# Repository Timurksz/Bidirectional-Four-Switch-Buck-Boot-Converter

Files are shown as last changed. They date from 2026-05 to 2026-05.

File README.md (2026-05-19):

This repository contains the design files and documentation for a 100W Bidirectional Four Switch Buck-Boost (FSBB) Converter, digitally controlled by the Texas Instruments UCD3138 microprocessor.

Featuring bidirectional energy transfer, this converter is ideal for battery management systems (BMS), automotive applications (48V/12V dual-battery systems), and renewable energy setups.

Project Overview

The topology is based on a non-isolated synchronous four-switch buck-boost converter, capable of operating in two primary modes:
- Buck Mode (48V → 12V): The high-voltage side supplies the low-voltage load.
- Boost Mode (12V → 48V): The low-voltage source transfers energy back to the 48V bus.

The system is digitally controlled using the UCD3138 microprocessor, enabling:
- Closed-loop voltage regulation
- PWM generation
- Bidirectional mode management
- Protection algorithms
- Real-time monitoring

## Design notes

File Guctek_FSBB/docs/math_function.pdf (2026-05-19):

Matematiksel Gösterimi

Klasik kontrol yöntemlerinde sistemler transfer fonksiyonları üzerinden analiz edilir. Ancak bu

yaklaşım, sistemin başlangıçtaki enerji durumunu (başlangıç koşullarını) sıfır kabul eder ve

yalnızca giriş-çıkış ilişkisine odaklanır. Gerçek dünyadaki karmaşık sistemlerde, sistemin iç

dinamiklerini ve başlangıçtaki fiziksel durumlarını hesaba katmak hayati önem taşır. Modern

kontrol teorisi, sistemi dışarıdan gözlemlemek yerine, sistemin içsel mekanizmalarını (iç

değişkenleri) matematiksel modele dahil ederek bu eksikliği giderir. Modern kontrolün

temelini, yüksek dereceli karmaşık denklemleri yönetilebilir parçalara ayırmak oluşturur. n.

dereceden bir diferansiyel denklemle ifade edilen bir sistem, modern teoride n adet birinci

dereceden diferansiyel denkleme dönüştürülür. Bu yapı, doğrusal dinamik sistemlerin vektör-

matris formunda gösterilmesini sağlar. Böylece durum uzay modeli vektör matris dormunda;

ⅆx
ⅆt
= Ax(t) + Bu(t) | (1)

yazılırlar. Çıkış denklemi ise;
y(t) = Cx(t) + Du(t) | (2)
ile verilir. Anxn, Bnxr, Cmxn, Dmxr | zamanla değişmeyen sistemler için sabit katsayı

matrisleridir. xnx1 durum vektörüdür. u(t) giriş/kontrol işaretidir. y(t) ise sistemin çıkış

vektörüdür. n. dereceden sistem analiz ve tasarımı bu denklem takımları üzerinden

yapılır. Modern kontrol teorisi olarak isimlendirilme nedeni olarak kısaca, durum uzay

denklemleri kullanılarak yapılan analiz ve tasarımlarda özellikle lineer cebir teknik ve

yöntemlerinin çok yaygın olarak kullanılması ve sürekli olarak geliştirilmesidir. Durum-

uzay analizinde dinamik sistem modellemesinde üç tip değişken göz önünde

bulundurulur:

- Giriş değişkenleri,
- Çıkış değişkenleri,
- Durum değişkenleri/İç değişkenler

Aynı bir sistem için tek bir durum-uzay gösterimi yoktur. Durum değişken sayısı aynı

kalmakla beraber aynı sistem için sonsuz sayıda durum-uzay gösterimi elde edilebilir. Bir

sisteme ait durum uzay gösterimi elde edilirken kullanılan yöntemlere ve kullanılabilecek

lineer dönüşümlere bağlı olarak farklı katsayılar matrisleri elde edilir. Ancak aynı bir

sistem için katsayılar matrisleri farklı olmakla beraber tek bir transfer fonksiyonu vardır

ve karakteristik denklemleri aynıdır. Eğer durum denklem elde etme yöntemi veya lineer

dönüşüm sonunda transfer fonksiyonu veya karakteristik denklem değişir ise o sistem artık farklı bir sistem demektir, hata yapılmıştır. Bu bilgiler göz önüne alınarak devre

analizi yapılır.

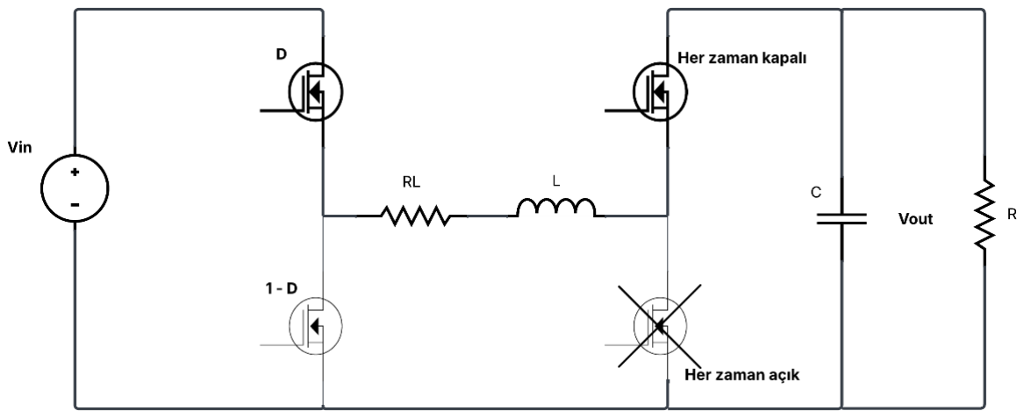
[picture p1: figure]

Şekil 1: Düşürücü Dönüştürücünün Anahtarı İletimde

Düşürücü devreden yapılan analizinden ve alınan Kirchhoff Çevre Gerilim Yasası’ndan;

Vin = lL ⋅ RL + L

ⅆIL
ⅆt
+ IR ⋅ R | (3)

olarak elde edilir. Kapasitör akımının da;

IC = C

ⅆVC ⅆt | (4)

olduğunu bilinmktedir. Vout ve VC parallel olduklarından dolayı eşittir ve;

VC = IR ⋅ R | (5)

veya

IR =

VC R | (6)

olarak yazılabilir Kirchhoff Düğüm Akım Yasası;
IR = IL − IC | (7)

elde edilir. Dolayısıyla kapasitor gerilimi;

C

ⅆVC ⅆt
= IL −
VC R | (8)

ⅆVC ⅆt
=

IL C
−
VC RC | (9)

olacaktır. Endüktör akımı ise;

L

ⅆIL
ⅆt
= Vin − lL ⋅ RL − VC | (10)

ⅆIL ⅆt
=

Vin L
−

lL⋅RL L
−
VC L | (11)

şeklinde olacaktır. Ve çıkış gerilimi de;

vout = VC | (12)

şeklinde olacaktır. Dolayısıyla sistem iletimde olduğu sürece;

[
ⅆIL
ⅆt
ⅆVC
ⅆt

] = [
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
RC] ⋅ [
IL
vc

] + [

1
L
0
] ⋅ Vin | (13)

ve
vout = y = [0 1][

IL
vc
] | (14)

ifadeleri elde edilir.

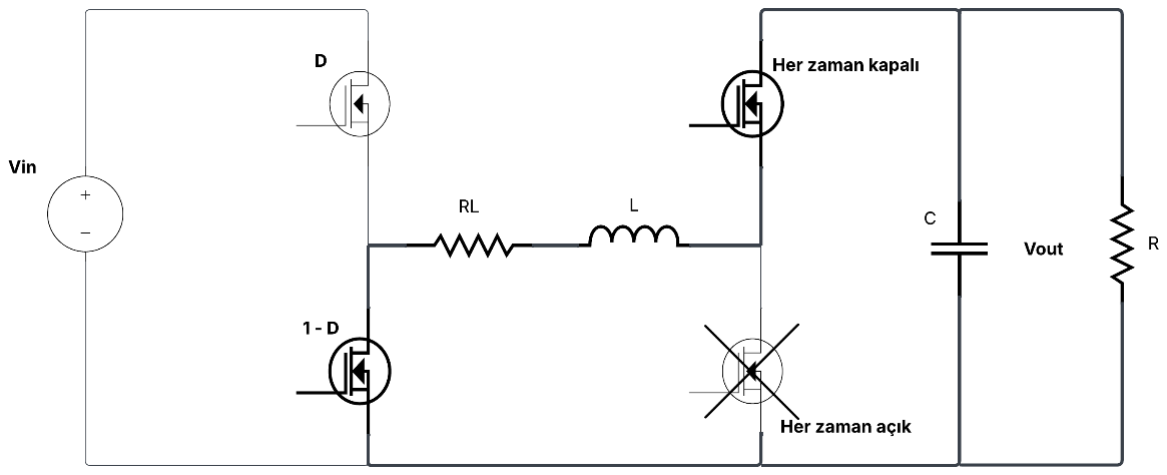
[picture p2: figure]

Sekil 2: Düşürücü Dönüştürücünün Anahtarı kesimde

Anahtarın kesime gittğinde ise Vin = 0 olup endüktör akımı;

ⅆIL
ⅆt

= −

lL⋅RL
L

−

VC
L

(15)

olarak, kapasitör gerilimi ise;

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
(16)

olarak elde edilir. Dolayısıyla;
[
ⅆIL
ⅆt
ⅆVC
ⅆt

] = [
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
RC] ⋅ [
IL
vc

] + [

0
0
] ⋅ Vin | (17)

ve
vout = y = [0 1][

IL
vc
] | (18)

ifadeleri elde edilir. Şimdi ise bu iki durum uzay modelinin ortalama bir model elde etmek için

bazı işlemlerin yapılması gerekmektedir.

Anahtarın iletimde olduğu ifadeleri d(t) ile, kesimde olduğu ifadeleri ise (1-d(t)) ile çarpıp

ardından ortalama durum uzay modeli çıkarılır. Iki durumların da çarpıldığı ve ortalama uzay

modeli çıkarıldığı zaman, aşağıdaki ortalama durum uzay modeli;
[
ⅆIL
ⅆt
ⅆVC
ⅆt

] = [
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
RC] ⋅ [
IL
vc

] + [

ⅆ(t)
L
0
] ⋅ Vin | (19)

ve
vout = y = [0 1][

IL
vc
] | (20)

olarak elde edilir. Her iki ifadenin çarpılıp topladıktan sonra, d(t) ve (1-d(t)) ifadelerin içinde

birbirlerini sadeleşmiş olacak. Anahtarın kesimde olduğuna Vin = 0 olacağı için, ortalama

durum uzay modelinde B matrisinin içerisinde ⅆ(t)
L

ifadesi kalacaktır.

Elde edilen ortalama durum uzay modelinde B matrisinin içerisinde d(t) değişkeni vardır.

Dolayısıyla bu değişken sabit olmadığında bu modeli doğrusal olmayan bir model yapar. Böyle

durumlarda da bir durum uzay modelinde sonsuz transfer fonksiyonu elde edilebilir. Sistemin

herhangi bir çalışma noktasında doğrusallaştırılmasıyla elde edilecek küçük sinyal durum uzay

modeli tek bir transfer fonksiyonuna sahip olacaktır ve bu transfer fonksiyonu ile sistemin o

çalışma noktasında analizi yapılabilir. Dolayısıyla düşürücü dönüştürücünün küçük sinyal

durum uzay modeli;
[

d̃IL
ⅆt
d̃Vc
ⅆt

] = [
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
RC] ⋅ [
IL

̃
Vc

̃

] + [

Vin
L
0
] ⋅ d̃(t) | (21)

ve
Ṽout = y = [0 1] ⋅ [
IL

̃
Vc

̃

] | (22)

şeklinde elde edilir. Küçük sinyal durum uzay modelinden düşürücü (buck) dönüştürücünün

trafnsfer fonksiyonunu (G(s));

G(s) = Vout ̃(s)
ⅆ̃(s)

= C ⋅ (sI − A)

−1
⋅ Bⅆ | (23)

formülü kullanılarak elde edilebilir. Küçük sinyal durum uzay modelinden; A = [
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
RC] | (24)

Bⅆ = [

Vin
L
0
] | (25)
C = [0 1] | (26)

olarak A, B ve C matrisi olarak elde edilir. Ve buradan;

Vout ̃(s)
ⅆ̃(s)

= C ⋅ (sI − A)

−1

⋅ Bⅆ = [0 1] ⋅ (s [
0 1
1 0

] − [
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
RC])

−1
⋅ [

Vin
L
0
] | (27)

olarak elde edilir. Bu dönüştürücünün küçük sinyal transfer fonksiyonu matlab kodu;

clear all, clc

format long

Vin= 48;

L= 150e-6;

RL=0.01;

C= 34.722e-6;

R=1.2;

A=[-RL/L -1/L; 1/C -1/(R*C)];

B=[Vin/L; 0];

C=[0 1];

D=[0];

[b,a] = ss2tf(A,B,C,D)

SYS = tf(b,a)

kullanılarak;

Vout ̃(s)
ⅆ̃(s)

=

9.216 × 10⁹

s

2 + s ⋅ 2.407 × 10⁴ + 1.936 × 10⁸

(29)

olarak bu alçaltıcı dönüştürücünün küçük sinyal transfer fonksiyonu elde edilir. Bu hesaplanan

transfer fonksiyon devrenin buck modunda çalşırken ki transfer fonksiyonu. Devreyi kontrol

etmek üzere iki PI kontrolcu tasarlanacak. Hem düşürücü hem de yükseltici modu için.

Dolayısıyla aynı işlemler yükseltici modu için de yapılıp ardından bu modun da transfer

fonksiyonu çıkarılır.

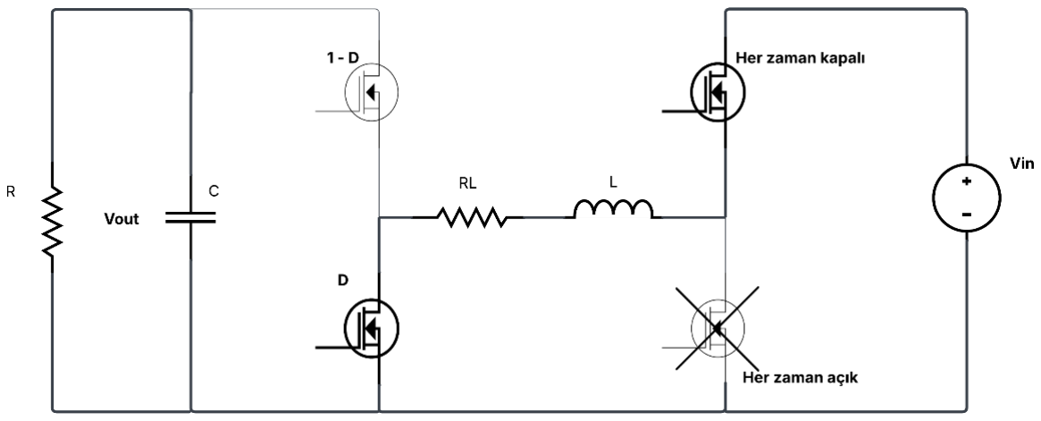
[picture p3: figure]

Şekil 3: Yükseltici Dönüştürücünün Anahtarı İletimde

Yükseltici devrenin Vout ile Vin bağıntısı;

vout

Vin

=

1
1−D

(29)

olarak elde edilir. Düşürücü devresinde de olduğu gibi bu devrede de anahtarın iletim ve

kesimde oldup her iki durumun da analiz edilmesi gerekmektedir. Dolayısıyla system

iletimdeyken endüktör akımı:

ⅆIL
ⅆt

=

Vin
L

−

lL⋅RL
L

(30)

olarak edle edilir. Kapasitör gerilimi ise:

ⅆVC
ⅆt

= −

VC
RC

(31)

şeklinde olduğunu gözükmektedir. Dolayısıyla
[
ⅆIL
ⅆt
ⅆVC
ⅆt

] = [
−

RL
L

0

0 −

1

RC] ⋅ [
IL
vc

] + [

1
L
0
] ⋅ Vin | (32)

ve
vout = y = [0 1][

IL
vc
] | (33)

elde edilir.

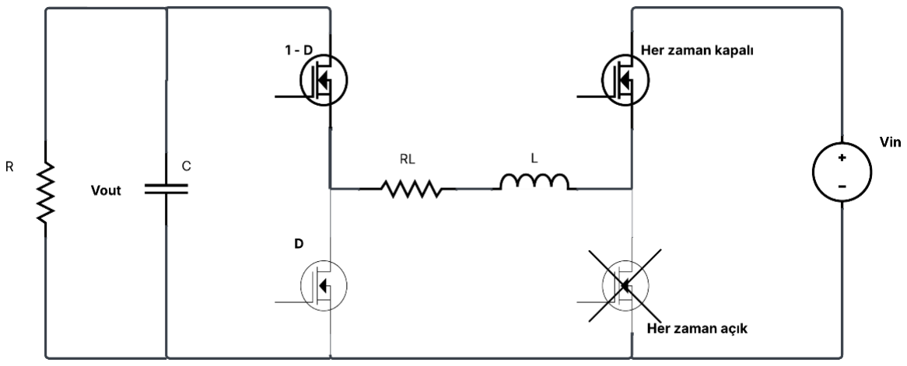
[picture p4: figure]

Şekil 4: Yükseltici Dönüştürücünün Anahtarı Kesimde

Dönüştürücünün anahtarı kesimde olduğunda ise endüktör akımı;

ⅆIL
ⅆt

=

Vin
L

−

lL⋅RL
L

−

vc
L

(34)

Elde edilir. Kapasitör gerilimi ise;

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
(35)

şeklinde elde edilir. Bu şekilde A matrisinde değişiklikler yaşanarak;

[
ⅆIL
ⅆt
ⅆVC
ⅆt

] = [
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
RC] ⋅ [
IL
vc

] + [

1
L
0
] ⋅ Vin | (36)

ve
vout = y = [0 1][

IL
vc
] | (37)

şeklinde ifadeler elde edileceğini gözükmektedir. Bir önceki sistemde de yapıldığı gibi burada

da ortalama durum uzay model elde edilebilmek için anahtarın iletimde olduğundaki matris

ifadeleri d(t) ile, kesimde olduğu ifadeleri ise (1-d(t)) ile çarpılır ve;
[

ⅆ̃IL

ⅆt
ⅆ̃Vc

ⅆt

] = [
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
RC ] ⋅ [
IL

̃
Vc

̃

] + [
Vo
L
−

IL
C
] ⋅ d̃(t) | (38)

ve
Ṽout = y = [0 1] ⋅ [
IL

̃
Vc

̃

] | (39)

olarak sistemin küçük sinyal durum uzay modeli elde edilir. D’ye göre türev alındıktan sonra

B matrisi yukarıdaki hali alır. Bu sistemin küçük sinyal durum uzay modeli A, B ve C

matrisleri;
A = [
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
RC ], | (40)

Bⅆ = [
Vout
L
−

IL

RC] | (41)

olarak elde edilir. Ayrıca;

IL =

Vout
(1−D)²⋅R

(42)

ve

vout =

Vin
(1−D)

(43)

olduğu bilinmektedir. Dolayısıyla; Bⅆ = [

Vin
L(1−D)
Vin
(1−D)²⋅RC] | (44)

ve
C = [0 1] | (45)

şeklinde olup bu sistemin;

Vout ̃(s)
ⅆ̃(s)

= C ⋅ (sI − A)

−1

⋅ Bⅆ = [0 1] ⋅ (s [
0 1
1 0

] − [
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
RC ])

−1
⋅ [

Vin
L(1−D)
Vin

(1−D)²⋅RC] (46)

olarak elde edilir. Dolayısıyla MATLAB kodu;

clear all, clc

format long

Vin= 12;

L= 150e-6;

RL=0.01;

C= 260e-6;

R=19.2;

d=0.75;

A=[-RL/L -(1-d)/L; (1-d)/C -1/(R*C)];

B=[Vin/((1-d)*L); -Vin/((1-d)^2*R*C)];

C=[0 1];

D=[0];

[b,a] = ss2tf(A,B,C,D)

SYS = tf(b,a)

kullanılarak;

Vout ̃(s)
ⅆ̃(s)

=

−3.846 × 10⁴

⋅ s + 3.051 × 10⁸

s

2 + s ⋅ 267 + 1.616 × 10⁶

(47)

yükseltici dönüştürücünün küçük sinyal transfer fonksiyonu elde edilir.

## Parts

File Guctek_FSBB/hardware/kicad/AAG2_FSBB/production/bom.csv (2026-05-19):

Designator | Footprint | Quantity | Value | LCSC Part #
+12V, +12V_X, +3V3, +V1, +V2, AGND, H1_2, H2_2, L1, L2_2, PGND, SENS_1, SENS_2, SW1, SW2, V1+ | TestPoint_Pad_1.0x1.0mm | 16 | TestPoint
C1, C2, C3, C4, C5, C6, C7, C8 | 2220 | 8 | 10uF
C10 | CAPAE1300X1380N | 1 | 100uF
C11, C12 | 0603 | 2 | 6800pF
C13, C14, C21, C24, C27, C28 | 0603 | 6 | 22pF
C15, C16, C42, C43, C44 | 0603 | 5 | 100nF
C17, C18 | 0603 | 2 | 330pF
C19, C29 | 0805 | 2 | 4u7F
C20, C22, C51, C54, C56, C57 | 0603 | 6 | 2u2F
C23, C30 | 1206 | 2 | 2u2F
C25, C66 | 0603 | 2 | 220pF
C26, C40, C47, C53, C60 | 0603 | 5 | 10nF
C31, C37 | 0603 | 2 | 1uF 50V
C32, C36 | 0805 | 2 | 10uF
C33 | 0603 | 1 | 10uF
C34 | 0805 | 1 | 47uF
C35 | 0805 | 1 | 22uF
C38, C39 | 1210 | 2 | 2u2F
C41, C45, C52 | 0603 | 3 | 1uF
C46 | 0603 | 1 | 2n2F
C48 | 0603 | 1 | 3n3F
C49 | 0603 | 1 | 56pF
C50 | 1210 | 1 | 22uF
C55, C59 | 0603 | 2 | 33pF
C58, C64 | 1210 | 2 | 4u7F
C61, C65 | 1206 | 2 | 1uF
C9 | EEEFK0J332AQ | 1 | 220uF
D1, D2, D3, D4 | D_SOD-123 | 4 | MBR0540T1G
D10, D11, D12 | 0805 | 3 | LED
D13, D14 | SODFL3616X98N | 2 | MBR1H100SFT3G
D5, D6 | D_SMA | 2 | SS16
D7 | DIONM7959X262N | 1 | SS510
F1, F2 | SS_BEL | 2 | 15A
J1, J3 | ED1202DS | 2 | Conn_01x02
J5 | PinHeader_1x05_P1.00mm_Vertical | 1 | Conn_01x05
J6 | 5103308-1 | 1 | 5103308-1
J7 | PinHeader_01x02_P2.54mm_Vertical_THT_D1mm | 1 | Conn_01x02
L1_2 | SER2918H333KL | 1 | SER2918H-153KL
L2 | SRP1265A | 1 | SRP1265A-220M
Q1, Q2, Q3, Q4 | TO-263-6 | 4 | IPB180N10S4-02
Q5, Q8 | SOIC127P600X175-8N | 2 | AO4406A
Q6, Q7 | SOT-23 | 2 | MMBT3904
R1, R2 | 0603 | 2 | 41k2
R10, R9 | 0603 | 2 | 1k10
R11, R12, R3, R4, R48, R54, R55 | 0603 | 7 | 10k
R13, R14 | 2512 | 2 | 0.002
R15, R20 | 0603 | 2 | 120
R16, R19, R25, R26 | 0603 | 4 | 120k
R17, R18, R21, R22, R23, R24, R34, R49, R50 | 0603 | 9 | 1k
R28 | 0603 | 1 | 2k03
R29, R30 | 0603 | 2 | 31k6
R31 | 0603 | 1 | 100k
R32 | 0603 | 1 | 3k74
R33, R35 | 0603 | 2 | 453k
R36 | 0603 | 1 | 49k9
R38 | 0603 | 1 | 1R
R40, R46, R47, R51 | 0603 | 4 | 100
R45, R56, R57 | 0603 | 3 | 2k2
R5, R6, R7, R8 | 0805 | 4 | 5R11
R52, R53 | 0603 | 2 | 3k16
S1 | G12AP | 1 | G12AP
SW2_2, SW3, SW4 | SKRKAEE010 | 3 | SKRKAEE010
U1, U4 | DRM8_3P38X2P45_TEX | 2 | UCC27211ADRMR
U2, U3 | SOIC127P600X170-9N | 2 | OPA2211AIDDA
U5 | SOT230P700X180-4N | 1 | TLV1117-33IDCY
U6 | SOIC127P600X170-9N | 1 | LM5013DDAR
U7 | UCD3138RJAT | 1 | UCD3138RJAT
U8, U9 | TSOT-23-6 | 2 | LM5050-1

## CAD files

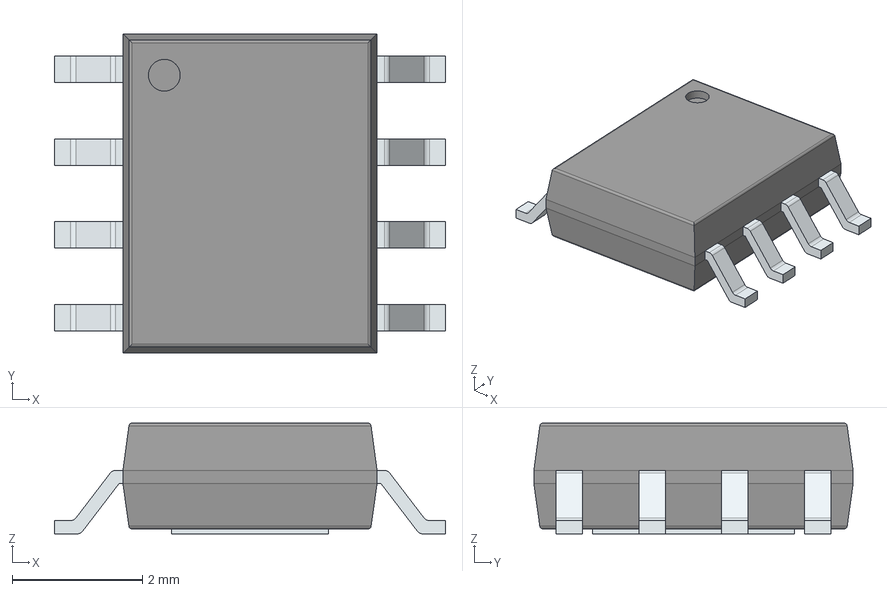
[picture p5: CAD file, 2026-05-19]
Guctek_FSBB/hardware/symbol_footprint_step/step/LM5013DDAR.stp
6.00 x 4.90 x 1.70 mm
PinsArrayLR
ThermalPad

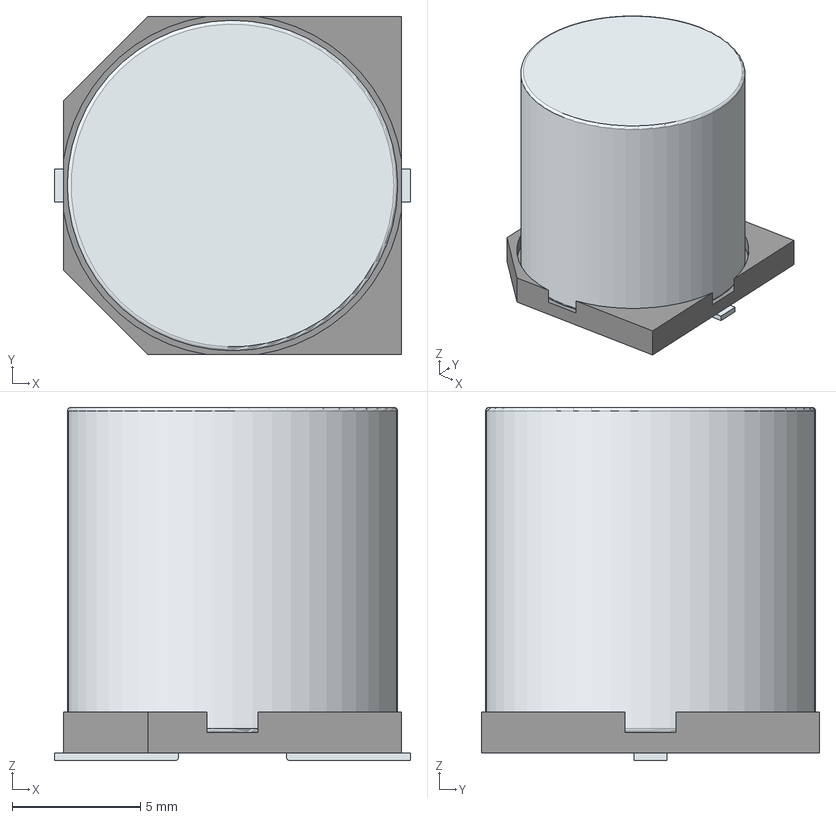
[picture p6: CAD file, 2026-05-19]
Guctek_FSBB/hardware/symbol_footprint_step/step/EMVE101ARA101MKE0S.stp
13.9 x 13.2 x 13.8 mm
Base
Pin1Fillet
Pin2Fillet

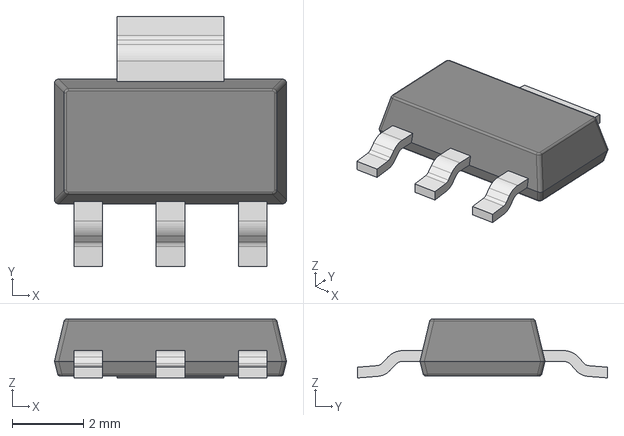
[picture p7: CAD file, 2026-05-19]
Guctek_FSBB/hardware/symbol_footprint_step/step/TLV1117-33IDCY.stp
6.50 x 7.00 x 1.65 mm

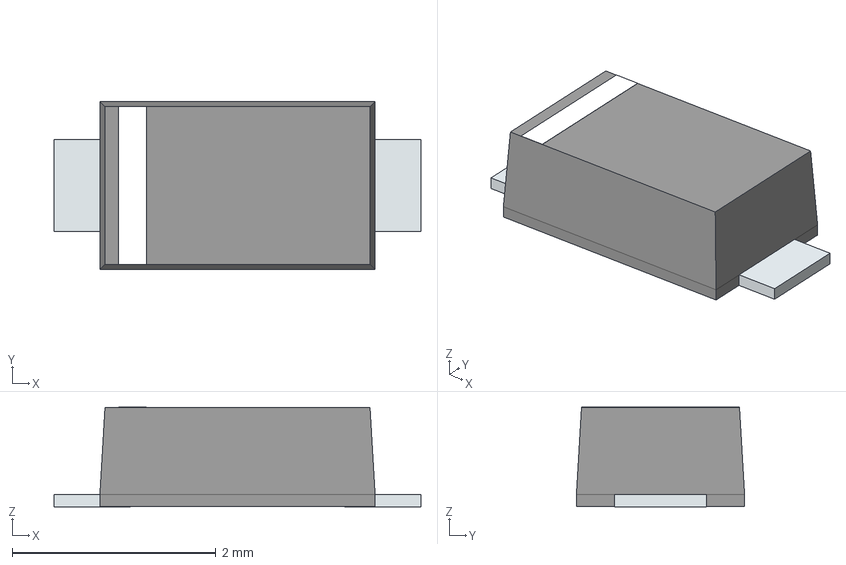
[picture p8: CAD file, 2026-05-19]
Guctek_FSBB/hardware/symbol_footprint_step/step/MBR1H100SFT3G.stp
3.60 x 1.65 x 0.98 mm
PinKIdent
PinK
PinA

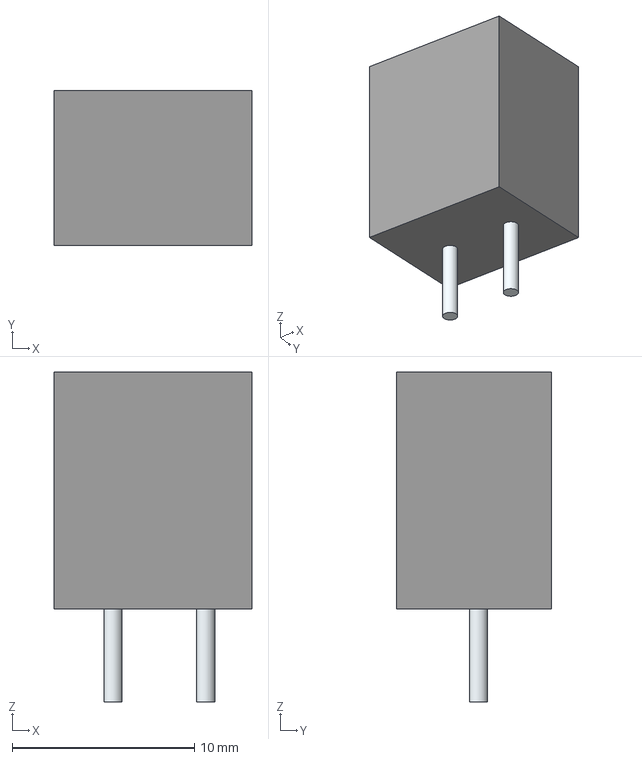
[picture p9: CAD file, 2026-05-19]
Guctek_FSBB/hardware/symbol_footprint_step/step/ED120_2DS.stp
10.9 x 8.50 x 18.1 mm
Leads x 2

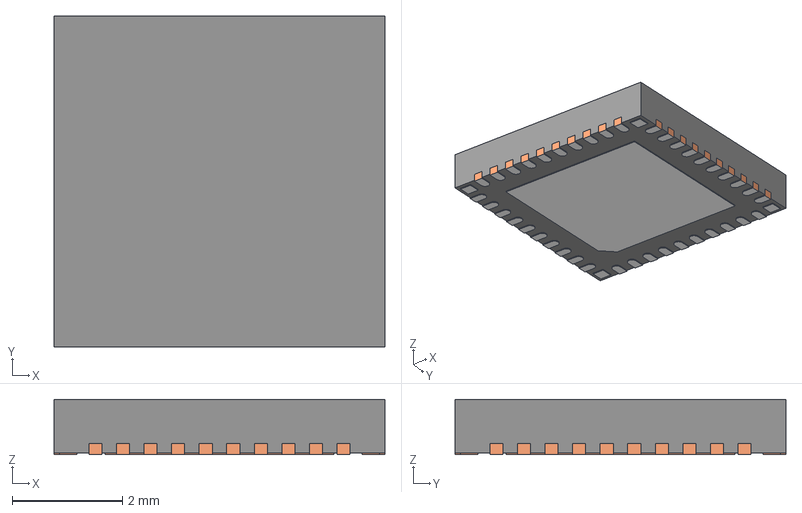
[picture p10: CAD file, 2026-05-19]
Guctek_FSBB/hardware/symbol_footprint_step/step/UCD3138RJAT.stp
6.00 x 6.00 x 1.00 mm
BODY-QFN
FRAME-RJA0040A
PIN1-ID

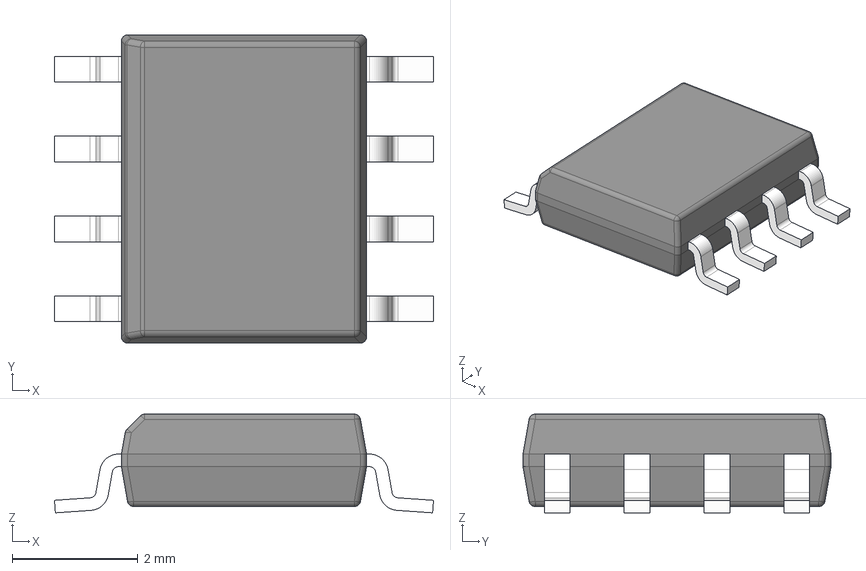
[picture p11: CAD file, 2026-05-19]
Guctek_FSBB/hardware/symbol_footprint_step/step/OPA2211AIDDA.stp
6.03 x 4.90 x 1.57 mm
BODY-SO
LEAD-SO x 8
THERMALPAD-SO

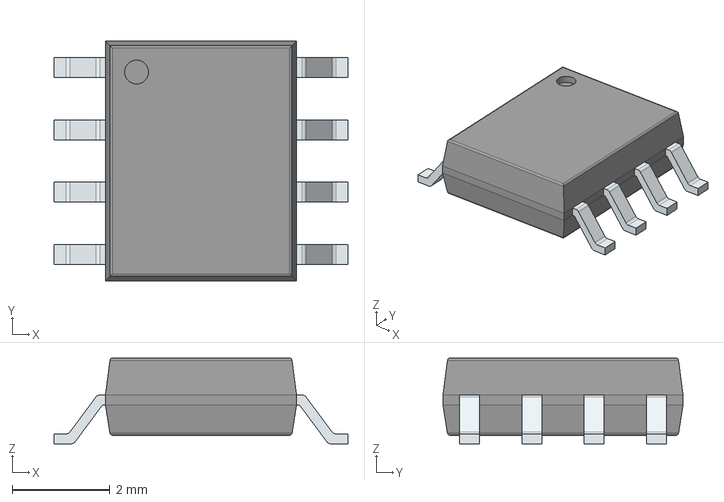
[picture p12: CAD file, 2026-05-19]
Guctek_FSBB/hardware/symbol_footprint_step/step/AO4406A.stp
6.00 x 4.90 x 1.75 mm
PinsArrayLR

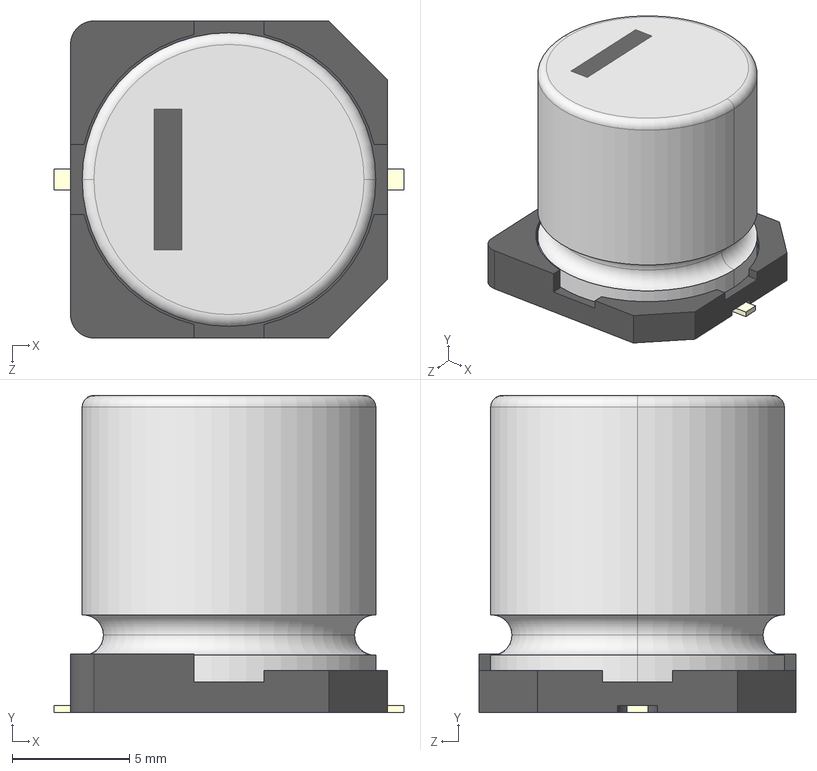
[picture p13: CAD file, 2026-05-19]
Guctek_FSBB/hardware/symbol_footprint_step/step/EEE-TK1J221AQ.stp
14.9 x 13.5 x 13.5 mm
標準SIZE CODE H13-001
標準SIZE CODE H13-002
標準SIZE CODE H13-003 x 2

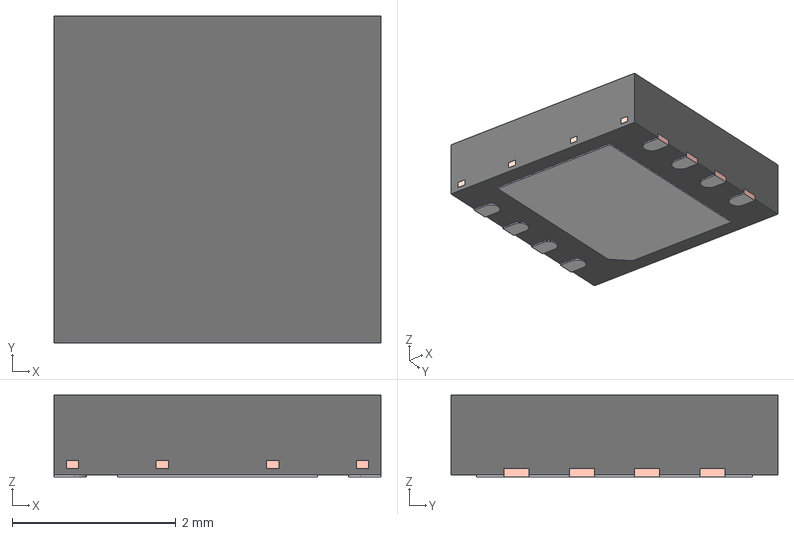
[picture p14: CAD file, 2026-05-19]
Guctek_FSBB/hardware/symbol_footprint_step/step/DRM0008A.stp
4.00 x 4.00 x 1.00 mm
DRM0008A_FRAME
DRM0008A_BODY
DRM0008A_PIN1_AREA

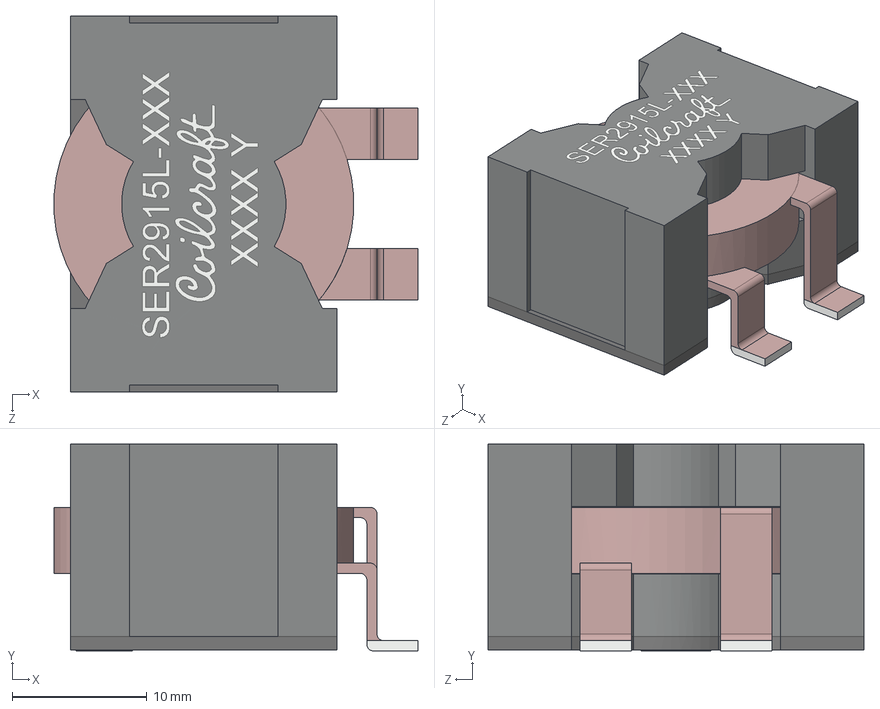
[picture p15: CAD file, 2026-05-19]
Guctek_FSBB/hardware/symbol_footprint_step/step/SER2918H-153KL.stp
27.0 x 15.4 x 27.9 mm

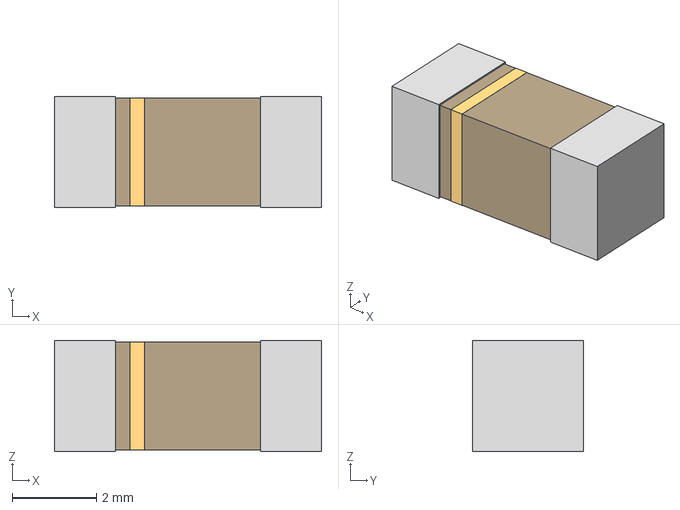
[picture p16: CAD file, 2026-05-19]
Guctek_FSBB/hardware/symbol_footprint_step/step/SS_BEL.step
6.35 x 2.64 x 2.64 mm

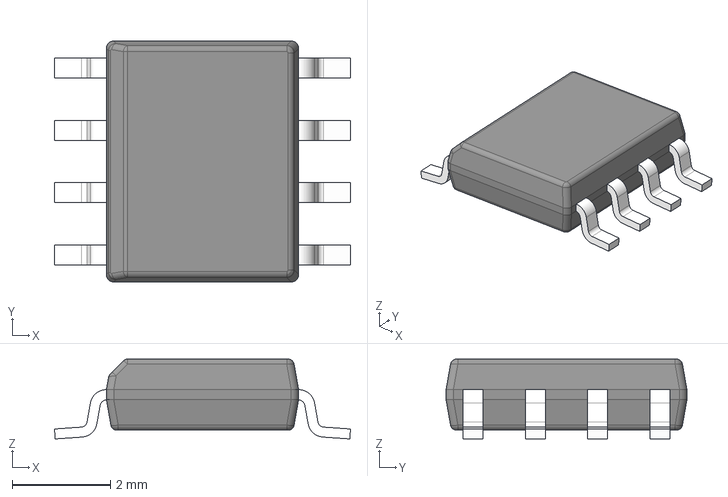
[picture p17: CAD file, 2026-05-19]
Guctek_FSBB/hardware/symbol_footprint_step/step/UCC2813DTR-1.stp
6.02 x 4.90 x 1.63 mm
BODY-SO
LEAD-D0008A x 8

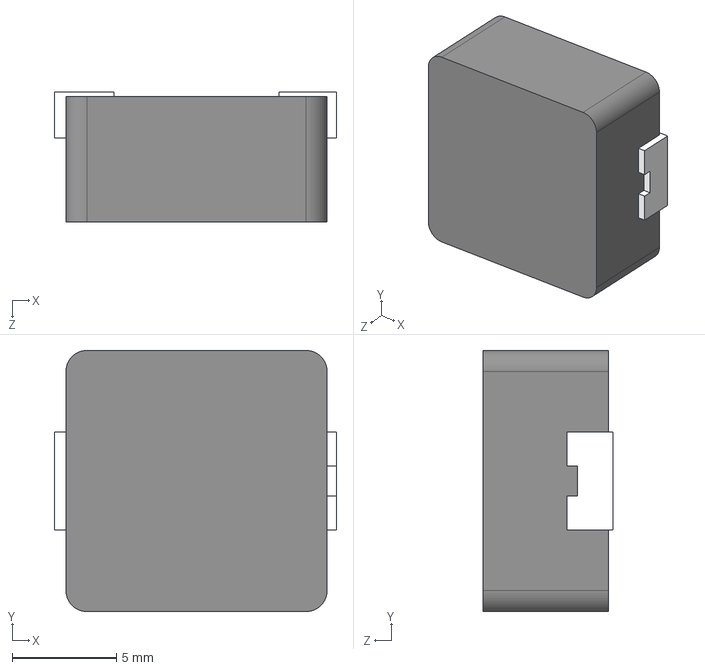
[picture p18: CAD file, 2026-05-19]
Guctek_FSBB/hardware/symbol_footprint_step/step/SRP1265A-220M.stp
13.5 x 12.5 x 6.20 mm

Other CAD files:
Guctek_FSBB/hardware/symbol_footprint_step/step/G12AP.stp
Guctek_FSBB/hardware/symbol_footprint_step/step/SKRKAEE010.stp
Guctek_FSBB/hardware/symbol_footprint_step/step/SS510.stp
Guctek_FSBB/hardware/symbol_footprint_step/step/5103308-1.step

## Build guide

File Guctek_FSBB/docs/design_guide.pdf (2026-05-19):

## TEKNOLOJİ FAKÜLTESİ

ELEKTRİK-ELEKTRONİKMÜHENDİSLİĞİ BÖLÜMÜ

EEM TASARIMI RAPORU

# KONU: Mild-hibrit araçlar için 48V-12V bataryalar arası çift yönlü dijital kontrollü DA-DA dönüştürücü tasarımı

G210101042 Mustafa KILINÇKIRAN B210101004 Timur ÖKSÜZ
B210101552 Xhelil VEHAPI

## Dr. Öğr. Üyesi ALİ KUYUMCU

Ocak 2026

SAKARYA

ii

ELEKTRİK ELEKTRONİK MÜHENDİSLİĞİ LİSANS TASARIMI

ONAY FORMU

Mustafa KILINÇKIRAN, Timur ÖKSÜZ, Xhelil VEHAPI tarafından Arş. Gör. Dr. ALİ KUYUMCU yönetiminde hazırlanan “Mild-hibrit araçlar için 48V-12V bataryalar arası çift yönlü dijital kontrollü DA-DA dönüştürücü tasarımı” başlıklı Tasarım Çalışması tarafımızdan kapsamı ve niteliği açısından incelenerek kabul edilmiştir.

Danışman | : Dr. Öğr. Üyesi Ali KUYUMCU
Jüri Üyesi 1 | : Dr. Öğr. Üyesi İlker DURSUN
Jüri Üyesi 2 | : Arş. Gör. Nurbağnu POLAT
Bölüm Başkanı | : Prof. Dr. İhsan PEHLİVAN

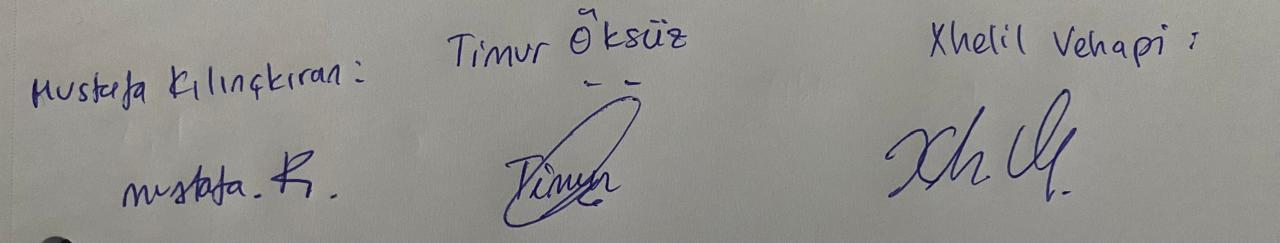
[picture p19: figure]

iii

BEYAN

Bu tez çalışmasının, bilimsel etik kurallarına, akademik dürüstlük ilkelerine ve IEEE Etik Kurallarına uygun biçimde tarafımdan hazırlandığını beyan ederim.

Çalışma süresince kullanılan tüm kaynaklara uygun biçimde atıf yapılmış, başkalarının çalışmalarından izinsiz yararlanılmamış ve hiçbir bölüm başka bir tez veya çalışma üzerinden kopyalanmamıştır.

Araştırma sürecinde ayrımcılıktan uzak, tarafsız ve kapsayıcı bir yaklaşım benimsenmiş; farklı görüşlere saygı gösterilmiş ve tüm ekip üyelerinin eşit katkı yapma fırsatı bulması sağlanmıştır.
Ayrıca, IEEE Etik Kuralları doğrultusunda; mesleki sorumluluk bilinciyle hareket edildiğini, kamu yararı gözetilerek doğruluk, dürüstlük, gizlilik ve adil davranış ilkelerine bağlı kalındığını taahhüt ederim.

Bu tez tamamen kendi özgün çalışmam olup, tüm sorumluluğu tarafıma aittir.

24/01/2026

Mustafa KILINÇKIRAN
Timur ÖKSÜZ
Xhelil VEHAPI

İmza

iv

### ÖNSÖZ

Bu çalışma, Sakarya Uygulamalı Bilimler Üniversitesi Teknoloji Fakültesi Elektrik-

Elektronik Mühendisliği Bölümü bünyesinde yürütülen EEM Tasarımı Çalışması

kapsamında hazırlanmıştır.

Çalışmanın her aşamasında bilgi ve tecrübeleriyle yol gösteren, değerli önerileri ve katkılarıyla çalışmanın şekillenmesinde önemli rol oynayan danışman hocamız Dr. Öğr.

Üyesi Ali KUYUMCU’ya içten teşekkürlerimi sunarız.

Ayrıca, eğitim sürecim boyunca gerek teorik gerek uygulamalı dersler ile mesleki

gelişimime katkı sağlayan Elektrik-Elektronik Mühendisliği Bölümü öğretim

elemanlarına, çalışmanın yürütülmesi sırasında bölüm olanaklarının kullanılmasına

imkân tanıyan Elektrik-Elektronik Mühendisliği Bölüm Başkanlığına, sağladıkları

desteklerden dolayı Teknoloji Fakültesi Dekanlığına ve Sakarya Uygulamalı Bilimler Üniversitesi Rektörlüğüne teşekkür ederiz.

VE eğitim hayatımız boyunca maddi ve manevi desteklerini hiçbir zaman esirgemeyen,

her koşulda yanımızda olan ailelerimize sonsuz teşekkürlerimizi sunarız.

Ocak 2026

Sakarya

Mustafa KILINÇKIRAN
Timur ÖKSÜZ
Xhelil VEHAPI

v

### İçindekiler

vi

vii

ÖZET

Bu çalışmada, mild-hibrit elektrikli araçlarda kullanılan 48V–12V gerilim seviyeleri

arasında enerji aktarımına uygun, yüksek verimli, düşük maliyetli ve güvenilir bir dört

anahtarlı çift yönlü (buck–boost) DA–DA dönüştürücü tasarımı ve uygulaması

gerçekleştirilmiştir.

Günümüzde hibrit ve elektrikli araçlarda farklı gerilim seviyelerinde çalışan sistemlerin

enerji paylaşımı önemli bir gereksinimdir. Geleneksel tek yönlü dönüştürücülerle tam

olarak karşılanamayan bu ihtiyaç, verim kayıplarına ve maliyet artışlarına neden

olmaktadır. Bu çalışma ile 48V’luk mild-hibrit batarya sistemiyle 12V’luk yardımcı

yükler arasında çift yönlü enerji akışını sağlayabilen, kompakt ve verimli bir çözüm

sunulmuştur. Tasarlanan dönüştürücüde dört anahtarlı topoloji kullanılmış, böylece

sistemin hem buck (düşürücü) hem de boost (yükseltici) modlarında çalışması

sağlanmıştır.

Sistem performansını artırmak amacıyla uygun MOSFET sürücü devresi, PWM kontrol

algoritması ve akım/gerilim geri besleme yapıları tasarlanmıştır. Sistemin koruma ve

kontrol özellikleri artırılarak, otomotiv standartlarına uygun güvenilir bir yapı elde

edilmiştir. Çalışma sonucunda geliştirilen dönüştürücünün, enerji dönüşümünü optimize

ederek batarya ömrünü uzattığı ve güç kayıplarını azalttığı gözlemlenmiştir. Yapılan

testlerde %90 verime ulaşılmış ve gerilim dalgalanması %2 seviyesinde tutulmuştur.

Böylece enerji verimliliğine ve sürdürülebilir ulaşım teknolojilerine katkı sağlanmıştır.

Anahtar Kelimeler: Mild-hibrit elektrikli araçlar, Çift yönlü dönüştürücü, Dört anahtarlı

buck boost

viii

SUMMARY

In this study, the design and implementation of a high-efficiency, low-cost, and reliable

four-switch bidirectional buck–boost DC–DC converter suitable for 48V–12V energy

transfer used in mild-hybrid electric vehicles have been realized.

Today, energy sharing between systems operating at different voltage levels in hybrid and

electric vehicles is a significant requirement. This need, which cannot be fully met by

traditional unidirectional converters, causes efficiency losses and cost increases. With this

study, a compact and efficient solution capable of providing bidirectional energy flow

between the 48V mild-hybrid battery system and 12V auxiliary loads has been presented.

A four-switch topology has been used in the designed converter, thereby enabling the

system to operate in both buck and boost modes.

Appropriate MOSFET driver circuits, PWM control algorithms, and current/voltage

feedback structures have been designed to enhance system performance. By increasing

the protection and control features of the system, a reliable structure complying with

automotive standards has been obtained. As a result of the study, it has been observed that

the developed converter extends battery life by optimizing energy conversion and reduces

power losses. In the tests performed, 90% efficiency was achieved and voltage fluctuation

was kept at 2% levels. Thus, a contribution to both energy efficiency and sustainable

transportation technologies has been provided.

Keywords: Mild-hybrid electric vehicles, Bidirectional converter, Four-switch buck

boost

ix

SEMBOLLER LİSTESİ

A, B,C, D: Durum Uzay Model Matrisleri

C: Kapasitans (Kondansatör Değeri)

Cout: Çıkış Kapasitansı

D: Görev Döngüsü (Duty Cycle)

e(t): Hata Sinyali

fs
: Anahtarlama Frekansı

G(s): Transfer Fonksiyonu

I: Akım

IC: Kapasitör Akımı

IL
: Endüktans (Bobin) Akımı

Irms: Etkin Akım (Root Mean Square)

Isat: Doyum Akımı (Saturation Current)

Ki

: İntegral Kazanç Katsayısı

Kp: Oransal Kazanç Katsayısı

L: Endüktans (Bobin Değeri)

P: Güç

Pcond: İletim Kayıpları

Qg: Toplam Gate Yükü

Qgd: Gate-Drain Yükü

R: Yük Direnci

RDC: Bobin DC Direnci

RDS(on)

: Drain-Source İletim Direnci

RL

: Bobin İç Direnci (Simülasyon Modeli)

s: Laplace Operatörü

TA: Ortam Sıcaklığı

t: Zaman

u(t): Kontrol Giriş İşareti

V: Gerilim

Vd: Kontrol Sinyali

VDS: Drain-Source Gerilimi

x

Vess: Kalıcı Durum Hatası / Hata Sinyali

VGS: Gate-Source Gerilimi

VGS(th)
: Eşik Gerilimi (Threshold Voltage)

Vin/Vi
: Giriş Gerilimi

Vout/Vo: Çıkış Gerilimi

Vref: Referans Gerilim

x(t): Durum Vektörü

y(t): Çıkış Vektörü

ΔIL
: Bobin Akım Dalgalanması (Ripple)

ΔVout: Çıkış Gerilim Dalgalanması (Ripple)

xi

KISALTMALAR LİSTESİ

ADC: Analog-Dijital Dönüştürücü (Analog to Digital Converter)

AEC: Otomotiv Elektroniği Konseyi (Automotive Electronics Council) AFE: Analog Ön Uç (Analog Front End)

ARM: Gelişmiş RISC Makinesi (İşlemci Mimarisi)

BM: Birleşmiş Milletler
CISPR: Uluslararası Radyo Girişim Özel Komitesi

DA-DA: Doğru Akım-Doğru Akım (DC-DC)

DAB: Dual Active Bridge (Çift Aktif Köprü)
DCR: Doğru Akım Direnci (Bobin İç Direnci)

DNP: Do Not Populate (Montajı Yapılmayacak Bileşen)

DPWM: Dijital Darbe Genişlik Modülasyonu

DSC: Dijital Sinyal Kontrolcüsü

EEM: Elektrik-Elektronik Mühendisliği

EMC: Elektromanyetik Uyumluluk

ESCI: Emerging Sources Citation Index

FET: Alan Etkili Transistör (Field Effect Transistor)

FSBB: Four-Switch Buck-Boost (Dört Anahtarlı Alçaltıcı-Yükseltici)

GPIO: Genel Amaçlı Giriş/Çıkış (General Purpose Input/Output)

GUI: Grafiksel Kullanıcı Arayüzü

HRPWM: Yüksek Çözünürlüklü PWM

IEEE: Elektrik ve Elektronik Mühendisleri Enstitüsü

IPC: Printed Circuits Institute (Baskı Devre Standartları Enstitüsü)

ISO: Uluslararası Standartlar Teşkilatı

ISR: Kesme Servis Rutini (Interrupt Service Routine)

JTAG: Joint Test Action Group (Hata Ayıklama Arayüzü) LLC: İndüktör-İndüktör-Kapasitör (Rezonans Topolojisi)

LV: Düşük Voltaj (Low Voltage)

MATLAB: Matrix Laboratory (Simülasyon Yazılımı)
MCU: Mikrodenetleyici Ünitesi

MHEV: Mild-Hibrit Elektrikli Araç (Mild-Hybrid Electric Vehicle) MOSFET: Metal Oksit Yarı İletken Alan Etkili Transistör

OVP: Aşırı Gerilim Koruması (Over Voltage Protection)

xii

PCB: Baskı Devre Kartı (Printed Circuit Board)
PI: Oransal-İntegral Denetleyici (Proportional-Integral)

PID: Oransal-İntegral-Türev Denetleyici

PLECS: Piecewise Linear Electrical Circuit Simulation

PMBus: Güç Yönetimi Veri Yolu (Power Management Bus)

PWM: Darbe Genişlik Modülasyonu (Pulse Width Modulation)

RoHS: Tehlikeli Maddelerin Kısıtlanması Direktifi

SCI: Science Citation Index

SMD: Yüzey Montaj Elemanı (Surface Mount Device)

SMPS: Anahtarlamalı Güç Kaynağı

TMMOB: Türk Mühendis ve Mimar Odaları Birliği

UART: Evrensel Asenkron Alıcı-Verici

V2G: Araçtan Şebekeye (Vehicle to Grid)

V2I: Araçtan Altyapıya (Vehicle to Infrastructure)

VDA: Alman Otomotiv Endüstrisi Birliği (Verband der Automobilindustrie)

WEEE: Atık Elektrikli ve Elektronik Eşyalar

xiii

ŞEKİLLER LİSTESİ

Şekil 2.1: 48V ve 12V batarya bankaları arasında çift yönlü güç akışını sağlayan

dönüştürücü topolojisi | | 8
Şekil 2.2: Düşürücü (buck) modu akım yolu | | 9
Şekil 2.3: Yükseltici (boost) modu akım yolu | | 9
Şekil 3.2: UCD3138RGC (64-Pin) Pin Fonksiyonları | | 15
Şekil 3.3: CSD19535KCS mosfet görünümü | | 16
Şekil 3.5: UCC27211ADRMR örnek uygulama devresi | | 17
Şekil 3.6: Projede mosfet sürücü entegresinin uygulanması | | 18
Şekil 3.7: Wurth Elektronik 7443641000 bobin | | 19
Şekil 3.8: Seçilen Güç İndüktörünün Akım-Sıcaklık Artışı (Temperature Rise)
Karakteristik Eğrisi | | 20
Şekil 3.9:OPA2211AIDDA OPAMP | | 21
Şekil 3.10: Düşürücü Dönüştürücünün Anahtarı İletimde | | 25
Sekil 3.11: Düşürücü Dönüştürücünün Anahtarı Kesimde | | 26
Şekil 3.12: Düşürücü Modu Küçük Sinyal TF. Basamak Cevabı | | 29
Şekil 3.13: Yükseltici Dönüştürücünün Anahtarı İletimde | | 29
Şekil 3.14: Yükseltici Dönüştürücünün Anahtarı Kesimde | | 30
Şekil 3.15: Yükseltici Modu Küçük Sinyal TF. Basamak Cevabı | | 23
Şekil 3.16: : Kontrol Sisteminin Blok Diyagramı | | 33
Şekil 3.17: Buck Dönüştürücünün Açık Çevrim Faz ve Kazanç Marjini | | 35
Şekil 3.18: Buck Dönüştürücünün Açık Çevrim Faz ve Kazanç Marjini | | 35
Şekil 3.19: Yazılım Akış Şeması | | 37

Şekil 4.1: Dört Anahtarlı Dönüştürücünün Düşürücü (buck) modda çalışmasının

PLECS Simülasyonu | | 45
Şekil 4.2: Düşürücü gerçek sistemi ile elde edilen TF. karşılaştırılması | | 45
Şekil 4.3: Düşürücü Modu Yük Gerilimi | | 46
Şekil 4.4: Düşürücü Modu Endüktans Akımı | | 46
Şekil 4.5: Kullanılan Kontrol Bloğu | | 47
Şekil 4.6: PI Denetleyici kullanılarak Alçaltıcı Modu Yük Gerilimi | | 47

Şekil 4.1: Dört Anahtarlı Dönüştürücünün Yükseltici (boost) modda çalışmasının

PLECS Simülasyonu | 48

xiv

xv

TABLOLAR LİSTESİ

xvi

GİRİŞ

### 1.1. Genel Bilgiler

Elektrikli ve hibrit araç teknolojilerinin hızla gelişmesiyle birlikte, enerji yönetimi ve güç

elektroniği sistemlerinin araç performansı, batarya ömrü ve çevresel sürdürülebilirlik üzerindeki etkisi giderek artmaktadır. Özellikle mild hibrit araç mimarilerinde yaygın

olarak kullanılan 48 V – 12 V çift batarya yapısında, farklı gerilim seviyelerine sahip

sistemler arasında gerçekleştirilen enerji transferinin verimli, güvenli ve esnek bir şekilde

sağlanması kritik bir gereklilik hâline gelmiştir. 48 V batarya marş-jeneratör, rejeneratif

frenleme ve yüksek güçlü yardımcı sistemlerde kullanılırken, 12 V batarya aydınlatma,

gövde elektroniği ve bilgi-eğlence sistemleri gibi düşük güçlü yükleri beslemektedir. Bu

iki batarya arasındaki güç akışının yetersiz veya kontrolsüz olması durumunda, enerji

kayıpları artmakta, batarya ömrü kısalmakta ve araç genel verimliliği olumsuz

etkilenmektedir. Bu çalışma, söz konusu problemi çözmek amacıyla mild hibrit araçlarda

48 V ve 12 V batarya sistemleri arasında çift yönlü enerji transferi sağlayabilen, dijital

kontrollü bir DA-DA dönüştürücü tasarımını ele almaktadır. Geliştirilecek sistem

sayesinde rejeneratif frenleme sırasında geri kazanılan enerjinin düşük voltajlı bataryaya

yüksek verimle aktarılması, ters yönde ise yardımcı sistemlerin ihtiyaç duyduğu gücün

48 V bataryadan güvenli bir şekilde sağlanması hedeflenmektedir. Küresel ölçekte artan

karbon emisyonları ve fosil yakıt bağımlılığı, otomotiv sektörünü daha verimli ve çevreci

çözümler geliştirmeye yönlendirmekte; bu bağlamda mild hibrit araçlar, tam elektrikli

araçlara geçiş sürecinde önemli bir ara teknoloji olarak öne çıkmaktadır. Ancak

literatürde yer alan mevcut çift yönlü DA-DA dönüştürücü tasarımlarının büyük bir kısmı

analog veya sabit kontrol yöntemlerine dayanmakta, değişken sürüş ve yük koşullarına

yeterince uyum sağlayamamakta ve istenen verimlilik seviyelerine ulaşamamaktadır.

Dijital kontrol tekniklerinin sunduğu gerçek zamanlı izleme, adaptif kontrol ve yazılım

tabanlı optimizasyon imkânları dikkate alındığında, bu alanda geliştirilecek yeni ve

yüksek verimli bir dönüştürücü tasarımının hem akademik hem de endüstriyel açıdan

önemli katkılar sunacağı değerlendirilmektedir. Ayrıca çift yönlü DA-DA dönüştürücüler

yalnızca mild hibrit araçlarda değil; tam elektrikli araçlar, enerji depolama sistemleri,

mikro şebekeler, kesintisiz güç kaynakları ve yenilenebilir enerji uygulamalarında da

yaygın olarak kullanılmakta olup, otomotiv sektöründe enerji geri kazanımını artırarak

yakıt tüketimi ve emisyonların azaltılmasında temel bir rol üstlenmektedir.

### 1.2. Literatür Araştırması

Bu çalışma kapsamında IEEE Xplore Digital Library, TÜBİTAK Turkish Journal of

Electrical Engineering & Computer Sciences ve YÖK Tez Kütüphanesi veritabanlarında

kapsamlı bir literatür taraması yapılmıştır. Mild hibrit araçlar için çift yönlü DA-DA

dönüştürücüler üzerine yapılan akademik çalışmalar ve endüstriyel uygulamalar

incelenmiştir.

Literatürdeki erken dönem çalışmalarda genellikle maliyet odaklı yaklaşımlar nedeniyle

iki anahtarlı veya yarım köprü (half-bridge) tabanlı topolojilerin tercih edildiği

görülmektedir [1, 2]. Ancak yapılan incelemelerde, bu topolojilerin yüksek akım

değerlerinde artan iletim kayıpları, düşük güç yoğunluğu ve sınırlı kontrol esnekliği

nedeniyle, modern araçların talep ettiği %90 üzeri verimlilik hedeflerine ulaşmakta

yetersiz kaldığı raporlanmıştır.

Yine literatürde yer alan izoleli topolojiler (Dual Active Bridge-DAB veya LLC

Rezonans) incelendiğinde, galvanik izolasyonun güvenlik sağladığı ancak transformatör

kullanımı nedeniyle sistemin boyutunu ve ağırlığını artırdığı, dolayısıyla kompakt olması

gereken otomotiv uygulamalarında dezavantaj oluşturduğu belirtilmektedir [3].

Güncel araştırmalar incelendiğinde, dört anahtarlı (Buck-Boost) topolojilerin hem gerilim düşürme hem de yükseltme modlarında daha kararlı çalıştığı görülmektedir. Örneğin; [4]

numaralı çalışmada, senkron düzeltme teknikleri kullanılarak verimin artırıldığı

belirtilmiş olsada, kontrolcünün analog tabanlı olması nedeniyle yük değişimlerine tepki

süresinin yavaş kaldığı tespit edilmiştir. Benzer şekilde [5] ve [6] numaralı kaynaklarda

önerilen sistemler, sabit anahtarlama frekansında çalıştıkları için kısmi yüklerde verim

kaybı yaşamaktadırlar.

Bu projede ise literatürdeki bu eksiklikler dikkate alınarak, %85-88 bandında sıkışan

verimlilik değerlerini [5, 6] aşmak amacıyla, dijital kontrol tabanlı ve yumuşak

anahtarlama (soft-switching) tekniklerine uygun bir yapı tasarlanması hedeflenmiştir.

### 1.3. Özgünlük ve Problem Analizi

Bu çalışmanın ele aldığı temel problem; mild hibrit araçlarda kullanılan çift batarya

sistemleri arasında yüksek verimli, güvenli ve esnek bir enerji transfer mekanizmasının

mevcut çözümlerle yeterince sağlanamamasıdır. Mevcut sistemler, değişken yük ve sürüş

koşullarında verim kaybına uğramakta, batarya ömrünü olumsuz etkilemekte ve

rejeneratif frenleme potansiyelini tam olarak değerlendirememektedir.

Bu proje, literatürde yer alan çalışmalardan farklı olarak dört anahtarlı çift yönlü topoloji,

dijital PI kontrol algoritması ve yumuşak anahtarlama uyumlu yüksek frekanslı çalışma

özelliklerini bir arada sunmaktadır. Bu yapı sayesinde sistem hem donanım hem de

kontrol düzeyinde geliştirilmiş; güç yoğunluğu artırılmış ve anahtarlama kayıpları

minimize edilmiştir [7][8]. Dijital kontrol mimarisi, gerçek zamanlı izleme ve yazılım

tabanlı optimizasyon imkânı sunarak dönüştürücünün değişken sürüş senaryolarında dahi

yüksek verimle çalışmasını sağlamaktadır [9][10].

Problemin çözülmemesi durumunda, mild hibrit araçlarda enerji geri kazanımı sınırlı

kalacak, batarya sistemleri daha hızlı yıpranacak ve araçların çevresel kazanımları

azalacaktır. Bu nedenle geliştirilen sistem, yalnızca teknik bir iyileştirme değil; aynı

zamanda enerji verimliliği, sürdürülebilirlik ve çevresel etki açısından da önemli bir katkı

sunmaktadır.

### 1.4. Yaygın Etki ve BM Sürdürülebilir Kalkınma Hedefleri

Bu çalışma kapsamında geliştirilecek dijital kontrollü çift yönlü DA-DA dönüştürücü

tasarımının, teknik, ekonomik, çevresel ve akademik açılardan önemli kazanımlar

sağlaması beklenmektedir. Proje tamamlandığında, mild hibrit araçlarda kullanılan 48 V

– 12 V batarya sistemleri arasında enerji transferinin daha verimli, güvenli ve kontrol

edilebilir hâle gelmesi sağlanacak; böylece batarya ömrü uzatılacak, enerji kayıpları

azaltılacak ve rejeneratif frenleme yoluyla geri kazanılan enerji miktarı artırılacaktır. Bu

durum, araç genelinde yakıt tüketiminin ve karbon emisyonlarının azalmasına katkı

sunarak çevresel fayda sağlayacaktır.

Proje çıktıları, Birleşmiş Milletler Sürdürülebilir Kalkınma Amaçları arasında yer alan

Amaç 7: Erişilebilir ve Temiz Enerji, Amaç 9: Sanayi, Yenilikçilik ve Altyapı ve

Amaç 13: İklim Eylemi ile doğrudan ilişkilidir. Geliştirilen yüksek verimli güç

elektroniği çözümü, enerji verimliliğini artırarak temiz enerji kullanımını desteklemekte;

yerli ve yenilikçi bir tasarım yaklaşımıyla sanayi ve Ar-Ge altyapısının güçlendirilmesine

katkı sunmakta ve sera gazı emisyonlarının azaltılmasına dolaylı olarak hizmet

etmektedir. Bu yönüyle proje hem küresel sürdürülebilirlik hedefleriyle hem de ulusal

enerji ve teknoloji politikalarıyla uyum göstermektedir.

Ulusal ve uluslararası ölçekte bakıldığında, çalışma; elektrikli ve hibrit araçlarda enerji

yönetimi verimsizliği, batarya ömrünün kısalması ve güç elektroniği sistemlerinde dışa

bağımlılık gibi önemli sorunlara çözüm getirmeyi hedeflemektedir. Yerli olarak

geliştirilecek dijital kontrollü dönüştürücü tasarımı, otomotiv elektroniği alanında ithal

çözümlere olan bağımlılığı azaltma potansiyeline sahip olup, yerel sanayi için

uygulanabilir ve ölçeklenebilir bir model sunmaktadır. Aynı zamanda akademik bilgi

birikiminin endüstriyel uygulamalara aktarılmasına olanak tanımaktadır.

Proje, dijital kontrol algoritmaları, çift yönlü güç elektroniği topolojileri, PCB tasarımı

ve prototip üretimi gibi kritik mühendislik alanlarını bir arada ele alması açısından dikkat

çekmektedir. Katılımcı araştırmacılar için güç elektroniği ve kontrol sistemleri

alanlarında uygulamalı deneyim kazanılması sağlanacak; bu yönüyle nitelikli insan

kaynağı yetiştirilmesine katkıda bulunacaktır. Uzun vadede, benzer projelerin

çoğalmasıyla Ar-Ge odaklı istihdamın artması ve yüksek katma değerli teknolojik

ürünlerin geliştirilmesi mümkün olacaktır.

Ekonomik açıdan değerlendirildiğinde, geliştirilen sistemin prototip, patent veya faydalı

model başvurularına konu olabilecek nitelikte olması, ticarileşme potansiyelini

artırmaktadır. Çevresel açıdan ise enerji geri kazanımının artırılması sayesinde daha

düşük yakıt tüketimi ve daha az emisyon hedeflenmektedir. Sosyal açıdan, sürdürülebilir

ulaşım çözümlerinin yaygınlaşmasına katkı sağlayarak toplum genelinde çevre bilincinin

artmasına destek olmaktadır.

Son olarak, projenin bilimsel çıktılar üretme potansiyeli yüksektir. Elde edilecek

sonuçların; ulusal ve uluslararası konferanslarda bildiri olarak sunulması, SCI/SCI-E veya ESCI kapsamındaki dergilerde makale olarak yayımlanması mümkündür. Özellikle

güç elektroniği, otomotiv elektroniği ve enerji sistemleri alanlarında yayın yapan dergiler ve sempozyumlar, bu çalışmanın sonuçları için uygun platformlar olarak

değerlendirilmektedir.

### 1.5. Standartlar

Mühendislik standartları, tasarım ve üretim süreçlerinde güvenliği, uyumluluğu, kaliteyi

ve tekrarlanabilirliği teminat altına alan, uluslararası kabul görmüş teknik kriterlerdir.

Elektrik-Elektronik Mühendisliği tasarım projelerinde standartlara uyum; geliştirilen

sistemin sadece laboratuvar ortamında değil, gerçek dünya koşullarında ve diğer

sistemlerle entegre bir şekilde güvenle çalışabilmesini sağlar. Bu tasarım çalışması

kapsamında, otomotiv elektroniği ve güç elektroniği disiplinlerinin gerektirdiği güvenlik,

elektromanyetik uyumluluk (EMC) ve donanım dayanıklılığı kriterleri göz önüne

alınmıştır.

Mild-hibrit araç teknolojisine yönelik 48V-12V çift yönlü DA-DA dönüştürücü

tasarımında temel alınan, uyulması hedeflenen ve tasarım kararlarını şekillendiren başlıca

standartlar aşağıda sıralanmıştır:

LV 148 (VDA 320): Elektrik ve Elektronik Bileşenler için 48V Güç Kaynağı Sistemi

Gereksinimleri

Bu proje özelinde 48V mild-hibrit sistemin gerilim seviyeleri, çalışma aralıkları ve

elektriksel yük testleri, Alman Otomotiv Endüstrisi Birliği (VDA) tarafından belirlenen

bu standarda referansla belirlenmiştir.

CISPR 25: Araçların, Teknelerin ve İçten Yanmalı Motorların Radyo Bozulma

Özellikleri-Sınırlar ve Ölçüm Yöntemleri

Tasarlanan anahtarlamalı güç kaynağının (SMPS), araç içerisindeki hassas elektronik

donanımları (ECU, sensörler, radyo vb.) etkilememesi için elektromanyetik emisyon

sınırları bu standarda göre dikkate alınmıştır.

AEC-Q100: Otomotiv Uygulamaları için Entegre Devre Stres Testi Yeterliliği

Tasarımda kullanılan dijital kontrolcü (UCD3138) ve diğer yarı iletken bileşenlerin,

otomotiv ortamındaki sıcaklık ve titreşim koşullarına uygunluğu bu standart serisine göre

değerlendirilerek seçilmiştir.

ISO 26262: Yol Araçları- Fonksiyonel Güvenlik

Sistemin dijital kontrollü yapısı nedeniyle, olası arıza durumlarında (aşırı akım, kısa devre vb.) devrenin güvenli duruma geçmesi ve batarya güvenliğinin sağlanması ilkesi

bu standart çerçevesinde ele alınmıştır.

IPC-2221: Baskı Devre Kartı (PCB) Tasarımı için Genel Standart

Devre kartı tasarımı yapılırken yol (trace) kalınlıkları, komponentler arası izolasyon

mesafeleri ve akım taşıma kapasiteleri, IPC-2221 genel tasarım standardına uygun olarak

hesaplanmıştır.

### 1.6 Çalışma Takvimi

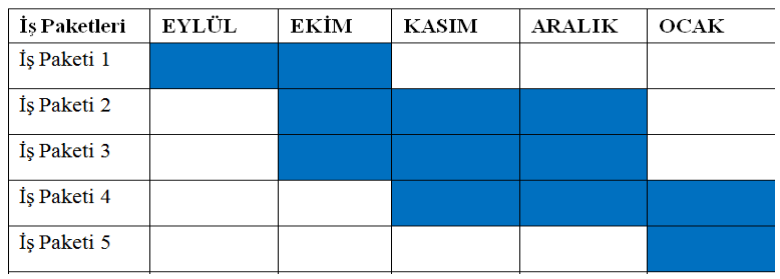
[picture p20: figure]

Tablo 1.1: Tasarım Proje Çalışma Takvimi

İş Paketi 1 – Proje Konusunun Belirlenmesi. Uygulanabilir proje konularının tespit

edilmesi. Danışman hocalarla görüşmeler yapılarak en uygun projenin seçilmesi. Proje

kapsamında kullanılabilecek alternatif fikirlerin de belirlenmesi.

İş Paketi 2 – Literatür Araştırması ve Proje Temellerinin Oluşturulması. Benzer

projelerin araştırılması ve mevcut çalışmalardan farklı yönlerin ortaya konulması.

Literatür taraması yapılarak projeye uygun teorik bilgilerin derlenmesi. Projede

kullanılacak donanım ve yazılım bileşenlerinin belirlenmesi. Projenin kapsamı ve

sınırlarının netleştirilmesi.

İş Paketi 3 – Tasarım Aşaması ve Teorik Altyapının Oluşturulması. Proje tasarımına

yönelik teorik hesaplamaların yapılması. FSBB topolojisi hakkında teorik araştırmalar

yapılması, simülasyon ve hesapların yapılması.

İş Paketi 4 – Simülasyon ve Yazılım Geliştirme. Yazılım dili ve geliştirme araçlarının

belirlenmesi. | Tasarımın | simülasyonlarının | yapılması | ve | optimizasyonların

gerçekleştirilmesi.

İş Paketi 5 – Raporlama ve Sonuçların Hazırlanması. Projenin teknik raporunun tamamlanması. Tasarım ve simülasyon sonuçlarının düzenlenmesi. Projenin teslim ve

sunum hazırlıklarının yapılması.

### 2. KURAMSAL TEMELLER

### 2.1. Genel Bilgiler

Otomotiv endüstrisinde emisyon standartlarını karşılamak ve yakıt verimliliğini

artırmak amacıyla geliştirilen Mild-Hibrit Elektrikli Araç (MHEV) teknolojisi,

geleneksel 12V şebekesine ek olarak 48V'luk ikinci bir güç şebekesini barındırır. Bu

mimaride, marş jeneratörü ve klima kompresörü gibi yüksek güç gerektiren yükler 48V

hattından beslenirken, aydınlatma ve bilgi-eğlence sistemleri 12V hattında kalmaya

devam eder. Bu iki gerilim seviyesi arasındaki enerji transferini sağlamak için çift yönlü

(bidirectional) DA-DA dönüştürücülere ihtiyaç duyulur.

Bu tasarım projesinde, enerji akışını her iki yönde (48V’tan 12V’a ve 12V’tan 48V’a)

kontrol edebilen, dijital kontrollü bir güç katı tasarlanmıştır.

### 2.2. Sistem Blok Diyagramı

Projede kullanılacak sistemin genel yapısı Şekil 2.1’de verilen blok diyagram ile

özetlenmiştir. Bataryalar arasında enerji akışı, özel bir devre olan dört anahtarlı

dönüştürücü sayesinde çift yönlü olarak gerçekleşir. 48V’tan 12V’a düşürme veya

12V’tan 48V’a yükseltme işlemleri bu devre üzerinden yapılır. Devrenin kontrolü için

kullanılacak mikrodenetleyici hem gerekli anahtarlama sinyallerini üretir hem de

bataryalardan gelen akım ve gerilim bilgilerini takip ederek sistemin güvenli çalışmasını

sağlar.

Şekil 2.1: 48V ve 12V batarya bankaları arasında çift yönlü güç akışını sağlayan

dönüştürücü topolojisi.

### 2.3. Devre Tasarımı ve Çalışma Modları

Bu projede dört anahtarlı buck-boost topolojisi tercih edilmiştir çünkü bu yapı hem 12V

hem de 48V bataryalar arasında çift yönlü enerji transferine imkân tanır hem de diğer

yöntemlere göre daha yüksek verim ve kontrol esnekliği sağlar. Bu yapı sayesinde enerji

akışı her iki yönde kontrollü olarak sağlanabilmektedir. Projede iki çalışma modu

kullanılacaktır. 48V → 12V Modu (Buck) çalışmasında, Q3 sürekli iletimde, Q4 sürekli

kapalı tutulurken Q1 anahtarı D (görev döngüsü) oranıyla ana anahtar olarak sürülür ve

Q2 (1-D) oranıyla senkron doğrultucu olarak görev yapar.

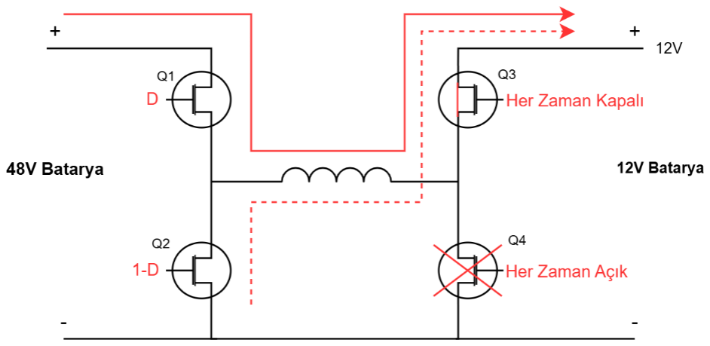
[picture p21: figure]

Şekil 2.2: Düşürücü (buck) modu akım yolu.

12V → 48V Modu (Boost) çalışmasında ise Q3 sürekli iletimde, Q4 sürekli kapalı

tutulurken Q2 anahtarı D (görev döngüsü) oranıyla ana anahtar olarak sürülür ve Q1

(1-D) oranıyla senkron doğrultucu olarak görev yapar.

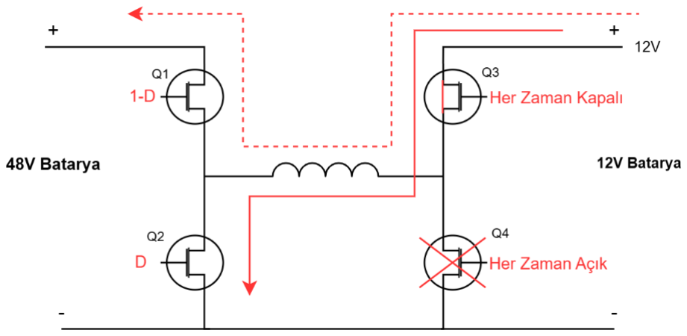
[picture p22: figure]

Şekil 2.3: Yükseltici (boost) modu akım yolu.

### 2.4. Güç MOSFET'leri ve Anahtarlama Dinamikleri

Güç elektroniği dönüştürücülerinde enerjinin verimli bir şekilde kontrol edilmesi, yarı

iletken anahtarlama elemanları ile sağlanır. Bu tasarımda, yüksek anahtarlama hızı, düşük

iletim direnci (RDS(on)
) ve yüksek akım taşıma kapasitesi sunması nedeniyle N-Kanal

Güç MOSFET'leri tercih edilmiştir.

Geleneksel silikon diyotlar yerine MOSFET kullanılması, "Senkron Doğrultma"

(Synchronous Rectification) tekniğine olanak tanır. Diyotların yaklaşık 0.7V

seviyesindeki ileri yön gerilim düşümü, yüksek akımlarda ciddi güç kayıplarına yol

açmaktadır. Bunun yerine, iletim sırasında çok düşük iç dirence sahip MOSFET'lerin

kullanılmasıyla iletim kayıpları minimize edilir.

Bu çalışmada MOSFET seçiminde ve analizinde aşağıdaki üç temel karakteristik dikkate

alınmıştır:

### 2.4.1. İletim Kayıpları (Pcond)

MOSFET tamamen iletimde (ON) olduğu sürece oluşan omik kayıptır. Mild-hibrit

sistemlerde akımlar 100A seviyelerine çıkabildiği için, (RDS(on)

) değeri mili-ohm (mΩ)

seviyesinde olan komponentler seçilerek ısıl kaçak (thermal runaway) riski azaltılmıştır.

Pcond = Irms

2
⋅ RDS(on)
(1)

### 2.4.2. Anahtarlama Kayıpları ve Gate Yükü (Qg)

MOSFET ideal bir anahtar değildir; kesimden iletime (veya tersine) geçişi belirli bir süre

alır. Bu geçiş süresi, MOSFET'in Gate Yükü (Qg) ile doğrudan ilişkilidir. Yüksek

frekanslı (Örn: 100 kHz) tasarımlarda, MOSFET'in lineer bölgede geçirdiği süre boyunca

oluşan V ⋅ I kaybı (switching loss) toplam verimi düşürür. Bu nedenle düşük Qg

değerine sahip MOSFET'ler tercih edilmiştir.

### 2.4.3. Ölü Zaman (Dead-Time) Yönetimi

Yarım köprü (Half-Bridge) yapısında, alt ve üst MOSFET'lerin aynı anda iletime geçmesi

(Shoot-Through), kaynağın kısa devre olmasına neden olur. Bunu önlemek için, bir anahtar kapanmadan diğeri açılmamalıdır. İki anahtarlama sinyali arasına mikrosaniye

mertebesinde "Ölü Zaman" eklenmiştir. Bu süre zarfında akım, MOSFET'in gövde

diyodu (Body Diode) üzerinden akar.

### 2.5. Mikrodenetleyici ve Dijital Güç Çevre Birimleri

Modern güç kaynaklarında kontrol mimarisi analogdan dijitale kaymıştır. Bu projede

sistemin beyni olarak, yüksek işlem kapasitesine ve güç elektroniğine özelleşmiş çevre

birimlerine (Peripherals) sahip bir Dijital Sinyal Kontrolcüsü (DSC) / Mikrodenetleyici

(MCU) kullanılmıştır.

Standart mikrodenetleyicilerden farklı olarak, bu tasarımda kullanılan işlemcinin

(UCD3138) şu özelleşmiş yeteneklerinden faydalanılmaktadır:

### 2.5.1. Yüksek Çözünürlüklü PWM (HRPWM)

Çıkış geriliminin hassas bir şekilde regüle edilebilmesi için standart PWM çözünürlüğü

yetersiz kalabilir. HRPWM modülleri, pikosaniye mertebesinde hassasiyet sağlayarak,

kontrol döngüsünde "Limit Döngüsü" (Limit Cycling) adı verilen salınımların oluşmasını

engeller.

### 2.5.2. PWM ile Senkronize ADC Örnekleme

Anahtarlama anlarında oluşan elektromanyetik gürültüden (Switching Noise)

etkilenmemek için, ADC okumaları rastgele değil, PWM sinyalinin tam orta noktasında

(gürültüsüz an) tetiklenerek gerçekleştirilir.

### 2.5.3. Donanımsal Arıza Kesmeleri (Fault Trip Zones)

İşlemci çekirdeğinden bağımsız çalışan karşılaştırıcılar (Comparators), akım veya gerilim

sınırları aşıldığında PWM çıkışlarını nano-saniyeler içinde kapatarak sistemi korumaya

alır. Yazılımsal müdahalenin gecikmesi bu sayede elimine edilir.

### 2.6. PI (Oransal-İntegral) Kontrol Yöntemi

Anahtarlamalı güç kaynaklarında (SMPS) meydana gelen yüksek frekanslı anahtarlama

gürültülerinin, standart PID denetleyicilerdeki Türev (D) bileşeni tarafından yükseltilerek sistem kararlılığını bozma riski taşıması nedenlerinden; ve İntegral (I) bileşeninin sistem

çıkışındaki kalıcı durum hatasını sıfıra indirme yeteneği, düşük işlemci yükü ve parametre değişimlerine karşı gürbüz yapısı avantajlarından dolayı bu projede PI (Oransal-İntegral)

Kontrol Yöntemi kullanılmıştır.

### 2.6.1. Teknik Altyapı ve Çalışma Prensibi

DA-DA dönüştürücü tasarımında kontrolcünün temel görevi, referans gerilim (Vref) ile

ölçülen çıkış gerilimi (Vout) arasındaki farkı, yani hata sinyalini (e(t)) minimize etmektir. PI kontrolör, bu hatayı iki farklı mekanizma ile işleyerek MOSFET'lerin iletim

süresini (Duty Cycle) belirleyen kontrol sinyalini (u(t)) üretir:

### 2.6.2. Oransal (Proportional - P) Etki:

Hata sinyali ile doğrudan orantılı bir çıkış üretir (Kp ⋅ e(t)).Bu bileşen, sistemin ani yük

değişimlerine hızlı tepki vermesini sağlar ve yükselme süresini (rise time) kısaltır. Ancak,

sadece oransal kontrol kullanıldığında sistem referans değere tam olarak oturamaz ve bir

"Kalıcı Durum Hatası" (Steady-State Error) oluşur.

### 2.6.3. İntegral (Integral - I) Etki:

Hatanın zamanla birikimini alarak kontrol sinyaline ekler (Ki ∫ e(t)) Hata pozitif olduğu

sürece integral toplamı artmaya devam eder. Bu matematiksel özellik, hatanın eninde

sonunda sıfırlanmasını garanti eder. Böylece batarya gerilimi düşse bile dönüştürücü

çıkışı tam olarak istenen değerde tutulabilir.

### 2.6.4. Matematiksel Model

PI kontrolörün integral terimi, sistem fiziksel limitlerine (Maksimum Duty Cycle)

ulaştığında dahi matematiksel olarak artmaya devam etme eğilimindedir (Integral

Windup). Bu durum, hata giderildiğinde sistemin toparlanmasını geciktirerek çıkış

geriliminde tehlikeli aşımlara (Overshoot) neden olabilir.

Tasarımda bu sorunu önlemek amacıyla yazılımsal Anti-Windup (İntegral Doyumu

Önleme) mekanizması uygulanmıştır. Bu algoritma, PWM çıkışı satürasyona (%0 veya

%100) ulaştığında integral hesabını dondurarak sistemin kararsızlığa sürüklenmesini

engeller.

### 3. YÖNTEM VE TASARIM

### 3.1 Genel Bilgiler

Bu bölümde, projenin temelini oluşturan 48 V–12 V bataryalar arası çift yönlü DA-DA

dönüştürücü sisteminin tasarım yaklaşımı ve gerçekleştirme süreci ele alınmaktadır.

Tasarım süreci; sistem gereksinimlerinin tanımlanması, teorik altyapının oluşturulması,

gerekli elektriksel hesaplamaların yapılması ve donanımın fiziksel olarak uygulanabilir

hale getirilmesini kapsayan bütüncül bir mühendislik yaklaşımı ile yürütülmüştür.

Çalışma kapsamında, mild-hibrit araç mimarilerinde kullanılan 48 V ve 12 V batarya

sistemleri arasındaki enerji alışverişini güvenli, verimli ve kontrollü bir şekilde

sağlayabilecek bir çift yönlü güç dönüştürücü yapısı hedeflenmiştir. Bu doğrultuda,

giriş ve çıkış gerilim seviyeleri, maksimum güç ve akım değerleri, anahtarlama frekansı,

verim beklentisi ve otomotiv uygulamalarına uygunluk gibi temel tasarım kriterleri

belirlenmiştir.

Belirlenen gereksinimler ışığında, uygun dönüştürücü topolojisi seçilmiş ve sistemin

teorik modeli güç elektroniği prensiplerine dayandırılarak oluşturulmuştur. Tasarım

sürecinde; anahtarlama elemanları, enerji depolama ve filtreleme bileşenleri ile kontrol

biriminin seçimi, elektriksel sınır değerler ve çalışma koşulları göz önünde

bulundurularak gerçekleştirilmiştir. Yapılan hesaplamalar, kullanılan teorik modellerle

ilişkilendirilmiş ve sistemin güvenli çalışma aralığı doğrulanmıştır.

Ayrıca, dijital kontrollü yapı kapsamında geri besleme mekanizmaları, ölçüm ve

koruma devreleri ile sistemin kararlılığını sağlayacak temel kontrol prensipleri tasarım

sürecine dâhil edilmiştir. Teorik analizler sonucunda elde edilen tasarım parametreleri,

donanım gerçekleştirme aşamasında uygulanabilir olacak şekilde düzenlenmiş ve

üretilebilir bir sistem mimarisi ortaya konmuştur.

### 3.2. Sistem Bileşenleri ve Seçimleri

Tasarımı gerçekleştirilen 48V-12V Çift Yönlü DA-DA Dönüştürücü projesinde,

otomotiv endüstrisinin gerektirdiği yüksek verimlilik, hızlı dinamik tepki ve

güvenilirlik kriterlerini sağlamak amacıyla endüstriyel sınıf bileşenler tercih edilmiştir.

Sistem topolojisi olarak "4-Anahtarlı Buck-Boost" yapısı kullanılmış ve bileşenler bu

topolojinin gereksinimlerine göre seçilmiştir. Sistemi oluşturan temel alt bileşenler, teknik özellikleri ve seçim gerekçeleriyle birlikte aşağıda detaylandırılmıştır:

### 3.2.1. Dijital Güç Kontrolcüsü: UCD3138 (Texas Instruments)

Sistemin ana kontrol ünitesi olarak standart bir mikrodenetleyici yerine, güç elektroniği

uygulamaları için özel olarak geliştirilmiş UCD3138 Dijital Güç Kontrolcüsü

kullanılmıştır.

### 3.2.1.1. Seçim Nedeni ve Teknik Özellikler:

Özelleşmiş Çevre Birimleri: İçerisinde barındırdığı DPWM (Dijital PWM) modülleri,

PID kontrol döngüsünü işlemci çekirdeğinden (ARM7) bağımsız donanımsal olarak

yürütebilmektedir. Bu sayede 100 kHz ve üzeri anahtarlama frekanslarında dahi işlemci

yükü artmadan hassas regülasyon sağlanır.

Hata Koruması: Analog karşılaştırıcılar (Comparators) sayesinde aşırı akım veya aşırı

gerilim durumunda yazılımdan bağımsız olarak PWM çıkışlarını nano-saniyeler içinde

keserek MOSFET’leri korur.

Kullanım Şekli: Kontrolcü, giriş ve çıkıştan aldığı gerilim/akım geri beslemelerini

işleyerek, 4 adet MOSFET’in anahtarlama sinyallerini üretir ve sistemi Buck, Boost

veya Buck-Boost modları arasında otomatik geçirir.

### 3.2.1.2. Kritik Pin Konfigürasyonu ve İşlevleri

UCD3138RGC (64-Pin) entegresi üzerinde, projenin güç akışını yöneten ve geri

besleme (feedback) döngülerini kapatan temel pinler Tablo 3.3'te listelenmiştir. Bu

pinlerin işlevleri, 4-anahtarlı topolojinin gereksinimlerine göre yapılandırılmıştır.

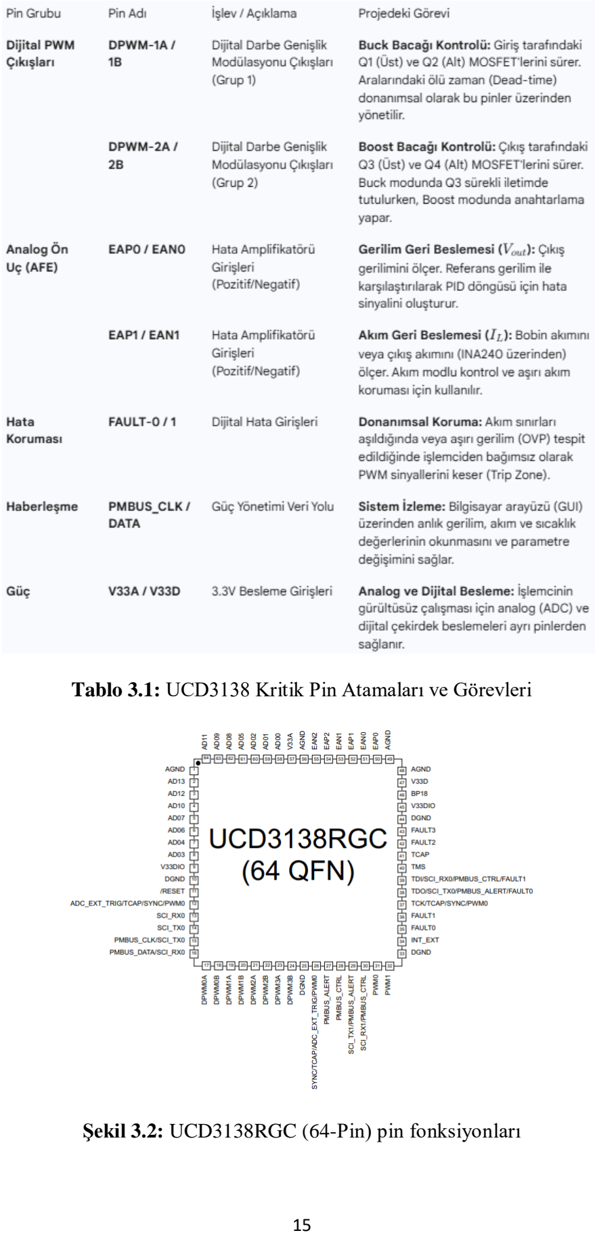
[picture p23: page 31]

Tablo 3.1: UCD3138 Kritik Pin Atamaları ve Görevleri

Şekil 3.2: UCD3138RGC (64-Pin) pin fonksiyonları

### 3.2.2. Güç MOSFET’leri: CSD19536KCS (NexFET™)

Anahtarlama elemanı olarak, yüksek akım taşıma kapasitesine sahip N-Kanal Güç

MOSFET’leri kullanılmıştır. Topolojide toplam 4 adet CSD19536KCS kullanılmıştır.

### 3.2.2.1. Seçim Nedeni ve Teknik Özellikler

Gerilim Dayanımı (VDS): 100V VDS dayanımı sayesinde, 48V barasında oluşabilecek

ani gerilim yükselmelerine (Load Dump, Spike) karşı yeterli güvenlik marjı (yaklaşık 2

katı) sağlanmıştır.

Düşük İletim Direnci (RDS(on)): 2.3 mΩ gibi çok düşük bir iç dirence sahiptir. Bu

özellik, yüksek akımlarda iletim kayıplarını (Conduction Loss) minimize ederek

sistemin %95 üzeri verimliliğe ulaşmasında kritik rol oynar.

Termal Yapı: TO-220 kılıf yapısı sayesinde oluşan ısı, PCB'ye veya soğutucuya

verimli bir şekilde aktarılabilmektedir.

Şekil 3.3: CSD19535KCS mosfet görünümü

CSD19535KCS | TA = 25°C | TYPICAL VALUE | UNIT
VDS | Drain-to-Source Voltage | 100 | V
Qg | Gate Charge Total (10V) | 78 | nC
Qgd | Gate Charge Gate to Drain | 13 | nC
RDS(on) | Drain-to-Source On Resistance | VGS = 6V → 3.4 VGS = 10V → 3.1 | mΩ
VGS(th) | Threshold Voltage | 2.7 | V
Tablo 3.4: CSD19535KCS mosfet ürün özeti

### 3.2.3. MOSFET Sürücüleri: UCC27211A

Dijital kontrolcüden gelen 3.3V seviyesindeki PWM sinyalleri, güç MOSFET’lerini

sürmek için yetersizdir. Bu sinyalleri güç seviyesine yükseltmek ve özellikle üst koldaki

(High-Side) anahtarları sürmek için UCC27211A sürücü entegresi seçilmiştir.

### 3.2.3.1. Seçim Nedeni ve Teknik Özellikler

Bootstrap Yapısı: 120V’a kadar dayanabilen bootstrap diyot yapısı ile 48V hattındaki

üst MOSFET’leri sorunsuz sürebilmektedir.

4A Tepe Akımı: MOSFET’lerin Gate kapasitansını hızlıca şarj/deşarj edebilmek için

4A kaynak (source) ve çekme (sink) akımı sağlayabilir. Bu sayede anahtarlama geçişleri

hızlanır ve anahtarlama kayıpları azalır.

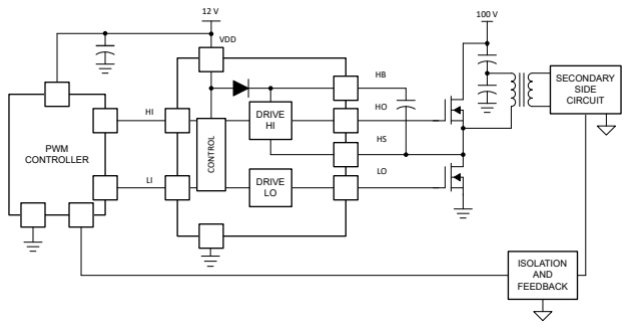
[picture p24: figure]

Şekil 3.5: UCC27211ADRMR örnek uygulama devresi

Şekil 3.2.3.1, sistemin her bir anahtarlama kolunu (Buck veya Boost tarafı) sürmek

için kullanılan UCC27211 entegresinin çevresel bileşenlerle olan bağlantısını

göstermektedir. Devrenin çalışma prensibi ve kritik bileşenlerin görevleri şunlardır:

### 3.2.4. Giriş Sinyalleri (DPWM0A / DPWM0B)

Şemada 5 ve 6 numaralı pinlere (HI ve LI) giren sinyaller, dijital kontrolcüden

(UCD3138) gelen 3.3V seviyesindeki PWM komutlarıdır. Bu sinyaller, sürücü

entegresi tarafından güç MOSFET'lerini tetikleyebilecek yüksek akımlı sinyallere

dönüştürülür.

Bootstrap Devresi (D13 ve C23): N-Kanal MOSFET'lerin kullanıldığı üst kolda

(High-Side), anahtarı iletime geçirmek için Kaynak (Source) geriliminden daha

yüksek bir Gate gerilimine ihtiyaç duyulur. Şemada görülen C23 (2.2µF) kapasitörü

ve D13 diyodu (Bootstrap Diyodu), "yüzen kaynak" (floating supply) oluşturarak bu

gerilimi sağlar. SW1 düğümü (Switching Node) toprağa çekildiğinde C23 kapasitörü

12V üzerinden şarj olur; üst anahtar açılacağı zaman bu depolanan enerji kullanılır.

### 3.2.5. Çıkış Sinyalleri (HO ve LO):

Entegrenin 3 (HO) ve 8 (LO) numaralı pinleri, sırasıyla üst ve alt MOSFET'lerin Gate

uçlarına bağlanır. H1 ve L1 etiketli bu hatlar, MOSFET'lerin giriş kapasitanslarını

hızlıca doldurup boşaltarak keskin anahtarlama geçişleri sağlar.

### 3.2.6. Besleme ve Filtreleme (C19)

Sürücü entegresinin kararlı çalışması ve anlık akım çekimlerinde gerilim çökmesi

yaşamaması için VDD hattına (Pin 1) C19 (4.7µF) dekuplaj (bypass) kapasitörü,

entegreye en yakın noktada konumlandırılmıştır.

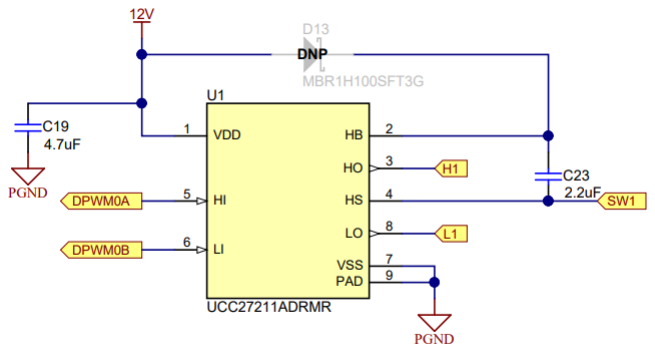
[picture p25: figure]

Şekil 3.6: Projede mosfet sürücü entegresinin uygulanması

(Not: Şemada D13 diyodu üzerinde "DNP" (Do Not Populate) ibaresi yer alsa da,

bootstrap fonksiyonunun çalışabilmesi için bu pozisyonda hızlı toparlanma süresine

sahip bir Schottky diyot tasarımda kullanılacaktır.)

### 3.2.7. Güç İndüktörü (Bobin): Wurth Elektronik 7443641000

Enerjinin depolandığı ve aktarıldığı manyetik eleman olarak 10 µH değerinde, yüksek akım kapasiteli bir şok bobini kullanılmıştır.

### 3.2.7.1. Seçim Nedeni ve Teknik Özellikler

Doyum Akımı (Isat): Bobinin manyetik doyuma girmesi endüktans değerinin

çökmesine neden olur. Seçilen bobin, sistemin maksimum tepe akımını karşılayacak

yüksek satürasyon akımına sahiptir.

Düşük DC Direnci (DCR): Yaklaşık 2.4 mΩ DCR değeri ile bobin üzerindeki bakır

kayıpları (Isı) minimum düzeyde tutulmuştur.

Ekranlama (Shielding): Manyetik alanın çevreye yayılmasını önleyen ekranlı yapısı

(Mangan-Çinko çekirdek), sistemin EMC (Elektromanyetik Uyumluluk) standartlarına

uymasına yardımcı olur.

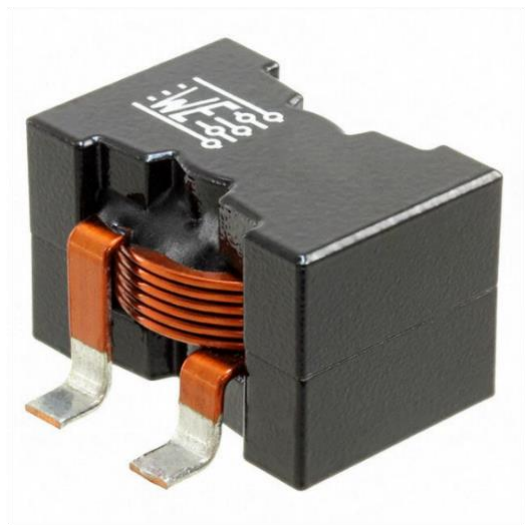
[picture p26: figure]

Şekil 3.7: Wurth Elektronik 7443641000 bobin

Şekil 3.7’de, sistemde kullanılan yüksek akım kapasiteli güç indüktörünün (Würth

Elektronik) üzerinden geçen DA akım miktarına bağlı olarak gövde sıcaklığında

meydana gelen artışı gösteren sıcaklık–akım karakteristik eğrisi sunulmaktadır. Bobin

üzerinden geçen akım arttıkça, sargı direncine (RDC) bağlı olarak oluşan bakır kayıpları

(P = I^2 ⋅ R) nedeniyle indüktör bünyesinde ısınma meydana gelmektedir. Grafik

incelendiğinde, sıcaklık artışının akım ile doğrusal değil, karesel bir ilişki sergilediği ve

bu durumun teorik güç kaybı modeli ile uyumlu olduğu görülmektedir. Projenin

maksimum yük akımı senaryolarında (yaklaşık 20 A – 30 A aralığında), kırmızı eğri

(IRP) esas alındığında sıcaklık artışının yaklaşık 20 K ile 40 K arasında kaldığı

belirlenmiştir. Endüstriyel güç elektroniği uygulamalarında genellikle 40 K – 50 K

aralığındaki sıcaklık artışları kabul edilebilir sınırlar içerisinde değerlendirildiğinden, seçilen indüktörün ilgili çalışma koşulları için termal açıdan güvenli bir çalışma alanı

sunduğu bu grafik aracılığıyla doğrulanmaktadır. Ayrıca elde edilen sonuçlar, bobinin

ilave bir aktif soğutma sistemine ihtiyaç duymadan, yalnızca PCB üzerinden sağlanan

doğal konveksiyon ile güvenli şekilde çalışabileceğini göstermektedir.

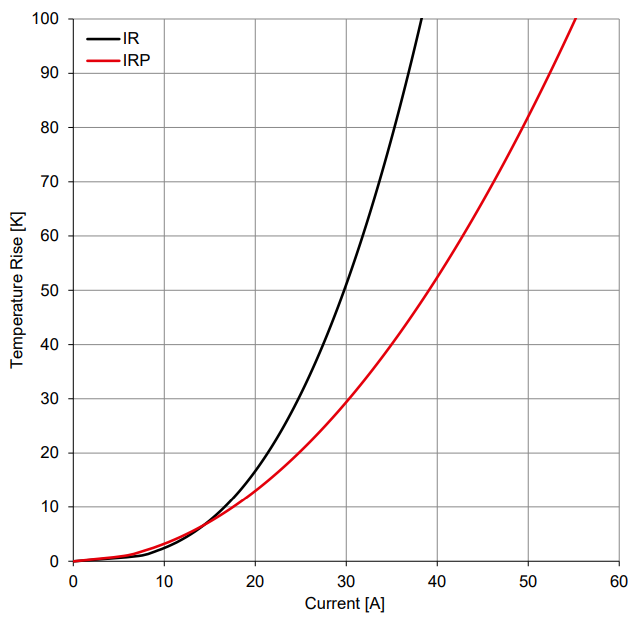
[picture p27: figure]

Şekil 3.8: Seçilen Güç Endüktans Akım-Sıcaklık Artışı (Temperature Rise) Karakteristik Eğrisi.

(Not: "Grafikteki sıcaklık artış değerleri Kelvin (K) cinsinden verilmiştir. SI birim sistemine göre sıcaklık farklarında 1 K = 1

∘
C olduğundan, bu değerler doğrudan Celsius artışı olarak değerlendirilmiştir.")

### 3.2.8. Akım Algılama Devresi: OPA2211A (Texas Instruments)

Sistemin akım modunda kontrol edilebilmesi ve aşırı akım korumasının çalışabilmesi

için bobin akımının hassas bir şekilde ölçülmesi gerekir. PMP21529 tasarımında bu

işlem için yüksek hassasiyetli bir Operasyonel Amplifikatör (Op-Amp) olan

OPA2211A kullanılmıştır.

### 3.2.8.1. Seçim Nedeni ve Teknik Özellikler

Ultra Düşük Gürültü: 1.1 nV/√Hz seviyesindeki çok düşük gürültü yoğunluğu

sayesinde, şönt direnci (Shunt Resistor) üzerinde oluşan çok küçük gerilim düşümlerini

bile gürültüden etkilenmeden yükseltebilir.

Yapılandırma: Şematikte OPA2211A, direnç ağları ile "Fark Yükselteci" (Difference

Amplifier) olarak yapılandırılmıştır. Bu sayede akım yolundaki yüksek voltajdan

(Common Mode Voltage) etkilenmeden sadece akımla orantılı olan fark gerilimini

UCD3138'in ADC girişlerine iletir.

Raydan-Raya | (Rail-to-Rail): | Çıkış | sinyalinin | besleme | gerilimlerine | çok

yaklaşabilmesi, ADC'nin tüm dinamik aralığının kullanılmasını sağlar.

Şekil 3.9: OPA2211AIDDA OPAMP

### 3.3. Yöntem

Bu çalışmada, Mild-Hibrit araç uygulamalarında kullanılan 48 V–12 V batarya

sistemleri arasında enerji transferini sağlayan çift yönlü DA-DA dönüştürücünün

tasarım ve doğrulama süreci, sistematik bir mühendislik yaklaşımı izlenerek

gerçekleştirilmiştir. Tasarım süreci; öncelikle sistem gereksinimlerinin belirlenmesi,

ardından güç elektroniği teorisine dayalı analitik hesaplamaların yapılması ve bu

hesaplamaların sayısal benzetim ortamlarında doğrulanması adımlarını kapsamaktadır.

Dönüştürücünün hem yükseltici (Boost) hem de düşürücü (Buck) modlarda

çalışabilmesi, farklı çalışma koşullarında kararlı ve güvenli bir kontrol yapısını zorunlu

kıldığından, tasarım sürecinde donanım ve kontrol algoritmaları birlikte ele alınmıştır.

Uygulanan yöntemler kapsamında; güç katının boyutlandırılması, anahtarlama

elemanlarının ve pasif bileşenlerin seçimi, kontrol stratejisinin belirlenmesi ve sistemin

dinamik davranışının analiz edilmesi adımları bütüncül bir yaklaşımla yürütülmüştür.

Teorik hesaplamalar, literatürde kabul görmüş model ve denklemler esas alınarak

gerçekleştirilmiş; elde edilen sonuçlar, simülasyon çalışmaları ile desteklenerek

tasarımın doğruluğu ve uygulanabilirliği değerlendirilmiştir. Projenin farklı

safhalarında izlenen devre tasarım, dijital kontrol, sayısal çözümleme ve haberleşme

yöntemleri, bu bölüm altında alt başlıklar halinde detaylı olarak açıklanmaktadır.

### 3.3.1. Devre Tasarım ve Analiz Yöntemleri

Donanım tasarımı, Mild-Hibrit araç uygulamalarında karşılaşılan yüksek akım

seviyeleri, anahtarlama frekansları ve zorlu çevresel koşullar göz önünde

bulundurularak gerçekleştirilmiştir. Bu kapsamda tasarım sürecinde elektromanyetik

uyumluluk (EMC), güç yoğunluğu ve termal yönetim kriterleri temel alınmış; sistem,

modüler tasarım yaklaşımı benimsenerek yapılandırılmıştır. Güç katı (Power Stage) ve

kontrol katı (Control Stage) fonksiyonel olarak birbirinden ayrılarak tasarlanmış, bu

sayede yüksek akım anahtarlama işlemlerinden kaynaklanan gürültülerin kontrol

devrelerini etkilemesi önlenmeye çalışılmıştır.

Şematik tasarım aşamasında, yüksek akım taşıyan hatlar ile düşük seviyeli analog ve dijital sinyaller net bir şekilde ayrıştırılmıştır. Özellikle MOSFET’ler, indüktör ve

giriş/çıkış kapasitörleri arasındaki akım döngüleri minimize edilerek, parazitik

endüktans ve anahtarlama kaynaklı gerilim salınımları (voltage spike) azaltılmaya

çalışılmıştır. Bu yaklaşım hem verimliliğin artırılmasına hem de elektromanyetik

yayılımın sınırlandırılmasına katkı sağlamaktadır.

PCB tasarımında, yüksek güç uygulamalarında yaygın olarak tercih edilen 4 katmanlı

baskı devre kartı yapısı kullanılmıştır. IPC-2221 standardı referans alınarak belirlenen

bu yapıda, iç katmanlar geniş güç ve toprak (GND) düzlemleri olarak ayrılmış; böylece

hem düşük empedanslı akım dönüş yolları sağlanmış hem de elektromanyetik

kalkanlama ve ısıl yayılım desteklenmiştir. Termal açıdan kritik olan MOSFET ve

indüktör gibi bileşenler, PCB üzerinde ısı birikimini azaltacak ve doğal konveksiyonu

destekleyecek şekilde konumlandırılmış; mümkün olduğunca simetrik yerleşim

prensipleri uygulanmıştır.

### 3.4. Güç Katları Tasarım Parametreleri ve Hesaplamalar

Bu bölümde, sistemin hem Buck hem de Boost modlarında çalışması için gerekli olan

endüktans (L) ve kapasitans (C) değerleri, belirlenen dalgalanma (ripple) kriterlerine

göre hesaplanmıştır. Tasarımda anahtarlama frekansı (fs) 30kHz ve endüktans akımı (I)

10A olarak referans alınmıştır.

### 3.4.1. Buck Modu Tasarım Hesaplamaları

Buck modunda sistem Vin=48V giriş gerilimini Vout= 12V çıkış geriilimine

dönüştürmektedir. Vo=Vin×D formülünü kullanarak duty cycle (D) 0.25 olarak

hesaplanmıştır.

### 3.4.1.1. Endüktans Değerinin Belirlenmesi

Bobin üzerindeki akım dalgalanmasını (ΔIL) ortalama akımın %20’sini (yani 2A)

aşmaması istenmektedir. Gerekli endüktans değeri aşağıdaki formül ile hesaplanmıştır:

ΔILBuck =

(Vin−Vout).D
fs .L

(2)

2A =

(48V−12V).0,25
30,000.L

(3)

L =

36×0,25
30,000×2
= 150μH | (4)

### 3.4.1.2. Kapasitans Değerinin Belirlenmesi

Çıkış gerilimindeki dalgalanmanın %2 (yani0.24V) olması hedeflenmiştir. Gerekli

minimum çıkış kapasitansı şu şekilde hesaplanmıştır.

Cout =

∆Ic
8×Fs×∆Vout

(5)

Cout =

2
8×30,000×0.24
= 34.72μF | (6)

### 3.4.2. Boost Modu tasarım Hesaplamaları

Boost modunda sistem Vin=12V giriş gerilimini Vout=48V çıkış gerilimine

yükseltmektedir. Vo =

1
1−D

× Vi formülünü kullanarak bu Mod için duty cycle (D) 0.75

olarak belirlenmiştir.

### 3.4.2.1. Endüktans Değerinin Belirlenmesi

Boost modunda bobin akım dalgalanması için giriş gerilimi baz alınarak hesaplama

yapılmıştır.

∆IL_Boost =

Vin×D
Fs×L

(7)

2A =

12V×0,75
30,000×L

(8)

L =

9
60,000
= 150μH | (9)

### 3.4.2.2 Kapasitans Değerinin Belirlenmesi

Boost modunda çıkış gerilim dalgalanmasının %2 (0.96V) seviyesinde tutulması için

gerekli kapasite değeri, yük akımım ve duty cycle dikkate alınarak hesaplanmıştır:

Cout ≥

Iout,max×D
fs×∆Vout

(10)

Cout =

10×0,75
30,000×0,96
= 260μF | (11)

### 3.5. Sistemin Modellenmesi ve Yapılan Hesaplamalar

Klasik kontrol yöntemlerinde sistemler transfer fonksiyonları üzerinden analiz edilir.

Ancak bu yaklaşım, sistemin başlangıçtaki enerji durumunu (başlangıç koşullarını) sıfır

kabul eder ve yalnızca giriş-çıkış ilişkisine odaklanır. Gerçek dünyadaki karmaşık

sistemlerde, sistemin iç dinamiklerini ve başlangıçtaki fiziksel durumlarını hesaba

katmak hayati önem taşır. Modern kontrol teorisi, sistemi dışarıdan gözlemlemek yerine,

sistemin içsel mekanizmalarını (iç değişkenleri) matematiksel modele dahil ederek bu

eksikliği giderir. Modern kontrolün temelini, yüksek dereceli karmaşık denklemleri

yönetilebilir parçalara ayırmak oluşturur. n. dereceden bir diferansiyel denklemle ifade

edilen bir sistem, modern teoride n adet birinci dereceden diferansiyel denkleme

dönüştürülür. Bu yapı, doğrusal dinamik sistemlerin vektör-matris formunda

gösterilmesini sağlar. Böylece durum uzay modeli vektör matris formunda;

dx
dt
= Ax(t) + Bu(t) | (12)

yazılırlar. Çıkış denklemi ise;
y(t) = Cx(t) + Du(t) | (13)
ile verilir. Anxn , Bnxr , Cmxn , Dmxr | zamanla değişmeyen sistemler için sabit katsayı

matrisleridir. xnx1 durum vektörüdür. u(t) giriş/kontrol işaretidir. y(t) ise sistemin çıkış

vektörüdür. n. dereceden sistem analiz ve tasarımı bu denklem takımları üzerinden

yapılır. Modern kontrol teorisi olarak isimlendirilme nedeni olarak kısaca, durum uzay

denklemleri kullanılarak yapılan analiz ve tasarımlarda özellikle lineer cebir teknik ve

yöntemlerinin çok yaygın olarak kullanılması ve sürekli olarak geliştirilmesidir. Durum-

uzay analizinde dinamik sistem modellemesinde üç tip değişken göz önünde

bulundurulur:

- Giriş değişkenleri,
- Çıkış değişkenleri,
- Durum değişkenleri/İç değişkenler

Aynı bir sistem için tek bir durum-uzay gösterimi yoktur. Durum değişken sayısı aynı

kalmakla beraber aynı sistem için sonsuz sayıda durum-uzay gösterimi elde edilebilir. Bir

sisteme ait durum uzay gösterimi elde edilirken kullanılan yöntemlere ve kullanılabilecek

lineer dönüşümlere bağlı olarak farklı katsayılar matrisleri elde edilir. Ancak aynı bir sistem için katsayılar matrisleri farklı olmakla beraber tek bir transfer fonksiyonu vardır

ve karakteristik denklemleri aynıdır. Eğer durum denklem elde etme yöntemi veya lineer

dönüşüm sonunda transfer fonksiyonu veya karakteristik denklem değişir ise o sistem

artık farklı bir sistem demektir, hata yapılmıştır. Bu bilgiler göz önüne alınarak devre

analizi yapılır.

Şekil 3.10: Düşürücü Dönüştürücünün Anahtarı İletimde

Düşürücü devreden yapılan analizinden ve alınan Kirchhoff Çevre Gerilim Yasası’ndan;

Vin = lL ⋅ RL + L

dIL
dt
+ IR ⋅ R | (14)

olarak elde edilir. Kapasitör akımının da;

IC = C

dVC dt | (15)

olduğunu bilinmktedir. Vout ve VC parallel olduklarından dolayı eşittir ve;

VC = IR ⋅ R | (16)

veya

IR =

VC R | (17)

olarak yazılabilir. Kirchhoff Düğüm Akım Yasası;

IR = IL − IC | (18)

elde edilir. Dolayısıyla kapasitor gerilimi;

C

dVC dt
= IL −
VC R | (19)

dVC dt
=

IL C
−
VC RC | (20)

olacaktır. Endüktör akımı ise;

L

dIL
dt
= Vin − lL ⋅ RL − VC | (21)

dIL dt
=

Vin L
−

lL⋅RL L
−
VC L | (22)

şeklinde olacaktır. Ve çıkış gerilimi de;

vout = VC | (23)

şeklinde olacaktır. Dolayısıyla sistem iletimde olduğu sürece;
[
dIL
dt
dVC
dt

] = [
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
RC] ⋅ [
IL
vc

] + [

1
L
0
] ⋅ Vin | (24)

ve
vout = y = [0 1][

IL
vc
] | (25)

ifadeleri elde edilir.

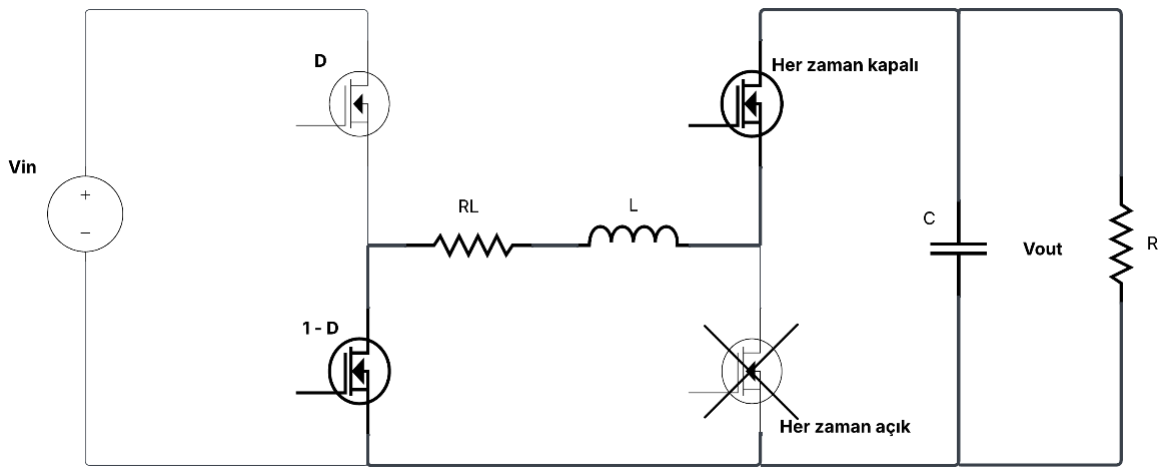
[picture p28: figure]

Sekil 3.11: Düşürücü Dönüştürücünün Anahtarı kesimde

Anahtarın kesime gittğinde ise Vin = 0 olup endüktör akımı;

dIL
dt

= −

lL⋅RL
L

−

VC
L

(26)

olarak, kapasitör gerilimi ise;

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
(27)

olarak elde edilir. Dolayısıyla;
[
dIL
dt
dVC
dt

] = [
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
RC] ⋅ [
IL
vc

] + [

0
0
] ⋅ Vin | (28)

ve
Vout = y = [0 1][

IL
vc
] | (29)

ifadeleri elde edilir. Şimdi ise bu iki durum uzay modelinin ortalama bir model elde etmek

için bazı işlemlerin yapılması gerekmektedir.

Anahtarın iletimde olduğu ifadeleri d(t) ile, kesimde olduğu ifadeleri ise (1-d(t)) ile çarpıp ardından ortalama durum uzay modeli çıkarılır. İki durumların da çarpıldığı ve ortalama

uzay modeli çıkarıldığı zaman, aşağıdaki ortalama durum uzay modeli;
[
dIL
dt
dVC
dt

] = [
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
RC] ⋅ [
IL
vc

] + [

d(t)
L
0
] ⋅ Vin | (30)

ve
Vout = y = [0 1][

IL
vc
] | (31)

olarak elde edilir. Her iki ifadenin çarpılıp topladıktan sonra, d(t) ve (1-d(t)) ifadelerin

içinde birbirlerini sadeleşmiş olacak. Anahtarın kesimde olduğuna Vin = 0 olacağı için,

ortalama durum uzay modelinde B matrisinin içerisinde d(t)
L

ifadesi kalacaktır.

Elde edilen ortalama durum uzay modelinde B matrisinin içerisinde d(t) değişkeni vardır.

Dolayısıyla bu değişken sabit olmadığında bu modeli doğrusal olmayan bir model yapar.

Böyle durumlarda da bir durum uzay modelinde sonsuz transfer fonksiyonu elde

edilebilir. Sistemin herhangi bir çalışma noktasında doğrusallaştırılmasıyla elde edilecek

küçük sinyal durum uzay modeli tek bir transfer fonksiyonuna sahip olacaktır ve bu

transfer fonksiyonu ile sistemin o çalışma noktasında analizi yapılabilir. Dolayısıyla

düşürücü dönüştürücünün küçük sinyal durum uzay modeli;
[

d̃IL
dt
d̃Vc
dt

] = [
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
RC] ⋅ [
IL

̃
Vc

̃

] + [

Vin
L
0
] ⋅ d̃(t) | (32)

ve
Ṽout = y = [0 1] ⋅ [
IL

̃
Vc

̃

] | (33)

şeklinde elde edilir. Küçük sinyal durum uzay modelinden düşürücü (buck)

dönüştürücünün trafnsfer fonksiyonunu (G(s));

G(s) = Vout ̃(s)
d̃(s)

= C ⋅ (sI − A)

−1
⋅ Bd | (34)

formülü kullanılarak elde edilebilir. Küçük sinyal durum uzay modelinden; A = [
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
RC] | (35)

Bd = [

Vin
L
0
] | (36)

C = [0 1] | (37)

olarak A, B ve C matrisi olarak elde edilir. Ve buradan;

Vout ̃(s)
d̃(s)

= C ⋅ (sI − A)

−1

⋅ Bd = [0 1] ⋅ (s [
0 1
1 0

] − [
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
RC])

−1
⋅ [

Vin
L
0

] (38)

olarak elde edilir.

Düşürücü Dönüştürücünün küçük sinyal transfer fonksiyonu matlab kodu;

clear all, clc

format long

Vin= 48;

L= 150e-6;

RL=0.01;

C= 34.722e-6;

R=1.2;

A=[-RL/L -1/L; 1/C -1/(R*C)];

B=[Vin/L; 0];

C=[0 1];

D=[0];

[b,a] = ss2tf(A,B,C,D)

SYS = tf(b,a)

kullanılarak;

Vout ̃(s)
d̃(s)

=

9.216 × 10⁹

s

2 + s ⋅ 2.407 × 10⁴ + 1.936 × 10⁸

(39)

olarak bu alçaltıcı dönüştürücünün küçük sinyal transfer fonksiyonu elde edilir. Ardından

bu koda;

figure()

step(SYS)

eklenerek;

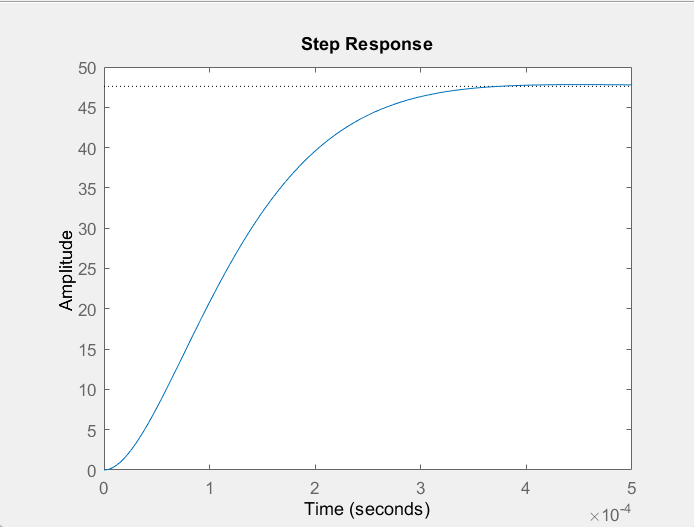
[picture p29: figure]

Şekil 3.12: Düşürücü Modu Küçük Sinyal Transfer Fonksiyon Basamak Cevabı

olarak küçük sinyal transfer fonksiyonunun basamak cevabı elde edilir. Bu hesaplanan

transfer fonksiyon devrenin buck modunda çalşırken ki transfer fonksiyonudur. Devreyi

kontrol etmek üzere iki PI kontrolcu tasarlanacak. Hem düşürücü hem de yükseltici modu

için. Dolayısıyla aynı işlemler yükseltici modu için de yapılıp ardından bu modun da

transfer fonksiyonu çıkarılır.

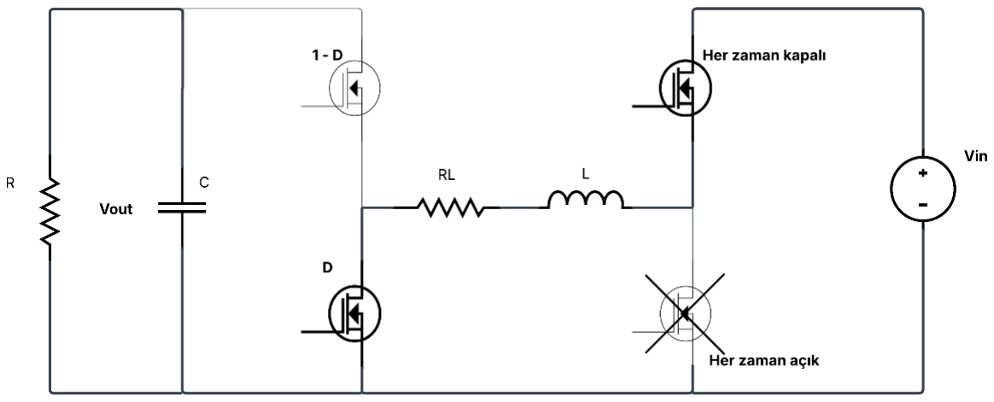
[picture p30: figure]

Şekil 3.13: Yükseltici Dönüştürücünün Anahtarı İletimde

Yükseltici devrenin Vout ile Vin bağıntısı;

vout

Vin

=

1
1−D

(40)

olarak elde edilir. Düşürücü devresinde de olduğu gibi bu devrede de anahtarın iletim ve

kesimde oldup her iki durumun da analiz edilmesi gerekmektedir. Dolayısıyla system

iletimdeyken endüktör akımı:

dIL
dt

=

Vin
L

−

lL⋅RL
L

(41)

olarak edle edilir. Kapasitör gerilimi ise:

dVC
dt

= −

VC
RC

(42)

şeklinde olduğunu gözükmektedir. Dolayısıyla
[
dIL
dt
dVC
dt

] = [
−

RL
L

0

0 −

1

RC] ⋅ [
IL
vc

] + [

1
L
0
] ⋅ Vin | (43)

ve
vout = y = [0 1][

IL
vc
] | (44)

elde edilir.

Şekil 3.14: Yükseltici Dönüştürücünün Anahtarı Kesimde

Dönüştürücünün anahtarı kesimde olduğunda ise endüktör akımı;

dIL
dt

=

Vin
L

−

lL⋅RL
L

−

vc
L

(45)

Elde edilir. Kapasitör gerilimi ise;

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
(46)

şeklinde elde edilir. Bu şekilde A matrisinde değişiklikler yaşanarak;
[
dIL
dt
dVC
dt

] = [
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
RC] ⋅ [
IL
vc

] + [

1
L
0
] ⋅ Vin | (47)

ve

vout = y = [0 1][

IL
vc
] | (48)

şeklinde ifadeler elde edileceğini gözükmektedir. Bir önceki sistemde de yapıldığı gibi

burada da ortalama durum uzay model elde edilebilmek için anahtarın iletimde

olduğundaki matris ifadeleri d(t) ile, kesimde olduğu ifadeleri ise (1-d(t)) ile çarpılır ve;
[

d̃IL

dt
d̃Vc

dt

] = [
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
RC ] ⋅ [
IL

̃
Vc

̃

] + [
Vo
L
−

IL
C
] ⋅ d̃(t) | (49)

ve
Ṽout = y = [0 1] ⋅ [
IL

̃
Vc

̃

] | (50)

olarak sistemin küçük sinyal durum uzay modeli elde edilir. D’ye göre türev alındıktan

sonra B matrisi yukarıdaki hali alır. Bu sistemin küçük sinyal durum uzay modeli A, B

ve C matrisleri;
A = [
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
RC ], | (51)

Bd = [
Vout
L
−

IL

RC] | (52)

olarak elde edilir. Ayrıca;

IL =

Vout
(1−D)

2⋅R

(53)

ve

vout =

Vin
(1−D)

(54)

olduğu bilinmektedir. Dolayısıyla; Bd = [

Vin
L(1−D)
Vin
(1−D)
2⋅RC] | (55)

ve
C = [0 1] | (56)

şeklinde olup bu sistemin;

Vout ̃(s)
d̃(s)

= = [0 1] ⋅ (s [
0 1
1 0

] − [
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
RC ])

−1
⋅ [

Vin
L(1−D)
Vin
(1−D)
2⋅RC] | (57)

olarak elde edilir.

Dolayısıyla Yükseltici Dönüştürücünün MATLAB kodu;

clear all, clc

format long

Vin= 12;

L= 150e-6;

RL=0.01;

C= 260e-6;

R=19.2;

d=0.75;

A=[-RL/L -(1-d)/L; (1-d)/C -1/(R*C)];

B=[Vin/((1-d)*L); -Vin/((1-d)^2*R*C)];

C=[0 1];

D=[0];

[b,a] = ss2tf(A,B,C,D)

SYS = tf(b,a)

kullanılarak;

Vout ̃(s)
d̃(s)

=

−3.846 × 10⁴

⋅ s + 3.051 × 10⁸

s

2 + s ⋅ 267 + 1.616 × 10⁶

(58)

yükseltici dönüştürücünün küçük sinyal transfer fonksiyonu elde edilir. Ayrıca bu koda;

figure()

step(SYS)

eklenerek;

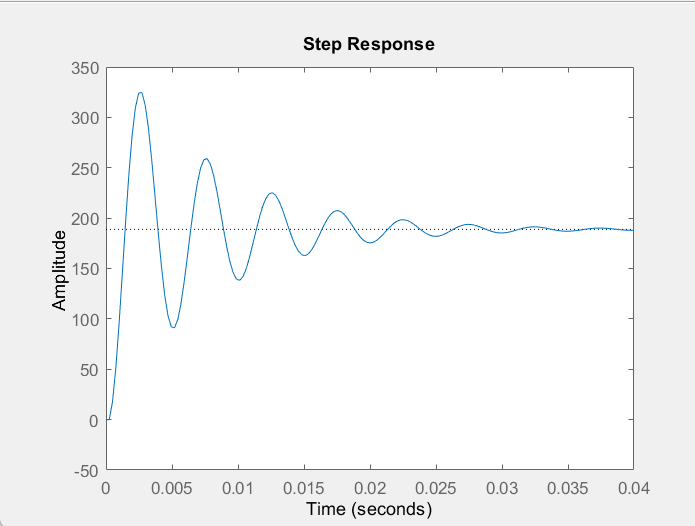
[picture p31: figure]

Şekil 3.15: Yükseltici Modu Küçük Sinyal Transfer Fonksiyon Basamak Cevabı

olarak küçük sinyal transfer fonksiyonunun basamak cevabı elde edilir.

### 3.6. Sistemin Kontrolü

Bu projede kontrol biriminin temel görevi, dönüştürücünün hangi yönde çalışacağını

belirlemek ve akımın enerji depolama sistemleri arasında doğru şekilde aktarılmasını

sağlamaktır. Başka bir deyişle, kontrolcü hem dönüştürücünün çalışma modunu seçmekte

hem de güç akışını güvenli ve verimli bir biçimde yönetmektedir.

Projede, kontrol için Texas Instruments’ın UCD3138 dijital kontrol entegresi

kullanılacaktır. Bu kontrolcü, ADC modülleri kullanılarak doğrudan gerilim ve akım

ölçümleri yapılır. Akım değerleri sürekli olarak izlenir ve belirlenen maksimum limit

aşıldığında anında güvenlik önlemleri devreye girer. Bu durumda PWM sinyalleri

kesilerek sistem koruma altına alınır.

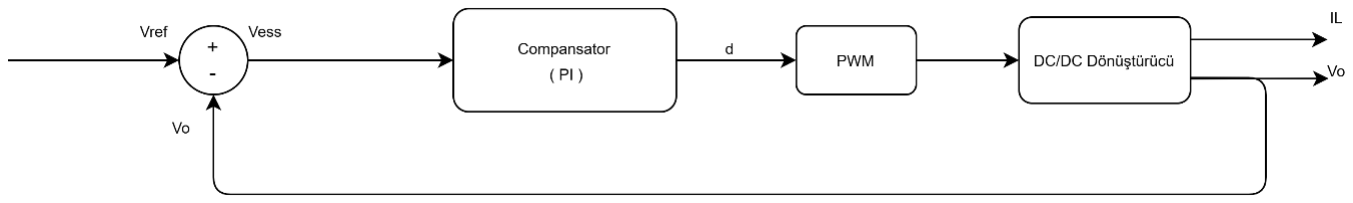
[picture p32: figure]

Şekil 3.16: Kontrol Sisteminin Blok Diyagramı.

Projede tek bir döngüye sahip olan gerilim mod (voltage mode control) PI bir denetleyici

kullanıldı. Sistem kapalı bir döngü olarak tasarlandığından dolayı sürekli izleme ve kendi

kendini düzeltme özelliği taşımaktadır. Şekilde de görüldüğü üzere ölçülen gerilim değerleri referans değerleri ile karşılaştırılarak hata sinyali hesaplanır. Bu projede, hata

sinyalinin küçük değerlerde sürekli anahtarlamaya yol açmaması için ölü bölge

(deadband) yöntemi kullanılacaktır. Böylece, hata değeri ölü bölge içinde kaldığında

denetleyici tepki vermez ve gereksiz anahtarlama engellenir.

Vess = Vref – Vo | (59)

Denklem 3’te görüldüğü üzere referans gerilim değeri (Vref) ve ölçülen gerilim değeri

(Vo) arasından alınan farkından elde edilen hata sinyali (Vess) PI denetleyiciye giriş olarak

uygulanıp Kp katsayısı hata sinyali ile Ki katsayısı ise hata sinyalinin integraliyle

çarpılanarak çıkışta mosfetlerin görev oranını temsil eden kontrol sinyali (Vd) üretilir:

Vd(t) = Kp × Vess + Ki × ∫ Vess(t)dt | (60)

Bu sinyal daha sonra PWM devresine gönderilir ve genişlik modülasyonu sinyali üretilir.

Böylece dönüştürücü kontrol edilebilir hâle gelir. PWM sinyalleri gate driver’lar

aracılığıyla mosfetler uygulanır ve mosfetler uygun şekilde anahtarlama yaparak çift

yönlü güç akışı güvenli ve kararlı bir biçimde sağlanır.

### 3.6.1. PI Denetleyicinin Katsayılarının Belirlenmesi

PI denetleyici katsayıları, her iki dönüştürücü için de MATLAB ortamında elde edilen

küçük sinyal transfer fonksiyonu ve kapalı çevrim transfer fonksiyonu üzerinden Bode

Diyagramı kullanılarak belirlenmiştir. Küçük sinyal transfer fonksiyonu alındıktan

sonra PI denetleyici kullanılarak açık ve kapalı döngünün transfer fonksiyonu çıkarıldı.

Katsayıların belirlenmesinde Bode Diyagramı üzerinden faz marjini ve kazanç marjini

kriterleri baz alınarak sistemin kararlılığı teorik olarak doğrulanmıştır. Dolayısıyla

alçaltıcı modu çalışmasında PI denetleyicinin kontrolcü katsayıları Kp = 0.0017 ve Ki

= 75 olarak belirlenmiştir.

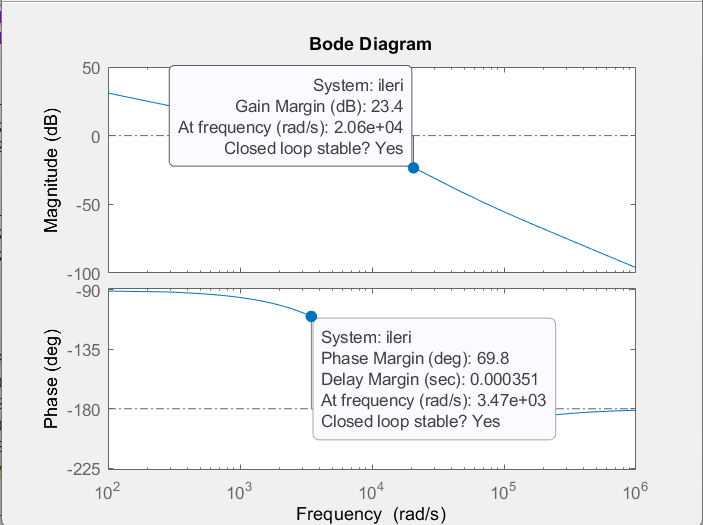
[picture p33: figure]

Şekil 3.17: Buck Dönüştürücü Açık Çevrim Faz ve Kazanç Marjini

Bu katsayılar faz marjinin 180 dereceye yakın olmayacağı şekilde belirlenmiştir.

Yükseltici modun küçük sinyal transfer fonksiyonunda pay kısmında bulunan s

domeni’nden dolayı işlerin biraz zorlaşacağı görülmüştür. Sistemin kararsızlığa

gitmesmesi için Kp = 0.00125 olarak Ki = 0.198 olarak belirlendi. Belirlenen bu

katsayılar sistemin nasıl çalışacağına dair karar verecektir.

Şekil 3.18: Boost Dönüştürücü Açık Çevrim Faz ve Kazanç Marjini

Şekil 4.8’de bulunan yükseltici dönüştürücünün açık çevrim bode diyagramına bakılırsa

faz marjinin 90.7 derece, kazanç marjininin ise 17 dB olacağı görülmektedir.

### 3.7. Haberleşme Yöntemleri

Tasarlanan çift yönlü DA-DA dönüştürücünün, bir araç elektrik mimarisi veya

laboratuvar test altyapıları ile entegre edilebilmesi amacıyla endüstriyel haberleşme

yöntemleri kullanılmıştır. Mild-Hibrit sistemlerde güç dönüştürücüler yalnızca enerji

aktarımı yapan pasif birimler değil, aynı zamanda çalışma durumları sürekli izlenmesi ve

gerektiğinde dış sistemler tarafından kontrol edilmesi gereken akıllı güç modülleridir. Bu

nedenle tasarımda, izleme (monitoring), yapılandırma (configuration) ve hata teşhisi

(fault diagnosis) fonksiyonlarını destekleyen dijital haberleşme altyapısı ön planda

tutulmuştur.

Bu kapsamda, dijital güç kontrolcüsü (UCD3138) ile üst seviye kontrol birimleri veya

test sistemleri arasındaki veri iletişimi, güç elektroniği uygulamalarında yaygın olarak

kullanılan PMBus (Power Management Bus) protokolü üzerinden gerçekleştirilmiştir.

PMBus, I²C tabanlı bir haberleşme standardı olup, çoklu güç modüllerinin tek bir

haberleşme hattı üzerinden yönetilebilmesine olanak sağlamaktadır. Bu protokol

aracılığıyla giriş ve çıkış gerilimleri, akım değerleri, sıcaklık bilgileri ve çalışma durumu

gibi kritik parametreler anlık olarak okunabilmekte; aşırı akım, aşırı gerilim veya termal

hata gibi durumlar dijital olarak raporlanabilmektedir. Bu özellik, sistemin güvenilirliğini

artırmanın yanı sıra bakım ve test süreçlerini de kolaylaştırmaktadır.

Yazılım geliştirme, sistem doğrulama ve hata ayıklama (debug) aşamalarında ise UART

ve JTAG arayüzlerinden faydalanılmıştır. UART arayüzü, temel çalışma parametrelerinin

izlenmesi ve test senaryoları sırasında hızlı veri aktarımı sağlamak amacıyla

kullanılmıştır. JTAG arayüzü ise mikrodenetleyici ve dijital güç kontrolcüsünün dahili

kayıtlarına (register) doğrudan erişim imkânı sunarak, yazılımın adım adım çalıştırılması,

kesme (interrupt) ve kontrol döngülerinin doğrulanması gibi kritik geliştirme süreçlerinde

etkin bir araç olarak kullanılmıştır. Bu haberleşme altyapısı sayesinde, sistemin hem

geliştirme hem de işletme aşamalarında izlenebilir ve kontrol edilebilir bir yapı elde

edilmiştir.

### 3.8. Yazılımlar

Sistemin kalbini oluşturan dijital kontrol algoritması, UCD3138 mikrodenetleyicisi

üzerinde gömülü yazılım (Firmware) olarak koşturulmaktadır. Yazılım mimarisi;

sistemin başlatılması, durum makinesinin (State Machine) yönetimi, hata izleme ve

PMBus haberleşmesi gibi görevleri yerine getiren "Ana Döngü" ve kontrol

parametrelerinin anlık güncellendiği "Kesme Servis Rutinleri (ISR)" olmak üzere iki

temel katmandan oluşmaktadır.

### 3.8.1. Yazılım Akış Şeması

Sistemin genel çalışma mantığını ve karar mekanizmalarını gösteren yazılım akış

diyagramı Şekil 3.6'da sunulmuştur. Bu algoritma, cihaz enerjilendiği andan itibaren

sürekli bir döngü içerisinde çalışarak güç akışını güvenli bir şekilde yönetir.

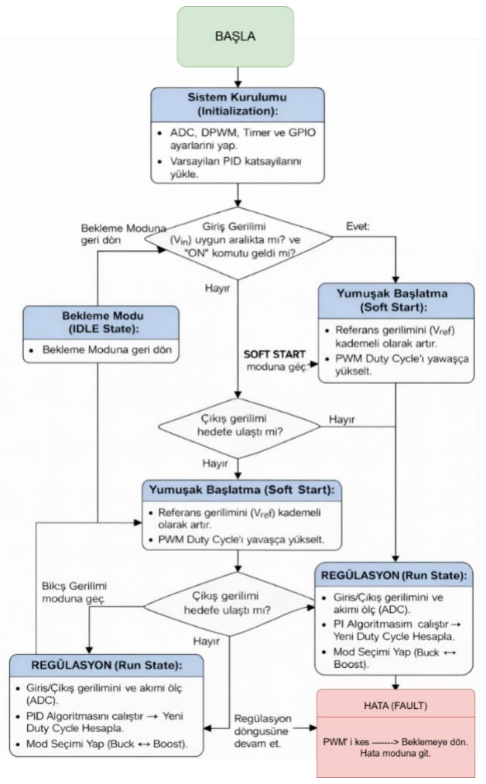
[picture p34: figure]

Şekil 3.19: Yazılım Akış Şeması

### 3.8.2. Yazılım Modüllerinin Açıklaması

Akış şemasında belirtilen temel blokların ve uygulanan algoritmaların detayları

şunlardır:

### 3.8.2.1. Başlatma ve Konfigürasyon (Initialization):

İşlemci enerjilendiğinde ilk olarak PMBus adresi tanımlanır ve çevre birimleri

(Peripherals) kurulur. Bu aşamada ADC modülü, gerilim ve akım sensörlerini okuyacak şekilde kalibre edilir. DPWM modülleri, MOSFET'lerin anahtarlama frekansı (100 kHz) ve Ölü Zaman (Dead-Time) süreleri girilerek aktif hale getirilir.

### 3.8.2.2. Durum Makinesi (State Machine):

Yazılımın ana omurgasıdır. Sistem o an hangi görevde olduğunu (Bekleme, Kalkış,

Çalışma veya Hata) bir durum değişkeni ile takip eder.
Idle (Bekleme): PWM çıkışları kapalıdır. İşlemci sadece giriş gerilimini izler ve

PMBus üzerinden gelecek "Başlat" komutunu bekler. Güç tüketimini azaltmak için

düşük güç modunda çalışır.

Soft Start (Rampa): Çıkış kapasitörlerinin ani akım çekmesini (Inrush Current)

engellemek için, çıkış gerilimi referansı 0V'dan 12V'a (veya 48V'a) belirli bir rampa

eğrisiyle yükseltilir. Bu süreçte PI kontrolcü kapalı çevrim çalışmaya başlar.

### 3.8.2.3. Mod Seçimi ve PI Kontrolü:

Regülasyon aşamasında yazılım, giriş ve çıkış gerilimlerini karşılaştırarak

dönüştürücünün topolojisini dinamik olarak değiştirir:

- Vin > Vout ise Buck Modu aktif edilir.
- Vin < Vout ise Boost Modu aktif edilir.

Bu mod geçişleri sırasında çıkışta dalgalanma olmaması için PI katsayıları (Kp, Ki) her

mod için ayrı ayrı optimize edilmiş tablolardan (Look-up Table) çekilir.

### 3.8.2.4. Hata Yönetimi (Fault Handling):

Sistemin güvenliği için "Hızlı Kesme" (Fast Interrupt) mekanizması kullanılır.

ADC'den okunan akım veya gerilim değerleri belirlenen limitleri aştığı anda, yazılım

ana döngüyü terk ederek FAULT durumuna geçer. Bu durumda PWM sinyalleri

donanımsal olarak (Trip Zone) milisaniyeler içinde kesilir ve sistemin soğuması veya

hatanın giderilmesi beklenir.

### 3.9. Ekonomik Yapılabilirilik Analizi

Bu bölümde, geliştirilen 48V–12V çift yönlü DA-DA dönüştürücü sisteminde

kullanılan donanım bileşenlerinin maliyet analizi yapılmış ve projenin ekonomik açıdan

uygulanabilirliği değerlendirilmiştir. Çalışma kapsamında kullanılan tüm malzemeler;

sistemin işlevsel gereksinimlerini karşılayacak, aynı zamanda maliyet-performans

dengesi gözetilecek şekilde seçilmiştir.

### 3.9.1. Malzeme Listesi ve Bütçe

Projenin prototip üretimi için gerekli olan kritik bileşenler, kullanım amaçları ve birim

maliyetleri Tablo 3.4’te listelenmiştir. Fiyatlandırma, uluslararası elektronik

komponent distribütörlerinin (DigiKey, Mouser vb.) güncel perakende satış fiyatları

baz alınarak Dolar ($) cinsinden yapılmıştır.

Malzemenin adı | Kullanım amacı | Birim fiyatı ($) | Adedi | Fiyatı ($)
UCD3138RGC | Kontrol Kartı: Sistemi yöneten, PID algoritmasını işleyen 64-Pin Dijital Güç Kontrolcüsü. | 16.88 | 1 | 16.88
CSD19536KCS | Güç Katı: 100V, Düşük RDS(on) N-Kanal MOSFET (TO-220). | 5.36 | 4 | 21.44
UCC27211ADR | Sürücü Katı: 120V Bootstrap destekli 4A Half-Bridge Gate Sürücü. | 2.22 | 2 | 4.44
Wurth 7443641000 | Güç Katı: 10µH, 30A Yüksek Akım Korumalı Güç İndüktörü. | 8.97 | 1 | 8.97
OPA2211AID | Geri Besleme: Yüksek hassasiyetli, düşük gürültülü (1.1nV) Ray-to-Ray Op-Amp. | 12.80 | 2 | 25.60
Giriş/Çıkış Kap. | Filtreleme: Yüksek voltaj dayanımlı (100V) Elektrolitik ve Seramik kapasitör seti. | 1.50 (ort.) | 8 | 12.00
4-Katmanlı PCB | Devre Kartı: Özel empedans kontrollü prototip PCB üretimi. | 25.00 | 1 | 25.00
Konnektör/Pasifler | Yardımcı: Yüksek akım klemensleri, şönt dirençler ve SMD malzemeler. | 15.00 | 1 | 15.00
TOPLAM | | | | 129.33 $
Tablo 3.20: Malzeme Listesi

### 3.9.2. Maliyet ve Kalite Değerlendirmesi

Proje bütçesi kısıtlı olduğundan (öğrenci/üniversite bütçesi), malzeme seçiminde fiyat/performans dengesi gözetilmiştir. Ancak, güç elektroniği devrelerinde güvenlikten

ödün verilemeyeceği için kritik bileşenlerde (MOSFET, Sürücü ve Kontrolcü)

"Otomotiv Sınıfı" (AEC-Q) veya endüstriyel kalitede ürünler tercih edilmiştir. Daha

ucuz "tüketici sınıfı" (Consumer Grade) bileşenlerin kullanılması maliyeti %20

oranında düşürebilecek olsada, 48V sistemlerdeki termal dayanıklılık ve güvenilirlik

riskleri nedeniyle bu yola başvurulmamıştır.

Prototip maliyeti (~75$), piyasadaki hazır endüstriyel çift yönlü dönüştürücülerin

fiyatları (300$-500$ bandı) ile karşılaştırıldığında, tasarımın ekonomik olarak

uygulanabilir olduğu ve ciddi bir maliyet avantajı sağladığı görülmektedir.

### 3.9.3. Risk Analizi ve Alternatif Çözüm Stratejileri

Günümüz elektronik endüstrisinde yaşanan küresel çip krizleri ve tedarik zinciri problemleri, bu projenin gerçekleştirilmesi önündeki en büyük risktir. Özellikle

UCD3138 gibi özelleşmiş dijital kontrolcülerin stoklarının tükenmesi veya yurt

dışından temininde gümrük mevzuatı (bireysel ithalat sınırları, vergilendirme vb.)

kaynaklı gecikmeler yaşanması muhtemeldir.

Bu risklerin gerçekleşmesi durumunda projenin kesintiye uğramaması için şu Alternatif

Tasarım Yöntemleri (B-Planı) belirlenmiştir:

### 3.9.3.1. Özel Entegre Çözümleri

Dijital kontrolcü (UCD3138) temin edilemezse, aynı 4-Anahtarlı Buck-Boost

topolojisine ve PI kontrol mantığına sadık kalınarak, analog/dijital hibrit çalışan özel

güç entegrelerine geçiş yapılacaktır.

Alternatif 1: Texas Instruments LM5170: Texas Instruments tarafından geliştirilen

LM5170, yüksek güçlü otomotiv ve endüstriyel uygulamalar için tasarlanmış, çift yönlü (bidirectional) ve çift fazlı (dual-phase) bir DA-DA güç kontrol entegresidir. Özellikle

48V–12V Mild-Hibrit araç mimarileri, enerji geri kazanım sistemleri ve batarya

dengeleme uygulamalarında yaygın olarak kullanılmaktadır.

LM5170, dört anahtarlı Buck-Boost topolojisini donanımsal olarak desteklemekte olup,

hem yükseltici (Boost) hem de düşürücü (Buck) modlarda kesintisiz ve kontrollü enerji

akışını sağlayabilmektedir. Entegrenin iç yapısında yer alan akım algılama (current

sense) ve hata yükselteçleri (error amplifiers) sayesinde, sistemde PI tabanlı akım ve

gerilim | kontrolünü | mikroişlemci | desteği | ile | donanımsal | olarak

gerçekleştirilebilmektedir. Bu durum, dışarıdan karmaşık bir yazılım veya yüksek

hesaplama gücü gerektirmeden kararlı bir regülasyon sağlamaktadır.

LM5170’nin öne çıkan avantajlarından biri, yüksek anahtarlama frekanslarında

çalışabilmesi ve çok fazlı yapısı sayesinde akım dalgalanmalarını azaltarak daha düşük

çıkış dalgalanması (ripple) elde edilmesine olanak tanımasıdır. Ayrıca entegre; aşırı

akım, aşırı gerilim, kısa devre ve termal koruma gibi endüstriyel güvenlik

fonksiyonlarını kendi bünyesinde barındırarak sistem güvenilirliğini artırmaktadır.

Bu özellikleri sayesinde LM5170, dijital kontrolcüye erişilemeyen senaryolarda,

projenin hedeflediği güç seviyesi, topoloji ve kontrol yaklaşımını büyük ölçüde

koruyarak uygulanabilir ve endüstriyel olarak iyi bir alternatif sunmaktadır.

Alternatif 2: Analog Devices LTC3871: Analog Devices tarafından sunulan

LTC3871, yüksek verimlilik gerektiren çift yönlü, çok fazlı (polyphase) DA-DA

dönüştürücü uygulamaları için geliştirilmiş, endüstriyel sınıf bir güç kontrol

entegresidir. Özellikle 48V–12V araç içi enerji sistemleri, yedek güç kaynakları (UPS)

ve yüksek akımlı batarya sistemlerinde tercih edilmektedir.

LTC3871, harici MOSFET’ler ile birlikte çalışarak esnek bir güç katı tasarımı sunmakta

ve tasarımcının sistem gereksinimlerine göre akım kapasitesini ölçeklendirmesine

olanak tanımaktadır. Entegre hem Buck hem de Boost modlarında çalışabilen çift yönlü

enerji transferini desteklemekte olup, geçişler sırasında kararlılığı koruyacak şekilde

tasarlanmıştır.
İç yapısında bulunan donanımsal akım modlu kontrol mekanizması, PI karakteristiğine

sahip hata yükselteçleri aracılığıyla çıkış gerilimi ve akımını hassas bir şekilde regüle

etmektedir. Bu sayede, mikrodenetleyici veya DSP tabanlı bir kontrol altyapısı

olmaksızın, hızlı tepki süresi ve yüksek kararlılık sağlanabilmektedir.

LTC3871’in önemli avantajlarından biri, yük paylaşımı (current sharing) ve faz

kaydırmalı çalışma özellikleri sayesinde yüksek akım seviyelerinde termal yükün

sistem genelinde dengeli bir şekilde dağıtılabilmesidir. Ayrıca entegre, otomotiv ve

endüstriyel uygulamalar için kritik olan yüksek güvenilirlik, geniş çalışma sıcaklık

aralığı ve koruma mekanizmaları ile donatılmıştır.

Bu özellikleriyle LTC3871, dijital kontrolcü temelli tasarımın mümkün olmadığı

durumlarda, projenin güç elektroniği altyapısını ve PI temelli kontrol yaklaşımını

koruyarak güvenilir bir alternatif çözüm sunmaktadır.

Not: LM5170 PI kontrolü mikroişlemci desteği ile yaparken, LTC3871 PI kontrolü

analog olarak yapar.

### 3.9.3.2. Yöntem Değişikliği

Bu entegreler, dışarıdan karmaşık yazılım gerektirmeden, iç yapılarındaki donanımsal

hata amplifikatörleri ile akım ve gerilim regülasyonunu (LM5170 PI kontrolü

mikroişlemci desteği ile yaparken, LTC3871 PI kontrolü analog olarak yapar)

gerçekleştirebilmektedir. Bu değişiklik, mikrodenetleyici tabanlı "tam dijital"

esnekliğinden kısmi feragat edilmesini gerektirse de, projenin güç katı ve temel çalışma

prensipleri (Buck/Boost modları) değişmeden projenin tamamlanmasını garanti altına

alacaktır.

### 4. SİMÜLASYON (BENZETİM) ÇALIŞMALARI

### 4.1. Genel Bilgiler

Bu bölümde, tasarım projesi kapsamında gerçekleştirilen Dört Anahtarlı Buck-Boost

(FSBB) DA-DA dönüştürücünün teorik analizlerini desteklemek ve sistemin dinamik

davranışını üretim öncesinde incelemek amacıyla yürütülen simülasyon çalışmaları

sunulmaktadır. Tasarlanan dönüştürücünün analizlerinin doğruluğu, iki aşamalı bir

doğrulama süreci ile test edilmiştir.
İlk aşamada, yapılan hesaplamalarda matematiksel model denklemleri ve sistemin

transfer fonksiyonları bulunmuş ve MATLAB ortamında teorik analizlerin tutarlılığı

doğrulanmıştır. Bu süreçte, sistemin açık çevrim ve kapalı çevrim tepkileri

matematiksel model üzerinden incelenerek kontrolcü tasarımı için gerekli parametreler

optimize edilmiştir.
İkinci aşamada ise, matematiksel olarak doğrulanan parametreler kullanılarak sistemin

devre seviyesindeki davranışı PLECS (Piecewise Linear Electrical Circuit Simulation)

paket programı ile modellenmiştir. PLECS ortamında oluşturulan benzetim modelinde;

anahtarlama elemanları (MOSFET'ler), pasif bileşenler (bobin ve kapasitörler) ve

kontrol blokları, gerçeklenen donanım parametrelerine sadık kalınarak tanımlanmıştır.

### 4.2. Simülasyon Yazılımı

Bu çalışmanın benzetim ve doğrulama aşamalarında, sistemin matematiksel altyapısının

analizi için MATLAB, güç elektroniği devresinin zaman düzlemi (time-domain)

simülasyonu için ise PLECS Standalone yazılımları kullanılmıştır. Aşağıda bu

yazılımların özellikleri ve tez çalışması kapsamındaki kullanım şekilleri açıklanmıştır.

### 4.2.1. MATLAB (Matrix Laboratory)

MATLAB, sayısal hesaplama, veri analizi ve algoritma geliştirme işlemleri için yaygın olarak kullanılan, matris tabanlı bir yüksek seviyeli programlama ortamıdır. Özellikle

kontrol teorisi ve sistem modelleme alanlarındaki geniş kütüphane desteği nedeniyle

tercih edilmiştir.

Bu çalışma kapsamında MATLAB; FSBB dönüştürücünün durum uzay (state-space)

denklemlerinin çözümlenmesi, transfer fonksiyonlarının elde edilmesi ve kontrolcü

katsayılarının (PI) hesaplanması amacıyla kullanılmıştır. Ayrıca, sistemin kararlılık

analizini gösteren Bode diyagramları MATLAB ortamında çizdirilerek, teorik hesaplamaların doğruluğu devre simülasyonuna geçilmeden önce kanıtlanmıştır.

### 4.2.2. PLECS (Piecewise Linear Electrical Circuit Simulation)

PLECS, güç elektroniği sistemlerinin modellenmesi ve simülasyonu için özel olarak

geliştirilmiş bir paket programdır. SPICE tabanlı simülasyon araçlarına kıyasla, güç yarı

iletkenlerini "parçalı doğrusal" (piecewise linear) modeller olarak ele alması sayesinde,

karmaşık anahtarlamalı devrelerin simülasyonunu yüksek hızda ve kararlılıkta

gerçekleştirebilmektedir.

Proje kapsamında PLECS; tasarlanan FSBB dönüştürücünün şematik düzeyde

modellenmesi, anahtarlama elemanlarının (MOSFET) ve pasif bileşenlerin (L, C)

sisteme entegre edilmesi için kullanılmıştır. MATLAB'de hesaplanan kontrol

parametreleri PLECS içerisindeki kontrol bloklarına uygulanmış; böylece giriş gerilimi

değişimleri ve yük darbeleri gibi senaryolarda sistemin dinamik tepkisi, çıkış gerilimi

dalgalanması ve bobin akımı gibi kritik veriler bu yazılım aracılığıyla gözlemlenmiştir.

### 4.3. Simülasyon

Bu çalışmada analitik olarak elde edilen transfer fonksiyonlarının doğruluğu, PLECS simülasyon ortamında yapılan testler ile doğrulanmıştır. Önceki bölümlerde

matematiksel olarak çıkarılan transfer fonksiyonları kullanılarak sistemin dinamik

modeli oluşturulmuş ve ilgili parametreler simülasyon ortamına aktarılmıştır.

Gerçekleştirilen simülasyonlar sonucunda, sistemin geçici ve kararlı hâl tepkilerinin

teorik hesaplamalar ile yüksek uyum gösterdiği gözlemlenmiştir. Elde edilen frekans ve

zaman alanı cevapları incelendiğinde, analitik hesaplamalar ile PLECS ortamında elde

edilen transfer fonksiyonlarının örtüştüğü ve sistem davranışının beklenen şekilde

gerçekleştiği doğrulanmıştır.

Bu sonuçlar, çıkarılan transfer fonksiyonlarının sistemi doğru bir şekilde temsil ettiğini

ve yapılan matematiksel modellemenin geçerliliğini ortaya koymaktadır.

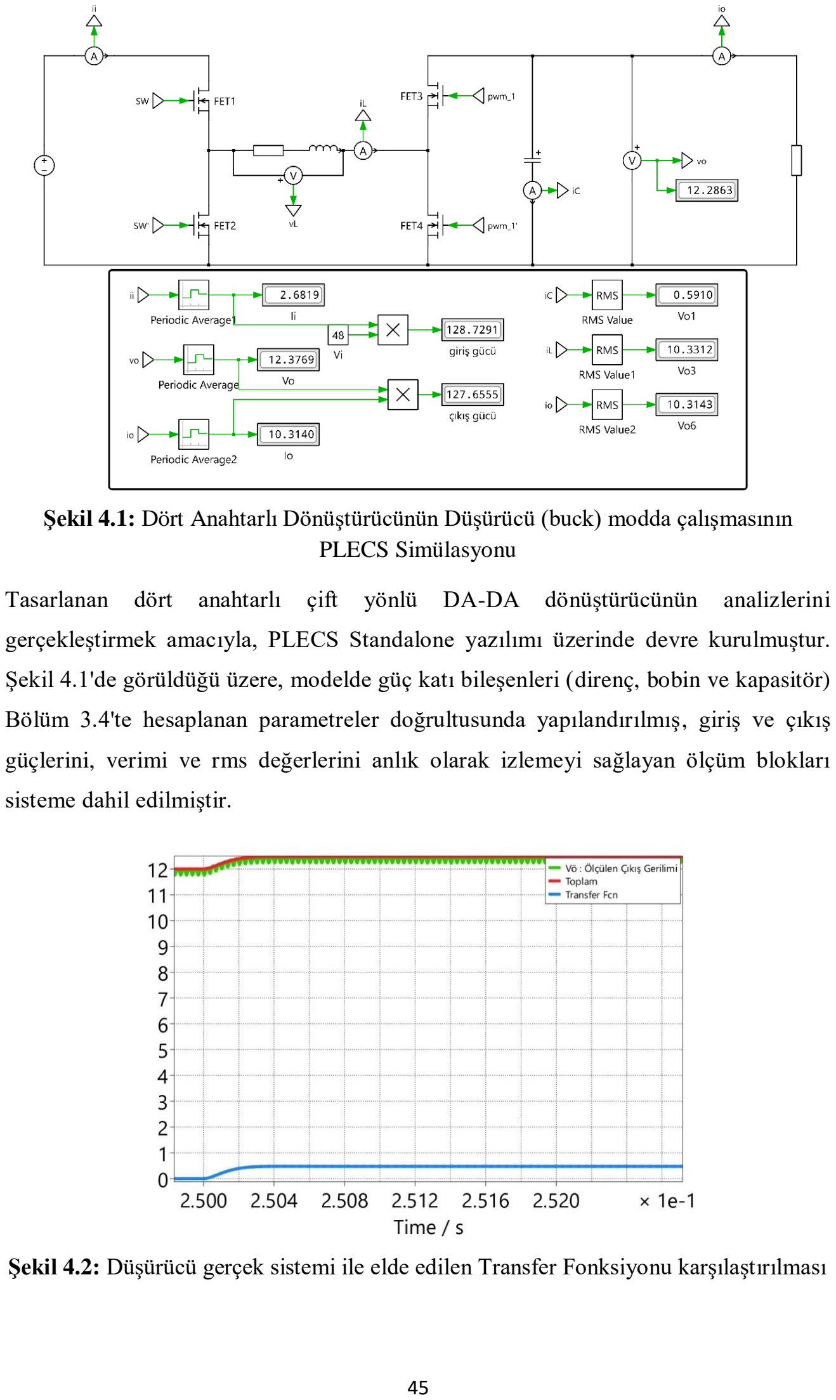
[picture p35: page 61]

Şekil 4.1: Dört Anahtarlı Dönüştürücünün Düşürücü (buck) modda çalışmasının PLECS Simülasyonu

Tasarlanan | dört | anahtarlı | çift | yönlü | DA-DA dönüştürücünün | analizlerini

gerçekleştirmek amacıyla, PLECS Standalone yazılımı üzerinde devre kurulmuştur.

Şekil 4.1'de görüldüğü üzere, modelde güç katı bileşenleri (direnç, bobin ve kapasitör)

Bölüm 3.4'te hesaplanan parametreler doğrultusunda yapılandırılmış, giriş ve çıkış

güçlerini, verimi ve rms değerlerini anlık olarak izlemeyi sağlayan ölçüm blokları

sisteme dahil edilmiştir.

Şekil 4.2: Düşürücü gerçek sistemi ile elde edilen Transfer Fonksiyonu karşılaştırılması

Ardından daha önce çıkarılan küçük sinyal transfer fonksiyonu ile gerçek sistemin

karşılaştırılaması gerçekleştirildi. Bu karşılaştırma çıkarılan küçük sinyal transfer

fonksiyonun doğru olup olmadığı gösterecektir.

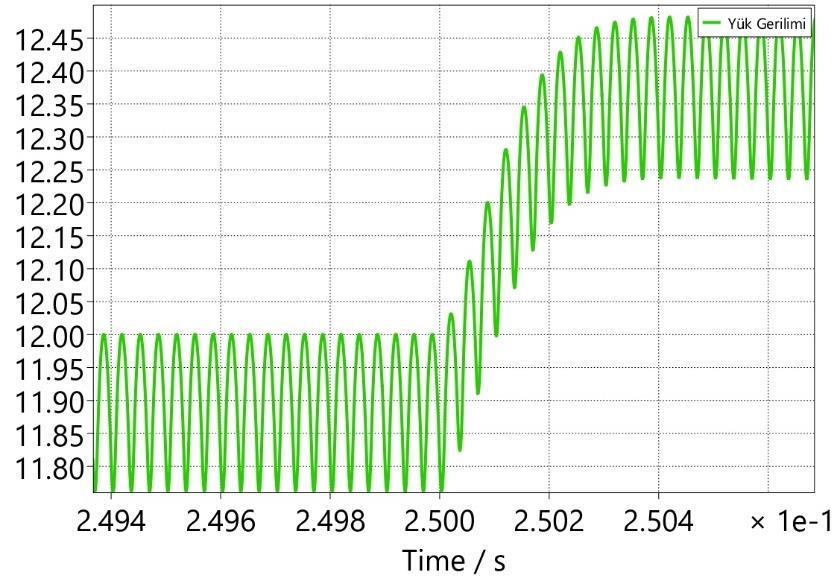
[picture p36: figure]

Şekil 4.3: Düşürücü Modu Yük Gerilimi

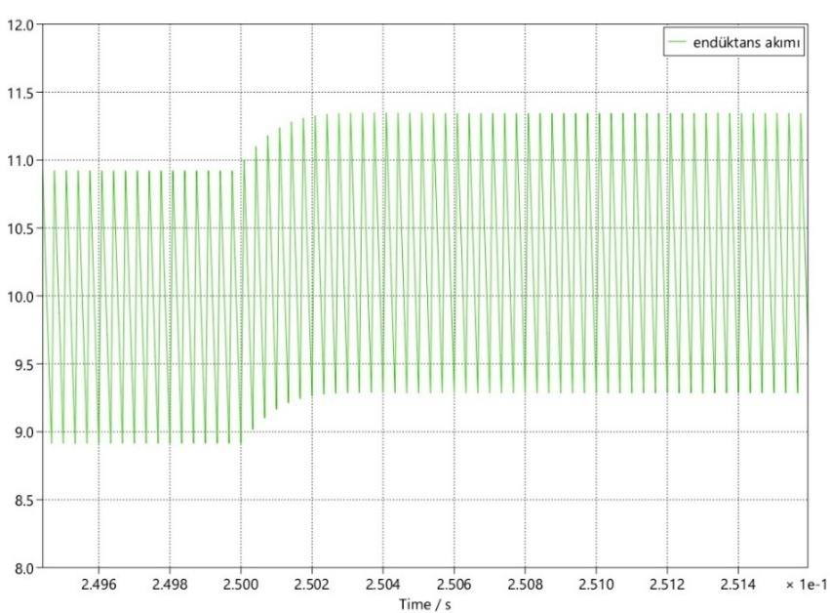
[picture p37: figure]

Şekil 4.4: Düşürücü Modu Endüktans Akımı

Ardından şekil 4.3 ve 4.4’te de görüldüğü üzere grafikler üzerinden yük gerilimi ve

endüktans akımının ripple oranları takip edildi.

Şekil 4.5: Kullanılan Kontrol Bloğu

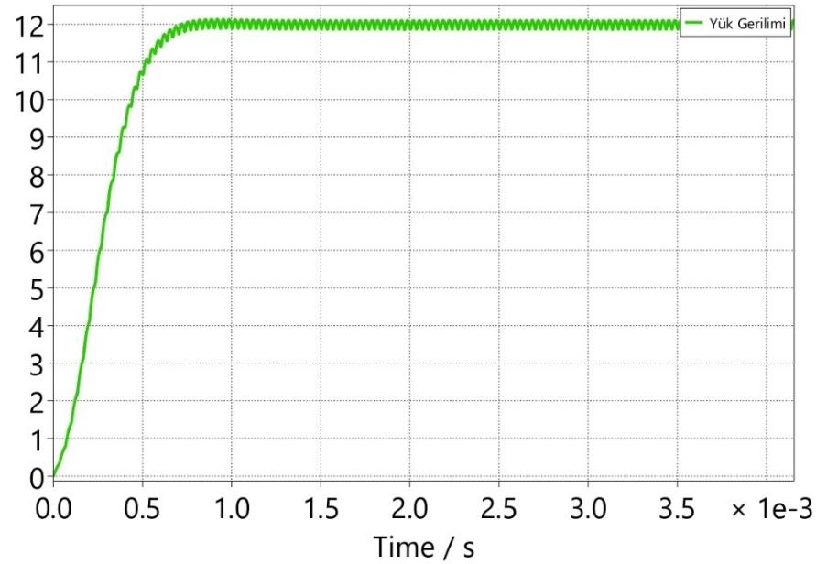
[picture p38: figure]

Şekil 4.6: PI Denetleyici kullanılarak Düşürücü Modu Yük Gerilimi

En son tasarlanan şekil 4.5’te görünen kontrol bloğu kullanıldı. Referans değeri 12V ve

seçilen Kp, Ki katsayılarını kullanılarak sistemin kararlı çalışıp çalışmayacağı control

edildi.

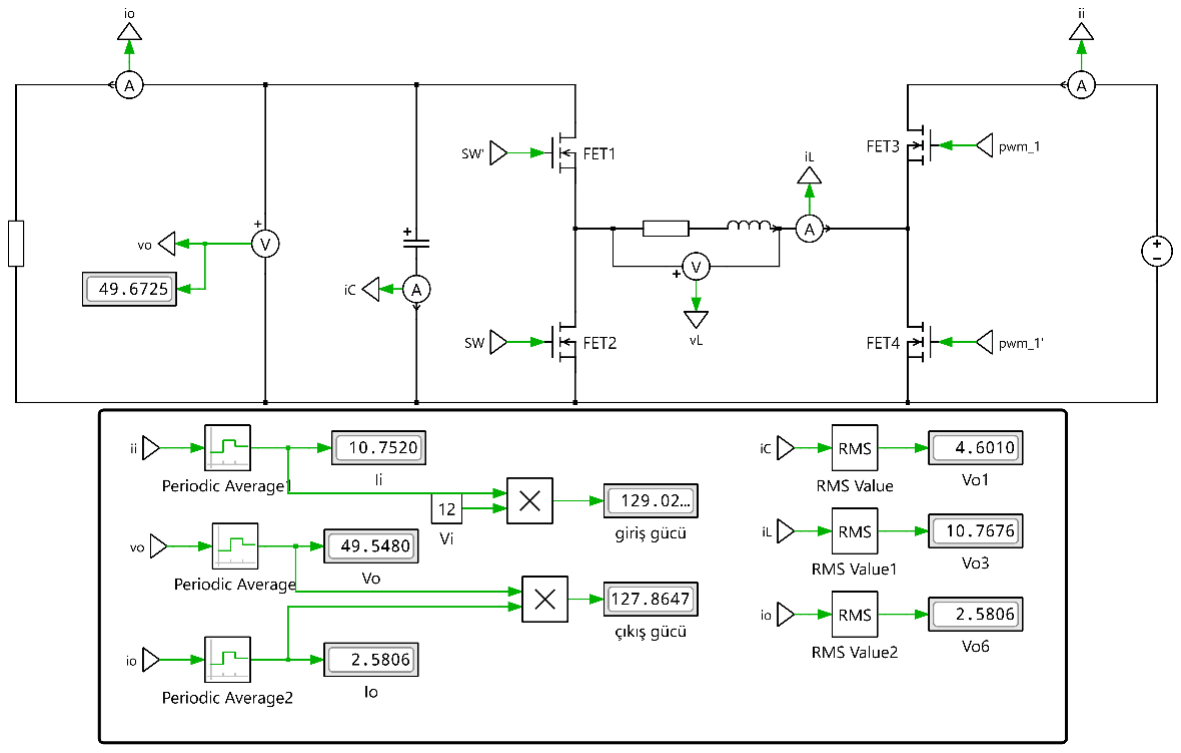
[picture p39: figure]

Şekil 4.7: Dört Anahtarlı Dönüştürücünün Yükseltici (boost) modda çalışmasının PLECS Simülasyonu

Aynı şekilde dönüştürücünün yükseltici modunda çalışırken devre modeli tasarlandı.

Bölüm 3.4’te hesaplanan değerler kullanıldı.

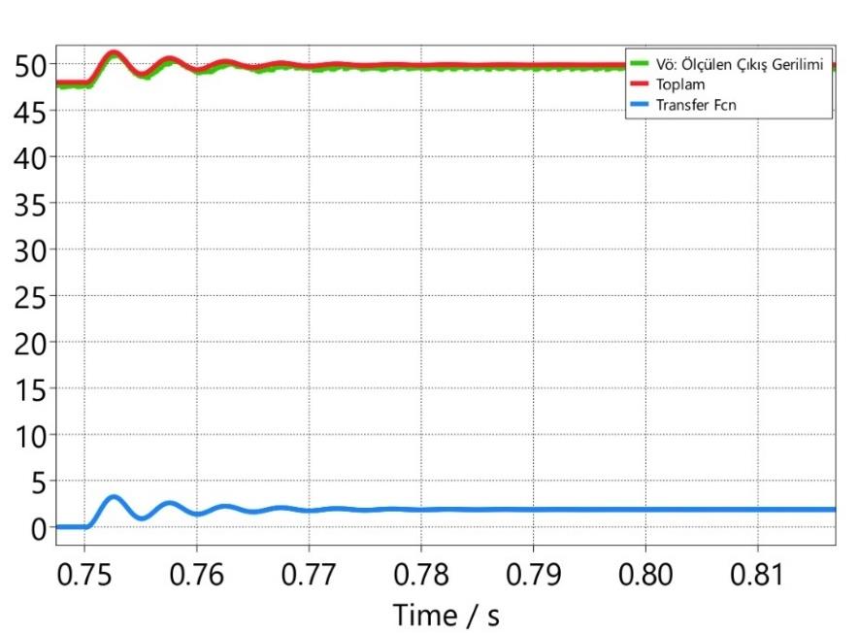
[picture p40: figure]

Şekil 4.8: Yükseltici gerçek sistemi ile elde edilen Transfer Fonksiyonu karşılaştırılması

Bulunan küçük sinyal transfer fonksiyonu önem taşır. Bulunan transfer fonksiyonu eğer

system ile aynı davranmıyorsa o zaman o transfer fonksiyon doğru olmadığı anlamına

gelmektedir. Aynı şekilde diğer bulunacak Kp ve Ki değerlerinin sisteme doğru etki

etmeyceği anlaşılır. Dolayısıyla küçük sinyal transfer fonksiyonu ile gerçek sistemin

karşılaştırılaması yapıldı.

Şekil 4.9:Yükseltici Modu Yük Gerilimi

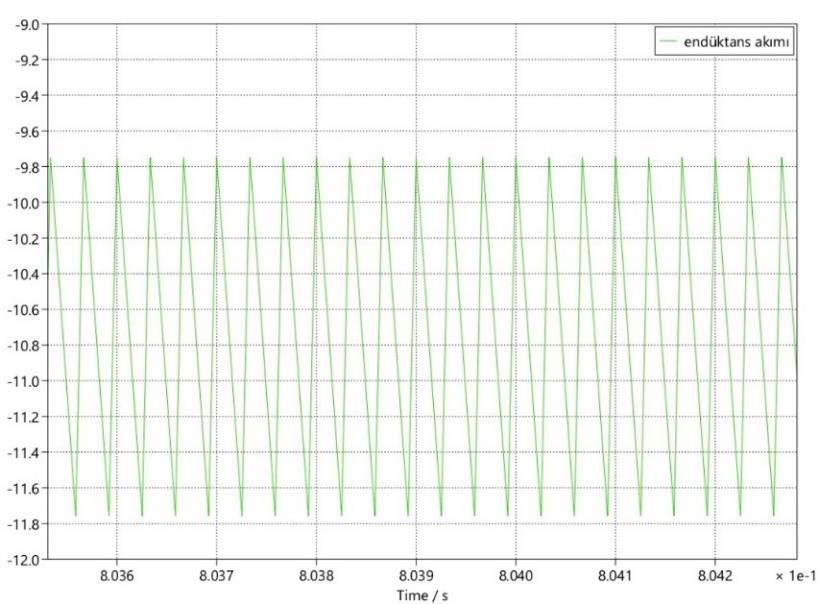
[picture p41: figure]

Şekil 4.10: Düşürücü Modu Endüktans Akımı

Sistemin transfer fonksiyonu ile örtüşüp örtüşmediğinden ardından yük gerilimi ve

endüktans akımının ripple değerlerine bakıldı. Endüktans akımının daha önce

hesaplanan endüktans değerine göre sürekliliğine bakıldı.

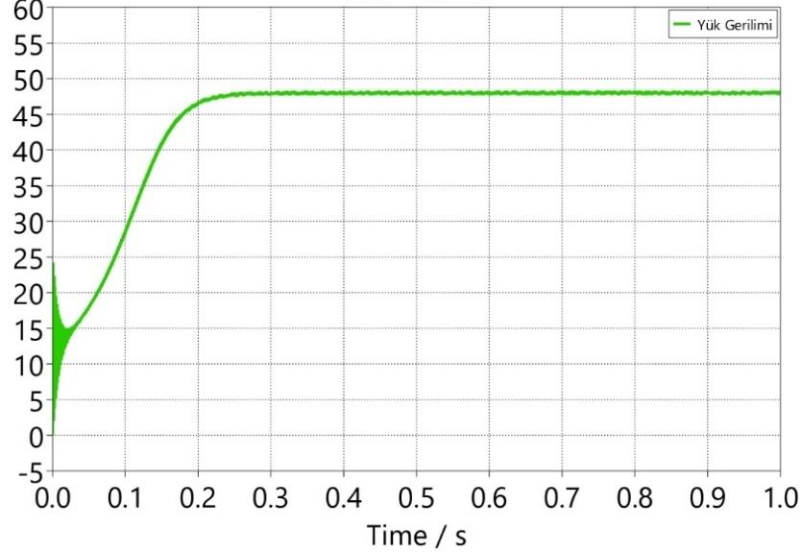
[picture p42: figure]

Şekil 4.11: PI Denetleyici kullanılarak Yükseltici Modu Yük Gerilimi

Simülasyon ortamında gerçekleşen devre için ayrıca bir PI denetleyici tasarlandı.

Daha önce açık döngü ileri yol transfer fonksiyonu Bode diyagramından faz ve kazanç

marjinine bakarak seçilen Kp ve Ki katsayıları bu PI denetleyicisinin katsayıları

olarak kullanıldı. Bu sayede bu katsayılar kullanılarak sistemin çalışma kararlılığı

kontrol edildi.

### 5. ÇALIŞMANIN ETKİLERİ VE SORUMLULUKLARI

### 5.1. Mühendislik Uygulamalarının Etkileri

Bu tez çalışması kapsamında tasarlanan 48V–12V çift yönlü DA-DA dönüştürücü,

yalnızca bir güç elektroniği devresi olmanın ötesinde, otomotiv endüstrisinin

elektrifikasyon sürecine, enerji verimliliğinin artırılmasına ve sürdürülebilir ulaşım

hedeflerine doğrudan katkı sağlayan stratejik bir mühendislik çözümüdür. Mild-hibrit

elektrikli araç (MHEV) mimarilerinin temel bileşenlerinden biri olan bu sistem hem

çevresel hem de ekonomik ve toplumsal boyutlarıyla geniş ölçekli etkilere sahiptir.

Çevresel etkiler açısından değerlendirildiğinde, küresel iklim değişikliğiyle mücadelede

ulaşım kaynaklı karbon emisyonlarının azaltılması kritik bir gereklilik olarak öne

çıkmaktadır. Tasarlanan çift yönlü dönüştürücü, start-stop ve elektrik destekli kalkış

fonksiyonlarını mümkün kılarak içten yanmalı motorun özellikle şehir içi dur-kalk

trafiğinde daha az çalışmasını sağlamaktadır. Bu sayede fosil yakıt tüketimi ve CO₂

emisyonlarında yaklaşık %15–%20 oranında azalma elde edilmekte, şehir havasının

kalitesi iyileştirilmektedir. Ayrıca dönüştürücünün çift yönlü yapısı sayesinde

rejeneratif frenleme sırasında açığa çıkan kinetik enerji elektriksel enerjiye

dönüştürülerek 48V bataryada depolanabilmekte, böylece enerji geri kazanımı

sağlanarak sistem genelinde verimlilik artırılmaktadır. Bu yönüyle çalışma, Birleşmiş

Milletler Sürdürülebilir Kalkınma Amaçları arasında yer alan “Erişilebilir ve Temiz Enerji” (SDG 7) ve “İklim Eylemi” (SDG 13) hedefleriyle doğrudan örtüşmektedir.

Ekonomik açıdan bakıldığında, tam elektrikli araçlara geçiş sürecinde karşılaşılan

yüksek batarya maliyetleri ve yetersiz şarj altyapısı önemli bir engel oluşturmaktadır.

Mild-hibrit sistemler ise mevcut içten yanmalı motor altyapısını koruyarak çok daha

düşük maliyetlerle elektrifikasyon imkânı sunmaktadır. Bu kapsamda geliştirilen 48V–

12V dönüştürücü, yüksek voltajlı (400V ve üzeri) sistemlere kıyasla daha güvenli, daha

düşük maliyetli ve sanayiye uyarlanabilir bir alternatif oluşturmaktadır. Projenin

Türkiye’de tasarlanıp üretilebilir nitelikte olması, otomotiv yan sanayisinin katma

değeri yüksek elektronik sistemlere yönelmesini desteklemekte; ithal güç kontrol

üniteleri yerine yerli mühendislik çözümlerinin kullanılmasına olanak tanıyarak cari

açığın azaltılmasına ve Milli Teknoloji Hamlesi hedeflerine katkı sağlamaktadır.

Toplumsal, sağlık ve güvenlik etkileri açısından değerlendirildiğinde, şehir içi trafikte yoğun egzoz gazına maruz kalmanın solunum yolu hastalıklarını artırdığı bilinmektedir.

Bu çalışmada geliştirilen sistemin yaygınlaşmasıyla hibrit araç kullanımının artması,

özellikle NOx ve partikül madde emisyonlarının azaltılmasına katkı sağlayarak toplum

sağlığının korunmasına hizmet etmektedir. Bununla birlikte tasarımda dikkate alınan

ISO 26262 Fonksiyonel Güvenlik ve LV 148 standartları, sistemin aşırı akım, aşırı

gerilim veya kısa devre gibi durumlarda güvenli şekilde devre dışı kalmasını garanti

altına almaktadır.

Son olarak, şehir altyapılarıyla etkileşim açısından değerlendirildiğinde, akıllı şehir

konseptleri enerji verimliliğini esas alan ulaşım sistemlerine ihtiyaç duymaktadır. Bu

çalışma kapsamında geliştirilen dijital kontrollü güç dönüştürücü, araç içi enerji

yönetimini daha akıllı ve izlenebilir hale getirerek gelecekteki araçtan şebekeye (V2G)

ve araçtan altyapıya (V2I) entegrasyonları için uygun bir teknolojik altyapı

sunmaktadır. Bu yönüyle çalışma, yalnızca mevcut otomotiv uygulamalarına değil,

geleceğin akıllı ve sürdürülebilir şehirlerine de katkı sağlayabilecek bir mühendislik

çözümü ortaya koymaktadır.

### 5.2. Etik ve Mühendislik Mesleğinin Hukuksal Sonuçları

Mühendislik, teknik problemlerin çözümünde bilimsel yöntemleri kullanırken,

toplumun güvenliğini, sağlığını ve refahını her şeyin üzerinde tutmayı gerektiren bir

meslektir. Bu tasarım projesi kapsamında geliştirilen Mild-Hibrit DA-DA Dönüştürücü,

bir taşıtın güç aktarma organlarının kritik bir parçası olduğu için, tasarım sürecinde

alınan her karar doğrudan can güvenliği ve çevresel etki potansiyeli taşımaktadır. Bu

doğrultuda çalışma, TMMOB ve IEEE Etik Kuralları çerçevesinde güvenlik,

sürdürülebilirlik ve mesleki dürüstlük ilkeleri gözetilerek yürütülmüştür.

Otomotiv elektroniğinde yapılabilecek hatalı bir tasarım, aracın seyir halindeyken güç

kaybetmesine veya batarya kaynaklı yangınlara yol açarak ciddi hukuksal yaptırımları

beraberinde getirebilir. Bu riskleri minimize etmek ve ürün sorumluluğu (product

liability) ilkesine sadık kalmak amacıyla, tasarım sürecinde ISO 26262 Fonksiyonel

Güvenlik standartları temel alınmıştır. Yazılımsal veya donanımsal bir hata durumunda

sistemin kendini güvenli bir şekilde kapatmasını (Fail-Safe) sağlayan koruma

mekanizmaları devreye alınmış; tasarımın LV 148 ve CISPR 25 gibi uluslararası kabul

görmüş standartlara uygunluğu sağlanarak, olası kaza durumlarında mühendislik ihmali riskinin önüne geçilmesi hedeflenmiştir.

Çevre etiği ve sürdürülebilirlik bağlamında ise mühendislerin doğal kaynakları koruma

sorumluluğu dikkate alınmıştır. Projede kullanılan MOSFET, kontrolcü ve PCB gibi

tüm elektronik bileşenlerin seçiminde, insan sağlığına ve doğaya zararlı olan Kurşun

(Pb), Cıva (Hg) ve Kadmiyum (Cd) gibi maddeleri kısıtlayan RoHS (Restriction of

Hazardous Substances) direktiflerine tam uyum sağlanmış, lehimleme işlemlerinde

kurşunsuz alaşımlar tercih edilmiştir. Ayrıca, tasarlanan ürünün kullanım ömrünü

tamamladığında elektronik atık (WEEE) yönetmeliklerine uygun olarak geri

dönüştürülebilir malzemelerden oluşmasına ve yüksek verimlilikle çalışarak dolaylı

karbon emisyonunu en aza indirmesine özen gösterilmiştir.

Son olarak, mühendislik etiğinin temeli olan dürüstlük ve şeffaflık ilkeleri gereği;

çalışmada elde edilen test sonuçları, verimlilik grafikleri ve simülasyon verileri

herhangi bir manipülasyona uğratılmadan rapora yansıtılmıştır. Tasarım sürecinde

yararlanılan referans tasarımlar ve akademik kaynaklar, fikri mülkiyet haklarına saygı

çerçevesinde eksiksiz olarak atıflandırılarak intihalden kaçınılmıştır. Tasarlanan

sistemin performans limitleri ve güvenli çalışma aralıkları şeffaf bir şekilde beyan

edilerek, kullanıcıyı yanıltabilecek abartılı iddialardan uzak, güvenilir bir mühendislik

çalışması ortaya konmuştur.

### 6. SONUÇLAR

### 6.1. Genel Açıklamalar

Dört anahtarlı çift yönlü DA-DA dönüştürücü devresi, PLECS ortamında modellenmiş

ve hem buck (48V→12V) hem de boost (12V→48V) çalışma modları ayrı ayrı test

edilmiştir. Devrede kullanılan anahtarlama elemanları, endüktör ve kapasitör değerleri

teorik hesaplamalara göre seçilmiş, her iki yönde de kararlı enerji aktarımı sağlanmıştır.

### 6.2. Simülasyon Sonuçları

Şekil 4.1’de esnasında dönüştürücünün buck modunda çalışırken giriş gerilimini 48V’tan

12V’a düşürüldü ve çıkış geriliminin değeri 12.2863V olarak ölçülmüştür. Ayrıca

endüktans akımının rms değerinin 10.3312 A olduğunu gözükmektedir.

Şekil 4.2’de görünen düşürücü gerçek sistemi ile elde edilen küçük sinyal transfer

fonksiyonu karşılaştırılmasından da anlaşıldığı üzere, d(t) değeri t=0.25 saniyesinde elde

edilen transfer fonksiyonu ile gerçek sistem üst üste gelindiği görülüyor. Dolayısıyla elde

edilen transfer fonksiyonunun da doğru olduğu anlaşılmaktadır.

Şekil 4.3’ten çıkış geriliminin ripple değeri 0.35mV’luk bir değer olduğu gözükmektedir.

Çıkış geriliminin rms değeri ise 12.2863V olup çıkış gücün değeri 127.65W değerinde

olduğu fark edilmektedir. Ayrıca seşkil 4.4’te endüktans akımının yaklaşık 2A’lik bir

ripple değerine sahip olduğu gözükmekte. Ayrıca endüktans akımı hesaplanan endüktans

değerine göre sürekli olacağı görülmüştür.

Yapılan tasarımda PI denetletleyici de kullanıldı. Kp ve Ki değerleri açık döngünün faz

ve kazanç marjini dikkate alınarak seçildi. Kontrol PI denetleyici ile yapıldığında ise şekil

4.6’da görünen yük gerilimi 11.9090V olarak ölçülmüştür. Sistem kararlı çalışacağı

görülmüştür.

Şekil 4.7’da görüldüğü üzere simülasyon esnasında dönüştürücünün boost (yükseltici)

modunda çalışırken gerilimi 12V’tan 48V’a yükseltilmiş ve çıkış geriliminin değeri

49.6725V olarak ölçülmüştür.

Şekil 4.8’den anlaşıldığı üzere, d(t) değeri t=0.75 saniyesinde olduğunda elde edilen

transfer fonksiyonu ile gerçek sistem üst üste geldiği görülüyor. Böylece elde edilen

transfer fonksiyonunun da doğru olduğu anlaşılmaktadır

Şekil 4.9’dan çıkış geriliminin ripple değeri 0.35mV’luk bir değer olduğu gözükmektedir.

Çıkış geriliminin rms değeri ise 49.6725V olup çıkış gücün değeri 127.8647W değerinde

olduğu fark edilmektedir. Şekil 4.10’da ise endüktans akımının yaklaşık 2A’lik bir ripple

değerine sahip olduğu gözükmekte. Endüktans akımının rms değeri ise 10.7676A olarak

ölçülmüştür. Akımın negatif olma sebebi dönüştürücünün çift yönlü olmasından dolayı.

Şekil 6.11’de ise PI denetleyici kullanılarak yük geriliminin 48.183V olacağı ve seçilen

Kp ve Ki katsayılarından dolayı sistemin kararlı çalışacağı görülmüştür.

### 6.3. Değerlendirmeler

Bu çalışmada gerçekleştirilen matematiksel analiz, tasarlanan sistemin teorik

davranışını ortaya koymak, tasarım parametrelerinin sistem performansı üzerindeki

etkilerini öngörebilmek ve simülasyon aşamasında elde edilecek sonuçlar için sağlam bir analitik temel oluşturmak amacıyla yapılmıştır. Özellikle sistemin

kararlılığı, dinamik cevabı ve çalışma noktası etrafındaki davranışı, matematiksel

modelleme yoluyla incelenmiştir.

Analiz sürecinde sistem, fiziksel yapısı ve çalışma prensipleri dikkate alınarak

matematiksel olarak modellenmiştir. Bu kapsamda, ilgili diferansiyel denklemler

oluşturulmuş, gerekli varsayımlar altında sistemin ortalama modeli elde edilmiş ve

küçük işaret yaklaşımı kullanılarak doğrusal bir model türetilmiştir. Elde edilen bu

model üzerinden transfer fonksiyonları çıkarılmış ve sistemin frekans ve zaman

alanındaki davranışı analitik olarak değerlendirilmiştir. Böylece tasarım sırasında

seçilen parametrelerin (örneğin pasif eleman değerleri veya kontrol parametreleri)

sistem performansı üzerindeki etkileri açıkça gözlemlenebilmiştir.

Matematiksel analiz sonucunda elde edilen teorik bulgular, simülasyon ortamında

yapılan çalışmalarla karşılaştırılmıştır. Simülasyon sonuçlarının, analitik modelden

elde edilen kararlılık, bant genişliği ve geçici rejim tepkileri ile büyük ölçüde

örtüştüğü görülmüştür. Bu durum, oluşturulan matematiksel modelin sistemi yeterli

doğrulukta temsil ettiğini ve yapılan varsayımların tasarım amacı açısından geçerli

olduğunu göstermektedir. Bu çalışmada, modelin sadeleştirilmesi amacıyla bazı durumlar göz ardı edilmiştir. Özellikle anahtarlama elemanlarının ideal kabul

edilmesi, parazitik endüktans ve kapasitansların ihmal edilmesi, sıcaklık

değişimlerinin ve bileşen toleranslarının modele dâhil edilmemesi bu kapsamda

değerlendirilebilir. Ayrıca sistemin yalnızca nominal çalışma koşulları altında analiz edilmesi, ani yük değişimleri ve aşırı çalışma senaryolarının detaylı olarak

incelenmemesine neden olmuştur.

Gelecekte yapılabilecek çalışmalarda, bu çalışmada geliştirilen matematiksel model

daha ayrıntılı hâle getirilebilir. Parazitik etkilerin ve anahtarlama kayıplarının

modele eklenmesi, sıcaklık ve yaşlanma etkilerinin incelenmesi ve farklı kontrol

yöntemlerinin karşılaştırılması, sistemin gerçek çalışma koşullarına daha yakın bir

biçimde analiz edilmesini sağlayacaktır. Bunun yanı sıra, deneysel bir prototip

üzerinden elde edilecek ölçüm sonuçlarının matematiksel analiz ve simülasyon

sonuçları ile karşılaştırılması, çalışmanın doğrulanması açısından önemli bir gelişme

olacaktır.

### 7. KAYNAKLAR

[1] ROJAS-DUEÑAS, G. ve ark. 2021. “Modeling of a DC-DC bidirectional converter used in mild hybrid electric vehicles”, Measurement, 183 (4), 109838.
[2] WANG, J. ve ark. 2022. “Review of bidirectional DC–DC converter topologies for EV/HESS”, IET Power Electronics, 15 (14), 1141-1159.
[3] TONG, Y. ve ark. 2022. “Bidirectional DC–DC Converter Topologies for Hybrid Energy Storage Systems in EVs”, IEEE Transactions on Vehicular Technology, 71 (3), 2379-2395.
[4] XU, Q. ve ark. 2021. “Review on Advanced Control Technologies for Bidirectional DC/DC Converters in DC Microgrids”, IEEE Journal of Emerging and Selected Topics in Power Electronics, 9 (2), 1205-1221.
[5] ALAM, M. A. ve ark. 2024. “Isolated bidirectional DC-DC Converter: A topological review”, e-Prime-Advances in Electrical Engineering, Electronics and Energy, 8, 100594.
[6] TULUHONG, A. ve ark. 2023. “Recent Developments in Bidirectional DC-DC Converter Topologies for Electric Vehicle Applications”, Journal of Electrical Engineering, 74 (4), 221-235.
[7] SENGUPTA, A. ve ark. 2022. “Review and Comparative Study of Bi-Directional DC-DC Converters for Hybrid Electric Vehicles”, IEEE Access, 10, 24652-24672.
[8] SUTIKNO, T. ve ark. 2023. “Application of non-isolated bidirectional DC–DC converters for renewable and sustainable energy systems: a review”, Clean Energy, 7 (2), 293–311.
[9] RAO, K. V. G. ve ark. 2021. “Design of a bidirectional DC/DC converter for a hybrid energy storage system in EV”, International Journal of Power Electronics and Drive System (IJPEDS), 12 (1), 405-415.
[10] KUMAR, N. ve ark. 2023. “Controller design and performance study of DC–DC bidirectional converter for hybrid energy storage systems in DC microgrids”, International Journal of Circuit Theory and Applications, 51 (1), 448–466.

### 8. EKLER

EK-1 STANDARTLAR VE KISITLAR FORMU

1. Çalışmanın amacını özetleyiniz.

Bu çalışmanın amacı, mild-hibrit elektrikli araçlarda kullanılan 48V ve 12V batarya

sistemleri arasında çift yönlü enerji transferini sağlayabilen; yüksek verimli, güvenli ve

dijital kontrollü bir DA-DA güç dönüştürücü tasarlamaktır. Proje, 48V bataryadan 12V

sistemlere güç aktarımı (Buck modu) ve rejeneratif frenleme gibi durumlarda 12V'tan

48V'a enerji geri kazanımı (Boost modu) sağlamayı, böylece araç yakıt tüketimini ve

emisyonları azaltmayı hedeflemektedir.

2. Çalışmanın tasarım boyutunu açıklayınız.

Bu çalışma, "Elektrik-Elektronik Mühendisliği Tasarımı" kapsamında ele alınan özgün

bir tasarım projesidir. Mevcut bir projenin tekrarı olmayıp, literatürdeki analog kontrollü

yapıların eksikliklerini gidermek üzere dijital kontrol mimarisi (UCD3138) üzerine

kurgulanmış yeni bir sistem tasarımıdır. Tasarım süreci; literatür araştırması, topoloji

seçimi (4-Anahtarlı Buck-Boost), bileşen boyutlandırma, matematiksel modelleme,

kontrolcü tasarımı ve simülasyon doğrulamasını kapsamaktadır. Tasarımın tamamı

(%100) proje ekibi tarafından gerçekleştirilmiştir

### 3. Bu çalışmada bir mühendislik problemini kendiniz formüle edip, çözdünüz mü?

Evet. Mild-hibrit araçlardaki çift batarya sistemi arasındaki enerji transferinde yaşanan

verim kayıpları ve analog kontrolün esneklik sorunu bir mühendislik problemi olarak

tanımlanmıştır. Bu probleme çözüm olarak; dört anahtarlı buck-boost topolojisi ve PI

tabanlı dijital kontrol algoritması kullanılarak matematiksel modeller (durum uzay

modelleri) oluşturulmuş ve transfer fonksiyonları çıkarılmıştır. Elde edilen çözüm,

MATLAB ve PLECS ortamlarında simüle edilerek yüksek verim ve düşük dalgalanma

değerleri ile doğrulanmıştır.

### 4. Çalışmada kullandığınız yöntemler nelerdir ve önceki derslerde edindiğiniz

hangi bilgi ve becerileri kullandınız? Açıklayınız.

Çalışmada "Durum Uzay Modellemesi" (State-Space Averaging), "Küçük Sinyal

Analizi" ve "Frekans Tepkisi Analizi (Bode Diyagramı)" yöntemleri kullanılmıştır.

- Güç Elektroniği: Dönüştürücü topolojilerinin analizi, MOSFET ve bobin

seçimleri, kayıp hesapları.

- Denetim Sistemleri: Sistemin matematiksel modellenmesi, kararlılık analizi, PI

denetleyici tasarımı ve transfer fonksiyonlarının çıkarılması.

- Elektronik I/II, Elektrik Devreleri I/II: Op-amp ile akım/gerilim okuma

devreleri ve MOSFET sürücü devrelerinin tasarımı.

- Mikroişlemciler / Sayısal Devre Tasarımı: Dijital kontrol algoritmasının

(UCD3138) akış diyagramının oluşturulması ve ADC/PWM modüllerinin

konfigürasyonu.
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

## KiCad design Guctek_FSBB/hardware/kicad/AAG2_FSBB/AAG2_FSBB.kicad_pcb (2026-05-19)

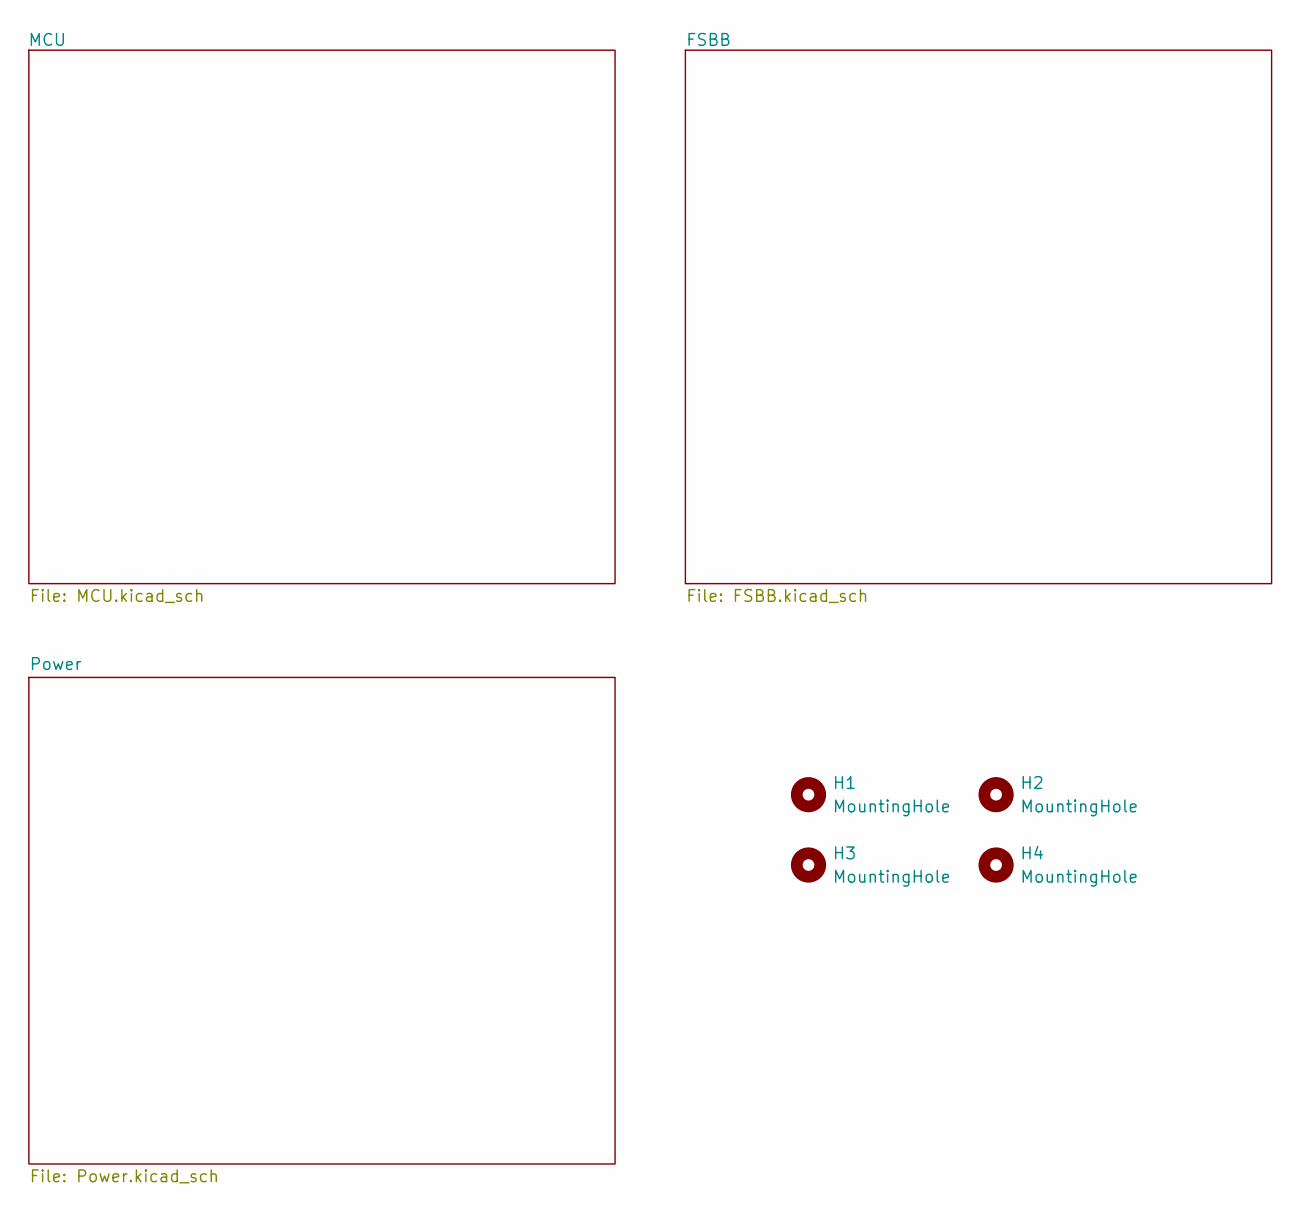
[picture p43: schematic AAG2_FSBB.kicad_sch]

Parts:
H1, H2, H3, H4: MountingHole; MountingHole_2.5mm_Pad

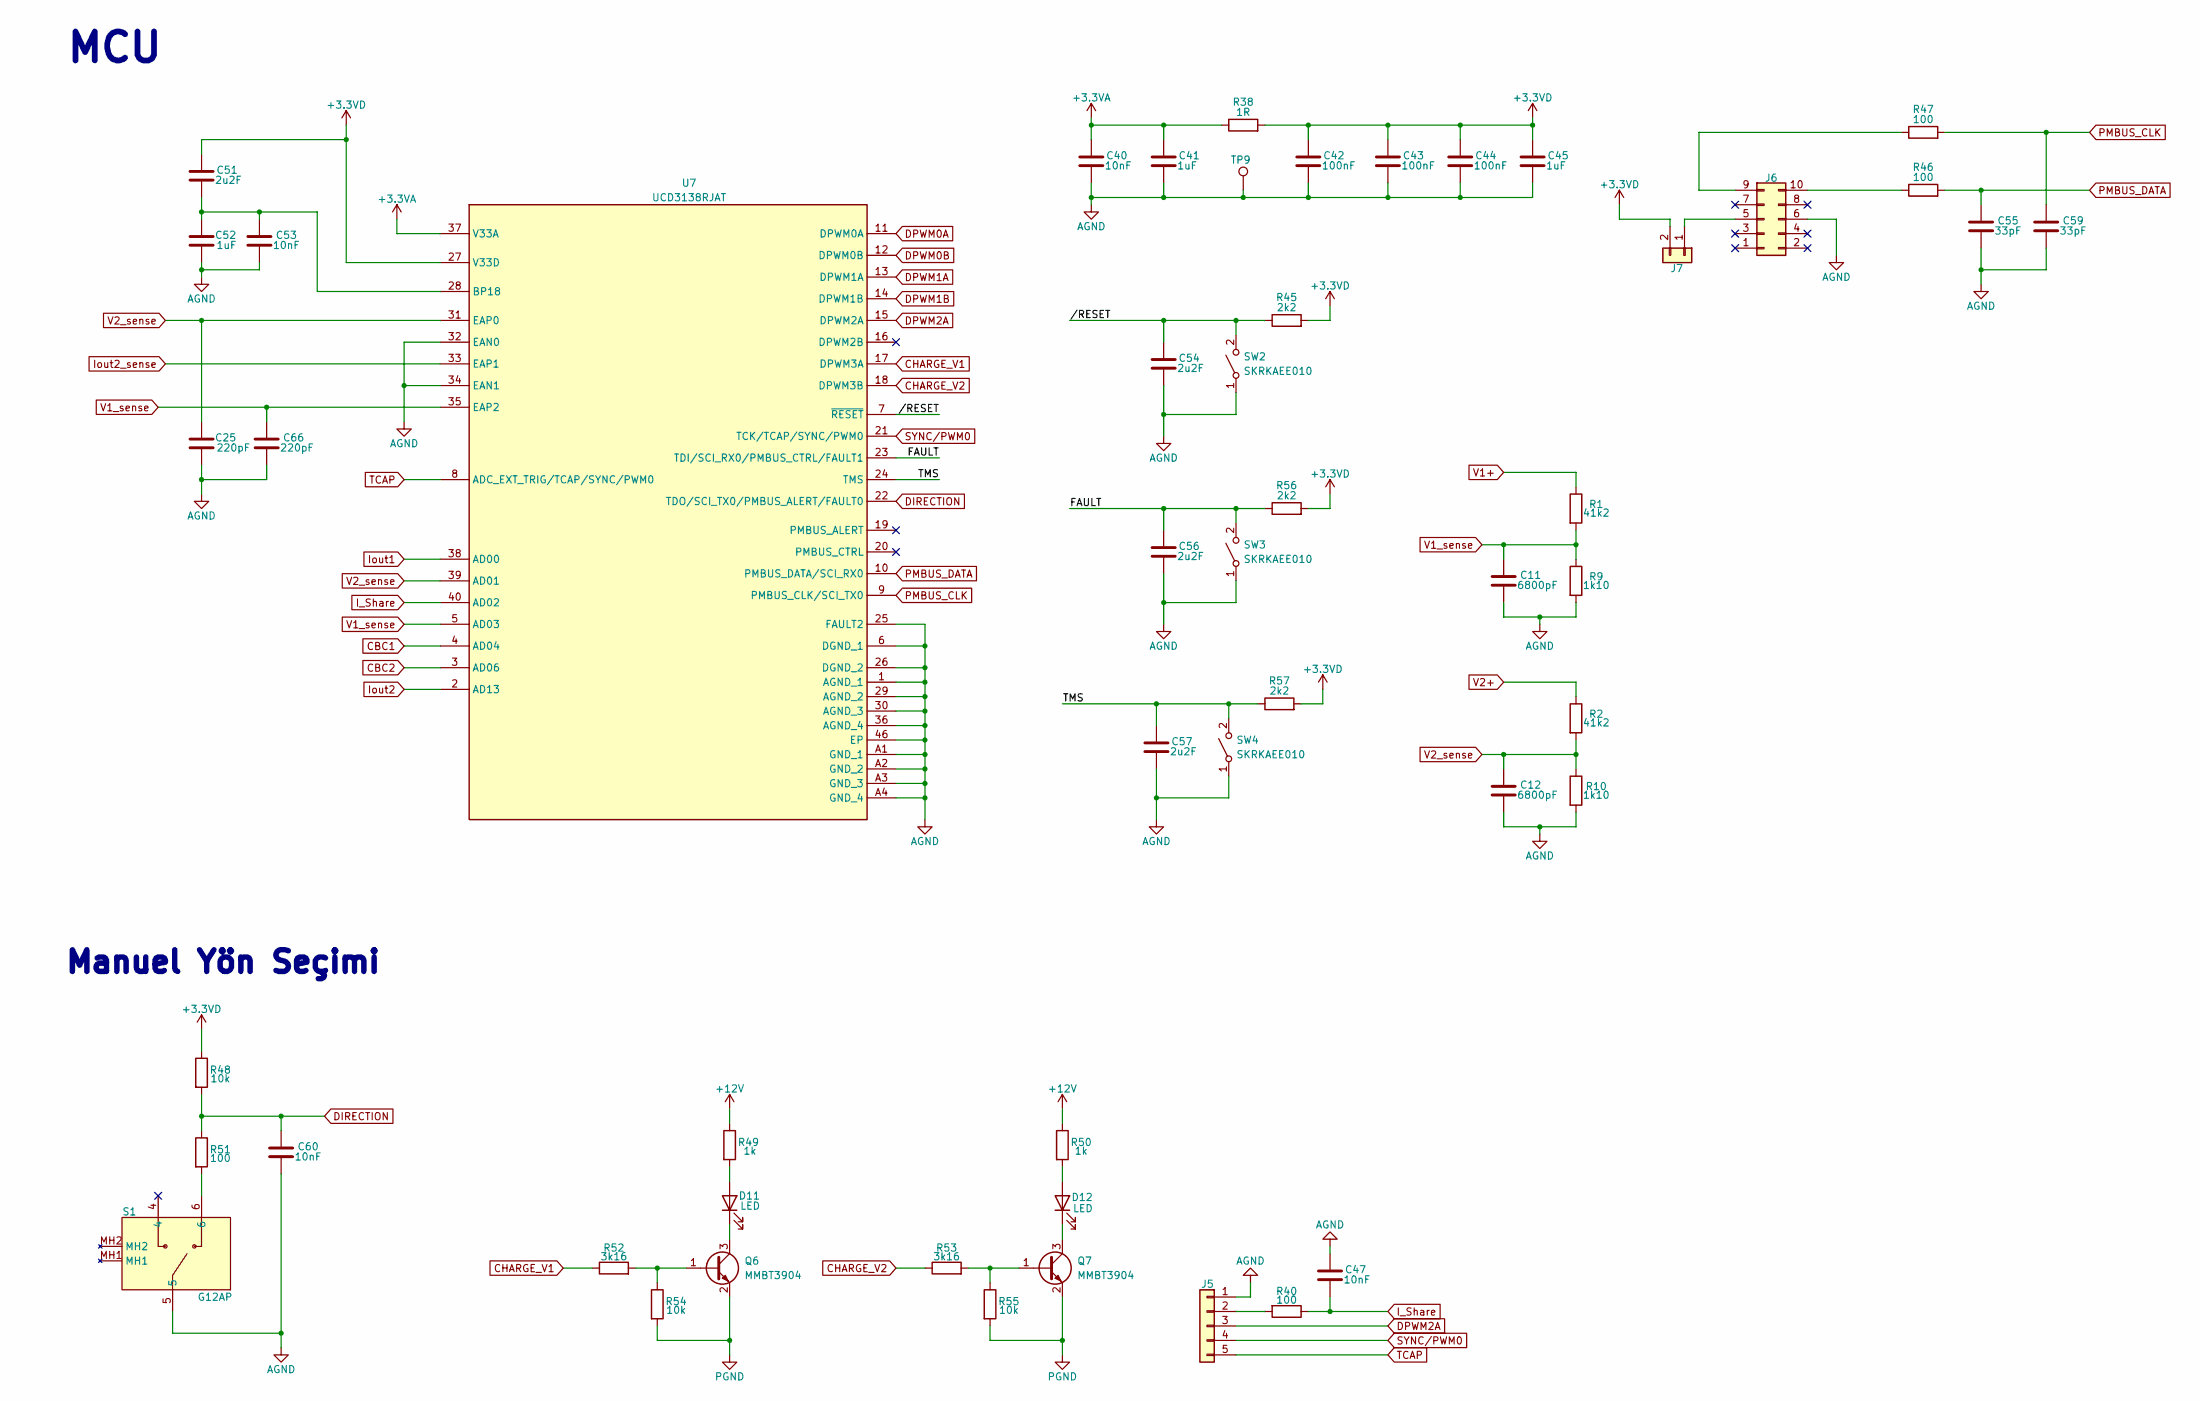
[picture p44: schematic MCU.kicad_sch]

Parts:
C11, C12: 6800pF; C_0603_1608Metric
C25, C66: 220pF; C_0603_1608Metric
C40, C47, C53, C60: 10nF; C_0603_1608Metric
C41, C45, C52: 1uF; C_0603_1608Metric
C42, C43, C44: 100nF; C_0603_1608Metric
C51, C54, C56, C57: 2u2F; C_0603_1608Metric
C55, C59: 33pF; C_0603_1608Metric
D11, D12: LED; LED_0805_2012Metric
J5: Conn_01x05; PinHeader_1x05_P1.00mm_Vertical
J6: 5103308-1
J7: Conn_01x02; PinHeader_01x02_P2.54mm_Vertical_THT_D1mm
Q6, Q7: MMBT3904; SOT-23
R1, R2: 41k2; R_0603_1608Metric
R9, R10: 1k10; R_0603_1608Metric
R38: 1R; R_0603_1608Metric
R40, R46, R47, R51: 100; R_0603_1608Metric
R45, R56, R57: 2k2; R_0603_1608Metric
R48, R54, R55: 10k; R_0603_1608Metric
R49, R50: 1k; R_0603_1608Metric
R52, R53: 3k16; R_0603_1608Metric
S1: G12AP; Manufacturer_Part_Number G12AP; Mouser Part Number 633-G12AP
SW2, SW3, SW4: SKRKAEE010
TP9: TestPoint; TestPoint_Pad_1.0x1.0mm
U7: UCD3138RJAT; Manufacturer_Part_Number UCD3138RJAT; Mouser Part Number 595-UCD3138RJAT

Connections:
+3.3VA: C40.1, C41.1, R38.1, U7.37 (V33A)
+3.3VD: C42.1, C43.1, C44.1, C45.1, C51.1, J7.2, R38.2, R45.2, R48.1, R56.2, R57.2, U7.27 (V33D); also elsewhere on the board
+12V: R49.1, R50.1; also elsewhere on the board
/MCU/FAULT: C56.1, R56.1, SW3.2 (B), U7.23 (TDI/SCI_RX0/PMBUS_CTRL/FAULT1)
/MCU/TMS: C57.1, R57.1, SW4.2 (B), U7.24 (TMS)
/MCU//RESET: C54.1, R45.1, SW2.2 (B), U7.7 (~RESET)
AGND: C11.2, C12.2, C25.2, C40.2, C41.2, C42.2, C43.2, C44.2, C45.2, C47.1, C52.2, C53.2, C54.2, C55.2, C56.2, C57.2, C59.2, C60.2, C66.2, J5.1, J6.6, R9.2, R10.2, S1.5, SW2.1 (A), SW3.1 (A), SW4.1 (A), TP9.1, U7.1 (AGND_1), U7.6 (DGND_1), U7.25 (FAULT2), U7.26 (DGND_2), U7.29 (AGND_2), U7.30 (AGND_3), U7.32 (EAN0), U7.34 (EAN1), U7.36 (AGND_4), U7.46 (EP), U7.A1 (GND_1), U7.A2 (GND_2), U7.A3 (GND_3), U7.A4 (GND_4); also elsewhere on the board
CBC1: U7.4 (AD04); also elsewhere on the board
CBC2: U7.3 (AD06); also elsewhere on the board
CHARGE_V1: R52.1, U7.17 (DPWM3A)
CHARGE_V2: R53.1, U7.18 (DPWM3B)
DIRECTION: C60.1, R48.2, R51.1, U7.22 (TDO/SCI_TX0/PMBUS_ALERT/FAULT0)
DPWM0A: U7.11 (DPWM0A); also elsewhere on the board
DPWM0B: U7.12 (DPWM0B); also elsewhere on the board
DPWM1A: U7.13 (DPWM1A); also elsewhere on the board
DPWM1B: U7.14 (DPWM1B); also elsewhere on the board
DPWM2A: J5.3, U7.15 (DPWM2A)
I_Share: C47.2, R40.1, U7.40 (AD02)
Iout1: U7.38 (AD00); also elsewhere on the board
Iout2: U7.2 (AD13); also elsewhere on the board
Iout2_sense: U7.33 (EAP1); also elsewhere on the board
unnamed: D11.2 (A), R49.2
unnamed: D11.1 (K), Q6.3 (C)
unnamed: D12.2 (A), R50.2
unnamed: D12.1 (K), Q7.3 (C)
unnamed: J5.2, R40.2
unnamed: J6.5, J7.1
unnamed: J6.9, R47.1
unnamed: J6.10, R46.1
unnamed: Q6.1 (B), R52.2, R54.1
unnamed: Q7.1 (B), R53.2, R55.1
unnamed: R51.2, S1.6
unnamed: C51.2, C52.1, C53.1, U7.28 (BP18)
PGND: Q6.2 (E), Q7.2 (E), R54.2, R55.2; also elsewhere on the board
PMBUS_CLK: C59.1, R47.2, U7.9 (PMBUS_CLK/SCI_TX0)
PMBUS_DATA: C55.1, R46.2, U7.10 (PMBUS_DATA/SCI_RX0)
SYNC/PWM0: J5.4, U7.21 (TCK/TCAP/SYNC/PWM0)
TCAP: J5.5, U7.8 (ADC_EXT_TRIG/TCAP/SYNC/PWM0)
V1+: R1.1; also elsewhere on the board
V1_sense: C11.1, C66.1, R1.2, R9.1, U7.5 (AD03), U7.35 (EAP2)
V2+: R2.1; also elsewhere on the board
V2_sense: C12.1, C25.1, R2.2, R10.1, U7.31 (EAP0), U7.39 (AD01)

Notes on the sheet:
MCU
Manuel Yön Seçimi

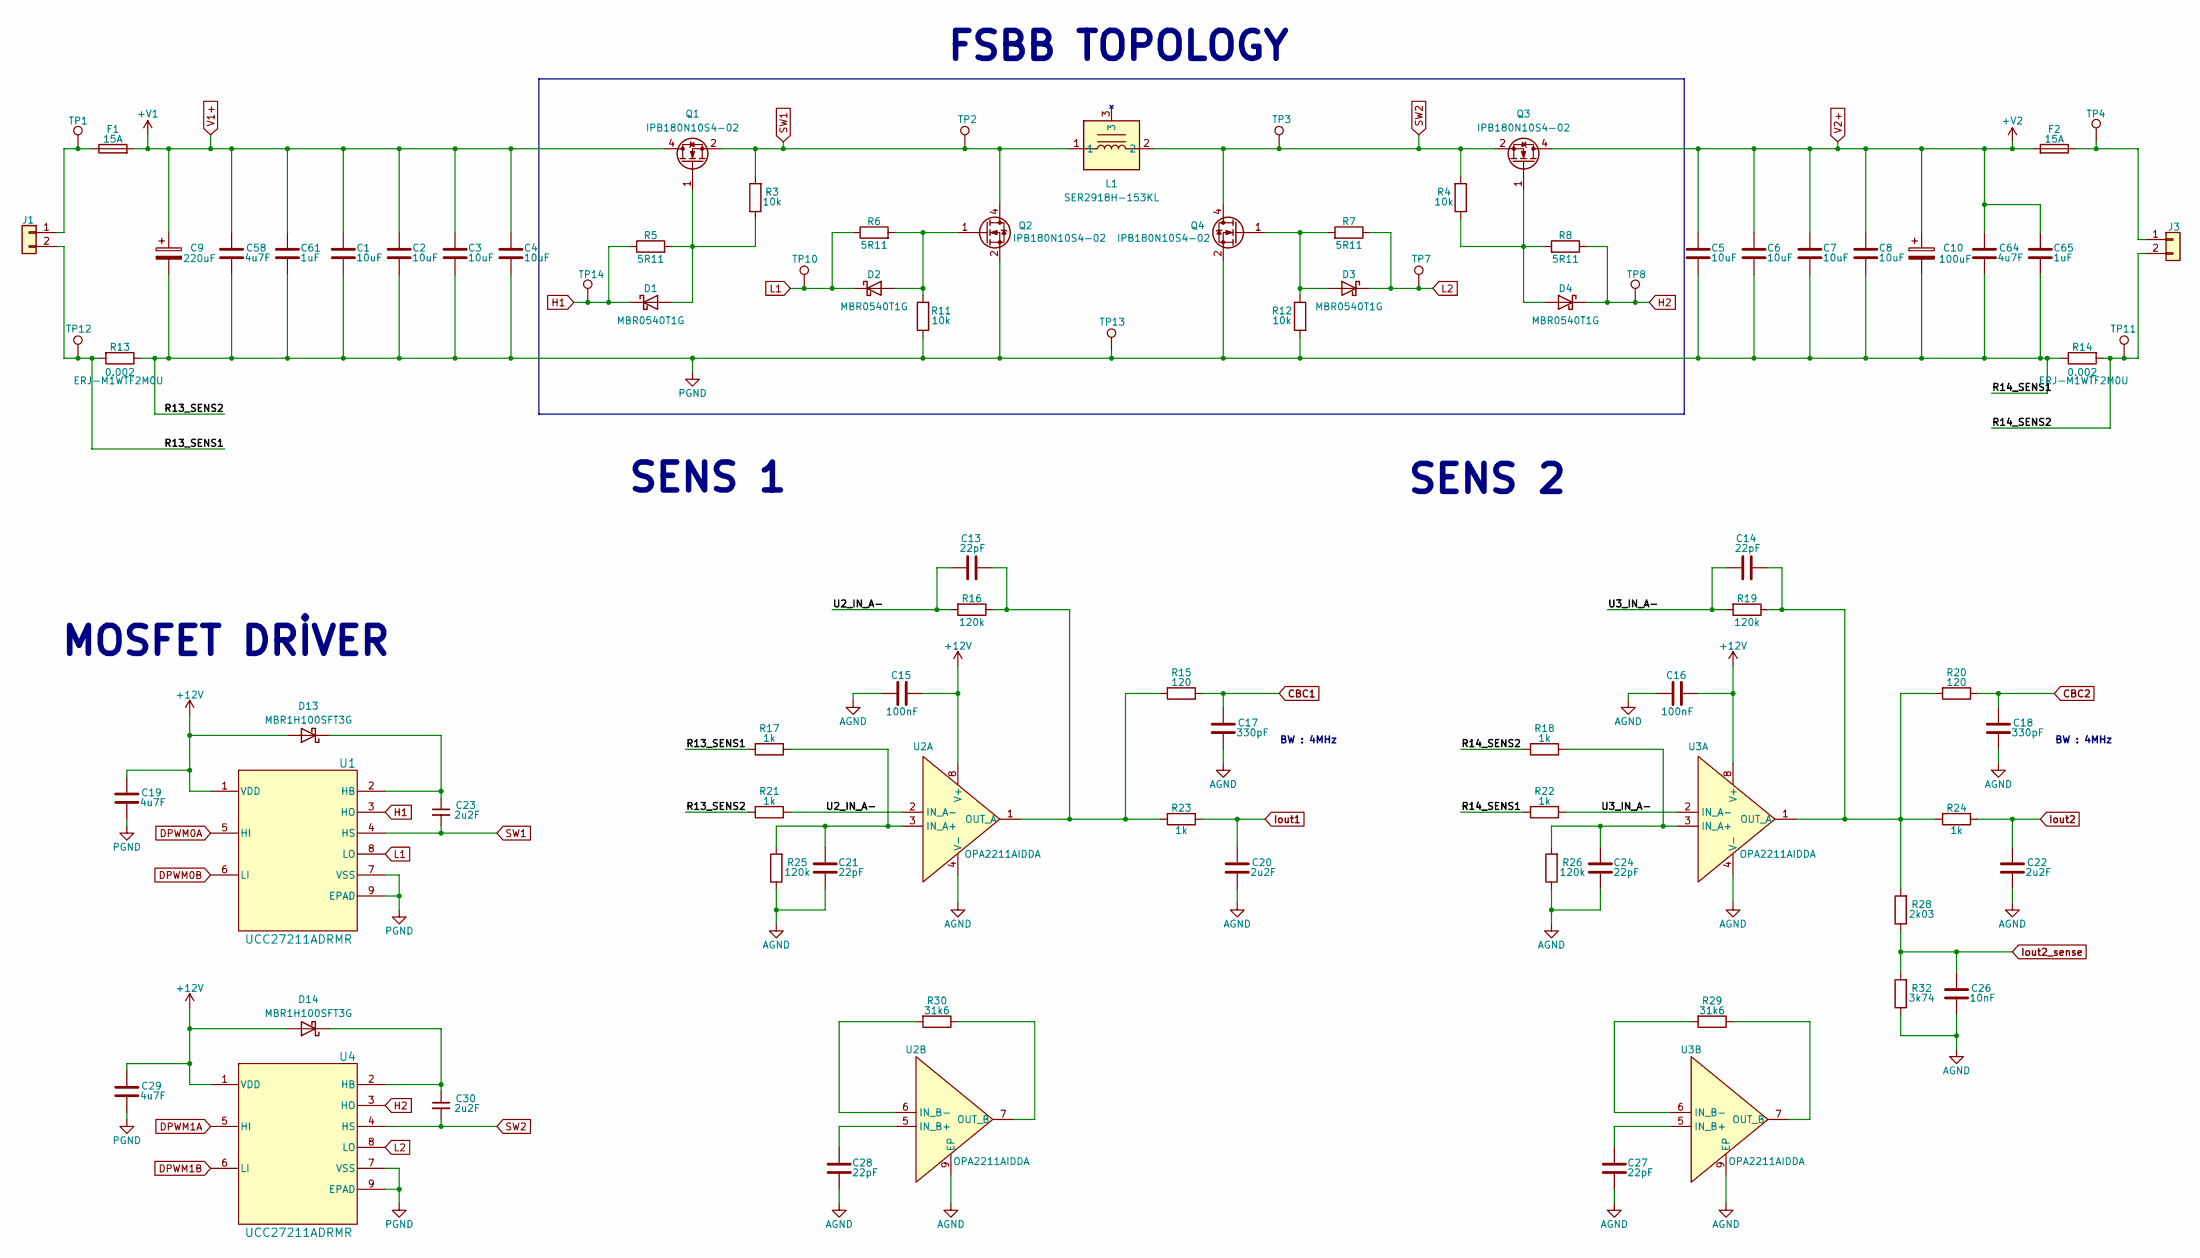
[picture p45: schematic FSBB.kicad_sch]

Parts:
C1, C2, C3, C4, C5, C6, C7, C8: 10uF; C_2220_5750Metric
C9: 220uF; EEEFK0J332AQ
C10: 100uF; CAPAE1300X1380N
C13, C14, C21, C24, C27, C28: 22pF; C_0603_1608Metric
C15, C16: 100nF; C_0603_1608Metric
C17, C18: 330pF; C_0603_1608Metric
C19, C29: 4u7F; C_0805_2012Metric
C20, C22: 2u2F; C_0603_1608Metric
C23, C30: 2u2F; C_1206_3216Metric
C26: 10nF; C_0603_1608Metric
C58, C64: 4u7F; C_1210_3225Metric
C61, C65: 1uF; C_1206_3216Metric
D1, D2, D3, D4: MBR0540T1G; D_SOD-123
D13, D14: MBR1H100SFT3G; SODFL3616X98N
F1, F2: 15A; SS_BEL
J1, J3: Conn_01x02; ED1202DS
L1: SER2918H-153KL; SER2918H333KL; Manufacturer_Part_Number SER2918H-153KL; Mouser Part Number 994-SER2918H-153KL
Q1, Q2, Q3, Q4: IPB180N10S4-02; TO-263-6
R3, R4, R11, R12: 10k; R_0603_1608Metric
R5, R6, R7, R8: 5R11; R_0805_2012Metric
R13, R14: 0.002; R_2512_6332Metric
R15, R20: 120; R_0603_1608Metric
R16, R19, R25, R26: 120k; R_0603_1608Metric
R17, R18, R21, R22, R23, R24: 1k; R_0603_1608Metric
R28: 2k03; R_0603_1608Metric
R29, R30: 31k6; R_0603_1608Metric
R32: 3k74; R_0603_1608Metric
TP1, TP2, TP3, TP4, TP7, TP8, TP10, TP11, TP12, TP13, TP14: TestPoint; TestPoint_Pad_1.0x1.0mm
U1, U4: UCC27211ADRMR; DRM8_3P38X2P45_TEX
U2, U3: OPA2211AIDDA; SOIC127P600X170-9N

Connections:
+12V: C15.2, C16.2, C19.1, C29.1, D13.2 (A), D14.2 (A), U1.1 (VDD), U2.8 (V+), U3.8 (V+), U4.1 (VDD); also elsewhere on the board
/FSBB/R13_SENS1: J1.2, R13.2, R17.2, TP12.1; also elsewhere on the board
/FSBB/R14_SENS2: J3.2, R14.2, R18.2, TP11.1; also elsewhere on the board
/FSBB/U2_IN_A-: C13.1, R16.2, R21.1, U2.2 (IN_A-)
/FSBB/U3_IN_A-: C14.1, R19.2, R22.1, U3.2 (IN_A-)
AGND: C15.1, C16.1, C17.2, C18.2, C20.2, C21.2, C22.2, C24.2, C26.2, C27.2, C28.2, R25.1, R26.1, R32.1, U2.4 (V-), U2.9 (EP), U3.4 (V-), U3.9 (EP); also elsewhere on the board
CBC1: C17.1, R15.1; also elsewhere on the board
CBC2: C18.1, R20.1; also elsewhere on the board
DPWM0A: U1.5 (HI); also elsewhere on the board
DPWM0B: U1.6 (LI); also elsewhere on the board
DPWM1A: U4.5 (HI); also elsewhere on the board
DPWM1B: U4.6 (LI); also elsewhere on the board
H1: D1.1 (K), R5.1, TP14.1, U1.3 (HO); also elsewhere on the board
H2: D4.1 (K), R8.1, TP8.1, U4.3 (HO); also elsewhere on the board
Iout1: C20.1, R23.1; also elsewhere on the board
Iout2: C22.1, R24.1; also elsewhere on the board
Iout2_sense: C26.1, R28.1, R32.2; also elsewhere on the board
L1: D2.1 (K), R6.1, TP10.1, U1.8 (LO); also elsewhere on the board
unnamed: D1.2 (A), Q1.1 (G), R3.1, R5.2
unnamed: D2.2 (A), Q2.1 (G), R6.2, R11.2
unnamed: D3.2 (A), Q4.1 (G), R7.2, R12.2
unnamed: D4.2 (A), Q3.1 (G), R4.1, R8.2
unnamed: C23.1, D13.1 (K), U1.2 (HB)
unnamed: C30.1, D14.1 (K), U4.2 (HB)
unnamed 41: F1.1, J1.1, TP1.1; also elsewhere on the board
unnamed 42: F2.1, J3.1, TP4.1; also elsewhere on the board
unnamed: C21.1, R17.1, R25.2, U2.3 (IN_A+)
unnamed: C13.2, R15.2, R16.1, R23.2, U2.1 (OUT_A)
unnamed: C28.1, U2.5 (IN_B+)
unnamed: R30.2, U2.6 (IN_B-)
unnamed: R30.1, U2.7 (OUT_B)
unnamed: C24.1, R18.1, R26.2, U3.3 (IN_A+)
unnamed: C14.2, R19.1, R20.2, R24.2, R28.2, U3.1 (OUT_A)
unnamed: C27.1, U3.5 (IN_B+)
unnamed: R29.2, U3.6 (IN_B-)
unnamed: R29.1, U3.7 (OUT_B)
PGND: C1.2, C2.2, C3.2, C4.2, C5.2, C6.2, C7.2, C8.2, C9.2, C10.2, C19.2, C29.2, C58.2, C61.2, C64.2, C65.2, Q2.2 (S), Q2.3 (S), Q2.5 (S), Q2.6 (S), Q2.7 (S), Q4.2 (S), Q4.3 (S), Q4.5 (S), Q4.6 (S), Q4.7 (S), R11.1, R12.1, R13.1, R14.1, R21.2, R22.2, TP13.1, U1.7 (VSS), U1.9 (EPAD), U4.7 (VSS), U4.9 (EPAD); also elsewhere on the board
SW1: C23.2, L1.1, Q1.2 (S), Q1.3 (S), Q1.5 (S), Q1.6 (S), Q1.7 (S), Q2.4 (D), R3.2, TP2.1, U1.4 (HS); also elsewhere on the board
SW2: C30.2, L1.2, Q3.2 (S), Q3.3 (S), Q3.5 (S), Q3.6 (S), Q3.7 (S), Q4.4 (D), R4.2, TP3.1, U4.4 (HS); also elsewhere on the board
V1+: C1.1, C2.1, C3.1, C4.1, C9.1, C58.1, C61.1, F1.2, Q1.4 (D); also elsewhere on the board
V2+: C5.1, C6.1, C7.1, C8.1, C10.1, C64.1, C65.1, F2.2, Q3.4 (D); also elsewhere on the board

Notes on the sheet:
SENS 2
BW : 4MHz
SENS 1
MOSFET DRİVER
FSBB TOPOLOGY

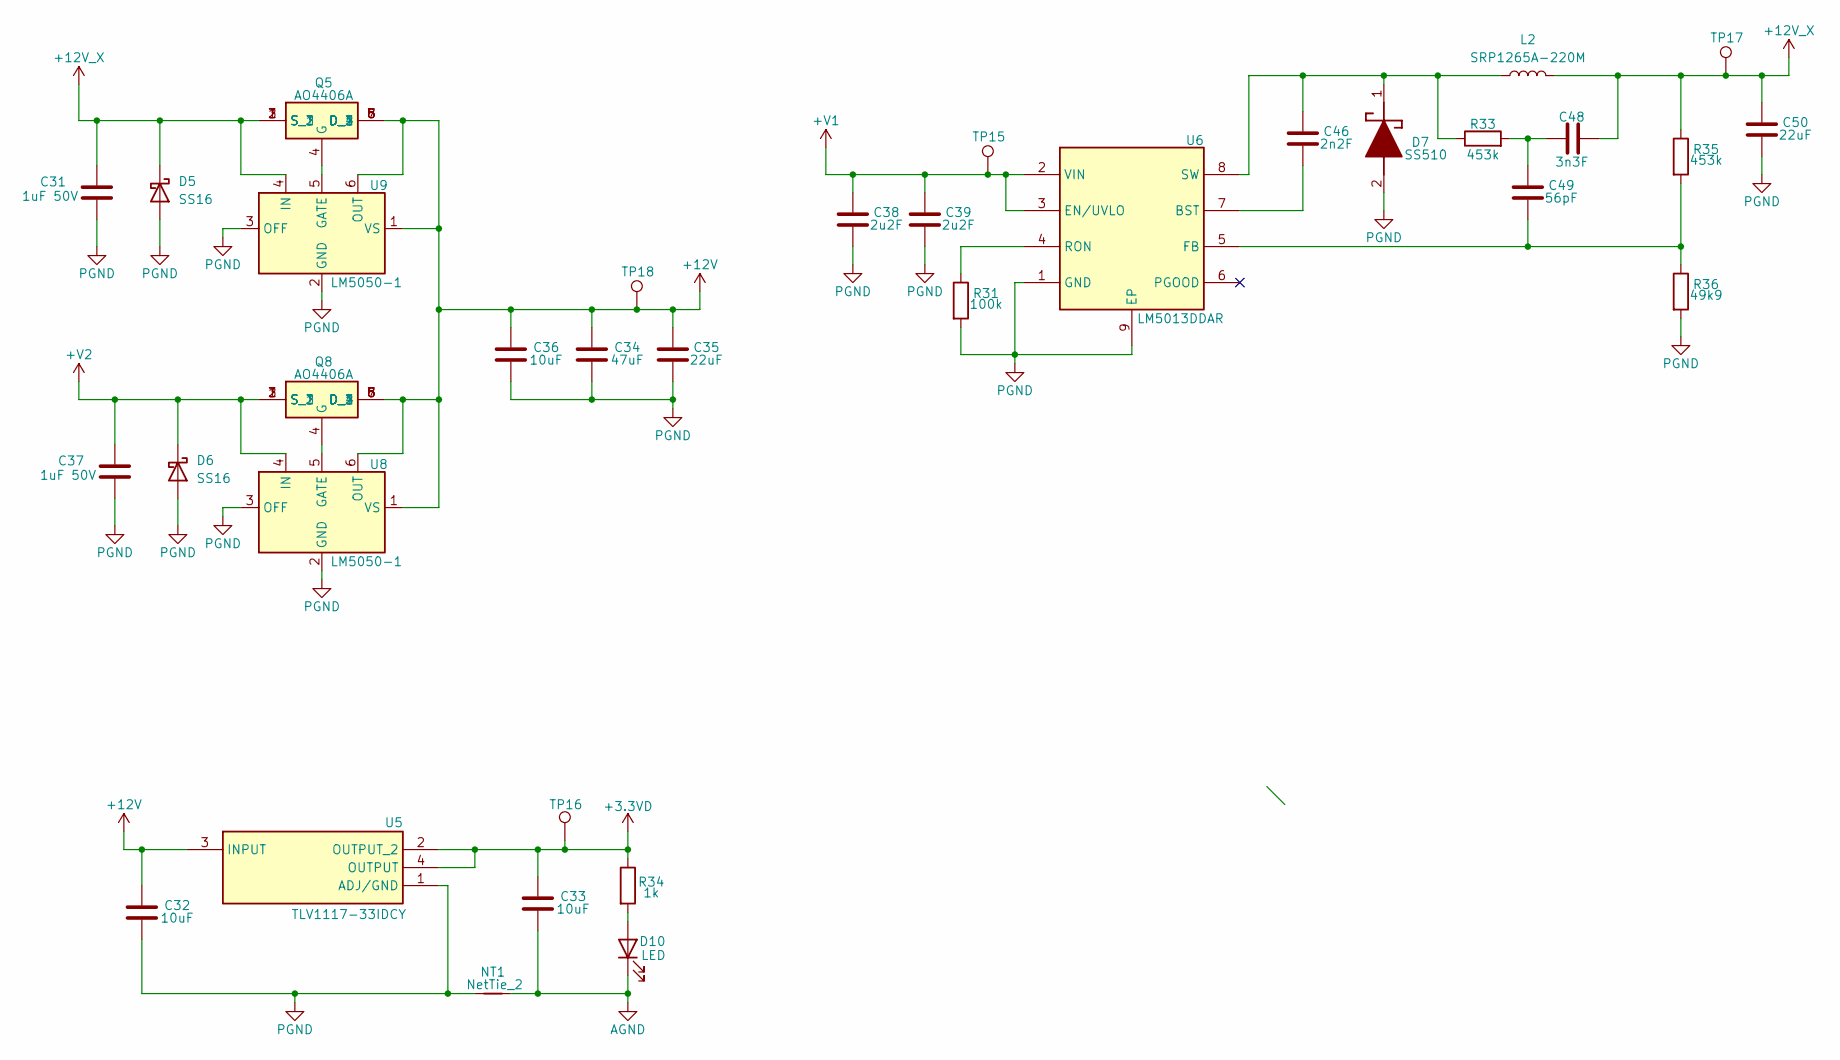
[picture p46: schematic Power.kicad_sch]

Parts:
C31, C37: 1uF 50V; C_0603_1608Metric
C32, C36: 10uF; C_0805_2012Metric
C33: 10uF; C_0603_1608Metric
C34: 47uF; C_0805_2012Metric
C35: 22uF; C_0805_2012Metric
C38, C39: 2u2F; C_1210_3225Metric
C46: 2n2F; C_0603_1608Metric
C48: 3n3F; C_0603_1608Metric
C49: 56pF; C_0603_1608Metric
C50: 22uF; C_1210_3225Metric
D5, D6: SS16; D_SMA
D7: SS510; DIONM7959X262N; Manufacturer_Part_Number SS510
D10: LED; LED_0805_2012Metric
L2: SRP1265A-220M; SRP1265A
NT1: NetTie_2; NetTie-2_SMD_Pad0.5mm
Q5, Q8: AO4406A; SOIC127P600X175-8N; Manufacturer_Part_Number AO4406A; LCSC PART C2944312
R31: 100k; R_0603_1608Metric
R33, R35: 453k; R_0603_1608Metric
R34: 1k; R_0603_1608Metric
R36: 49k9; R_0603_1608Metric
TP15, TP16, TP17, TP18: TestPoint; TestPoint_Pad_1.0x1.0mm
U5: TLV1117-33IDCY; SOT230P700X180-4N; Manufacturer_Part_Number TLV1117-33IDCY; Mouser Part Number 595-TLV1117-33IDCY
U6: LM5013DDAR; SOIC127P600X170-9N; Manufacturer_Part_Number LM5013DDAR; Mouser Part Number 595-LM5013DDAR
U8, U9: LM5050-1; TSOT-23-6; LCSC PART C129323

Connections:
+3.3VD: C33.1, R34.1, TP16.1, U5.2 (OUTPUT_2), U5.4 (OUTPUT); also elsewhere on the board
+12V: C32.1, C34.1, C35.1, C36.1, Q5.5 (D_1), Q5.6 (D_2), Q5.7 (D_3), Q5.8 (D_4), Q8.5 (D_1), Q8.6 (D_2), Q8.7 (D_3), Q8.8 (D_4), TP18.1, U5.3 (INPUT), U8.1 (VS), U8.6 (OUT), U9.1 (VS), U9.6 (OUT); also elsewhere on the board
AGND: C33.2, D10.1 (K), NT1.2; also elsewhere on the board
unnamed: C48.1, C49.1, R33.2
unnamed 33: C46.1, D7.1 (K), L2.2, R33.1, U6.8 (SW); also elsewhere on the board
unnamed: D10.2 (A), R34.2
unnamed: Q5.4 (G), U9.5 (GATE)
unnamed: Q8.4 (G), U8.5 (GATE)
unnamed: C46.2, U6.7 (BST)
unnamed: C49.2, R35.2, R36.1, U6.5 (FB)
unnamed: R31.1, U6.4 (RON)
PGND: C31.2, C32.2, C34.2, C35.2, C36.2, C37.2, C38.2, C39.2, C50.2, D5.2 (A), D6.2 (A), D7.2 (A), NT1.1, R31.2, R36.2, U5.1 (ADJ/GND), U6.1 (GND), U6.9 (EP), U8.2 (GND), U8.3 (OFF), U9.2 (GND), U9.3 (OFF); also elsewhere on the board
V1+: C38.1, C39.1, TP15.1, U6.2 (VIN), U6.3 (EN/UVLO); also elsewhere on the board
V2+: C37.1, D6.1 (K), Q8.1 (S_1), Q8.2 (S_2), Q8.3 (S_3), U8.4 (IN); also elsewhere on the board

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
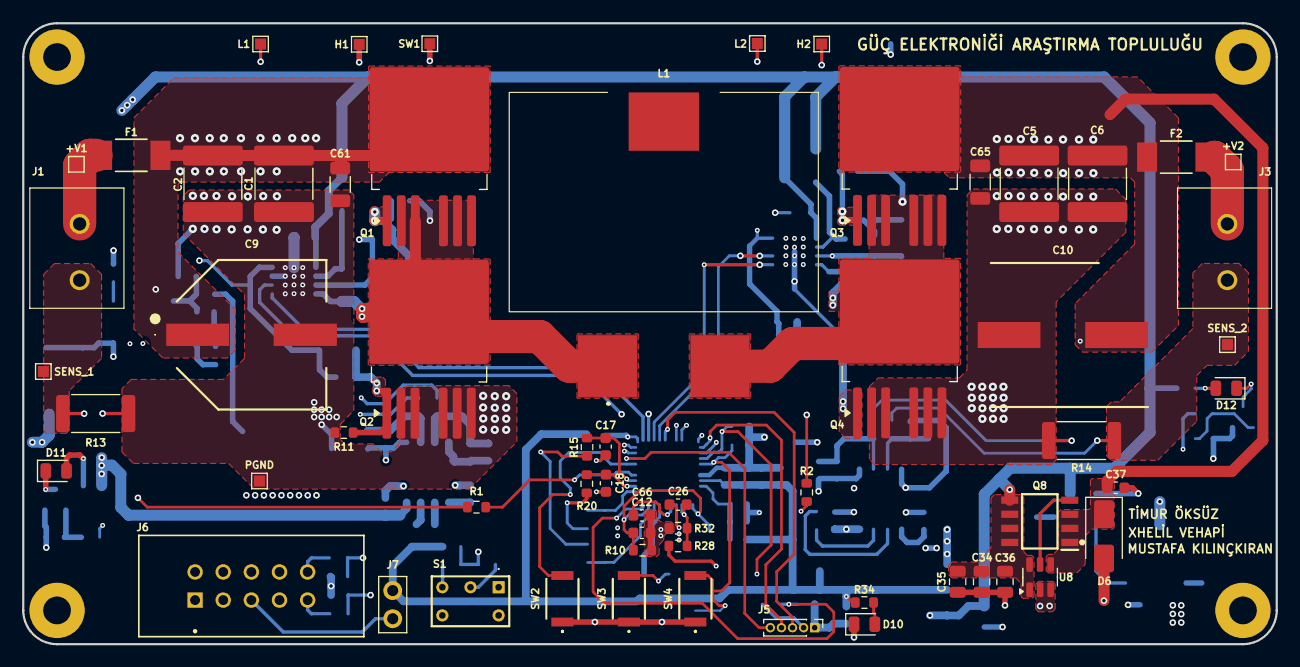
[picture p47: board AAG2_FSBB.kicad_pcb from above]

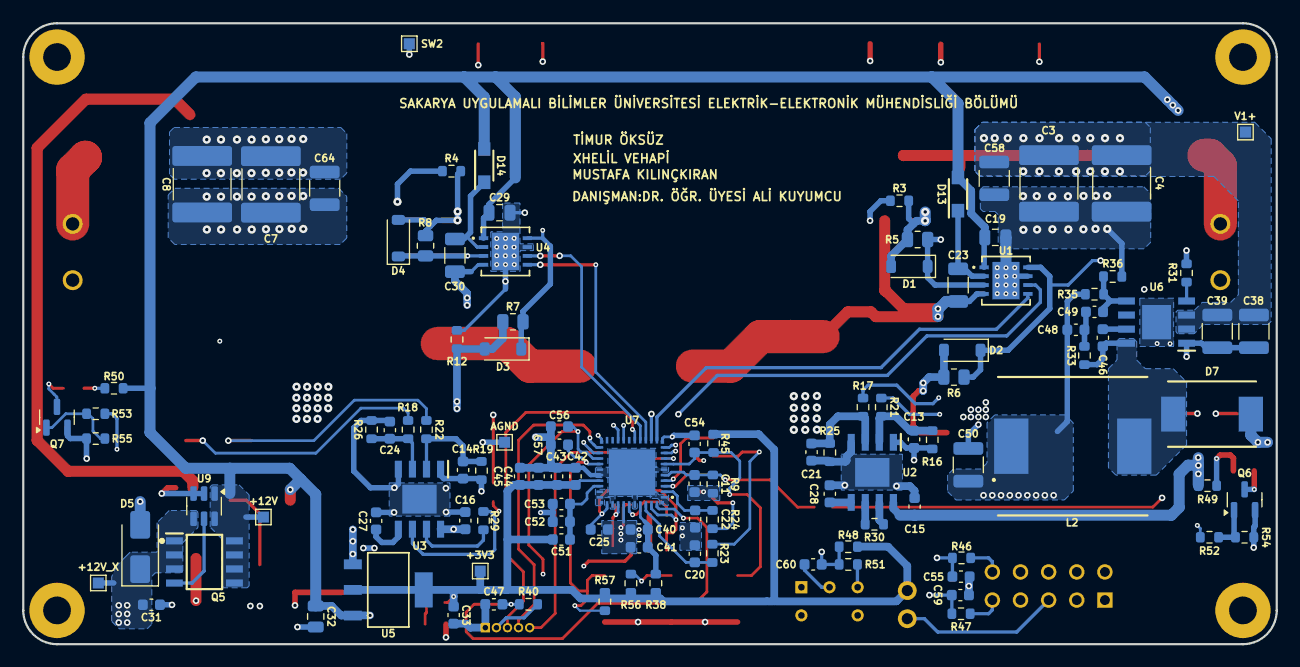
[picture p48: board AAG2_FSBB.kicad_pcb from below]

Board: 4 copper layers, 113.2 x 56.1 mm, 177 parts (113 on the bottom side), 79 nets.

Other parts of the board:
+3V3, +12V, +12V_X: TestPoint; TestPoint_Pad_1.0x1.0mm
+V1, +V2: TestPoint; TestPoint_Pad_1.0x1.0mm
AGND: TestPoint; TestPoint_Pad_1.0x1.0mm
H1#2, H2#2: TestPoint; TestPoint_Pad_1.0x1.0mm
L1#2: TestPoint; TestPoint_Pad_1.0x1.0mm
L2#2: SRP1265A-220M; SRP1265A
PGND: TestPoint; TestPoint_Pad_1.0x1.0mm
SENS_1, SENS_2: TestPoint; TestPoint_Pad_1.0x1.0mm
SW1, SW2#2: TestPoint; TestPoint_Pad_1.0x1.0mm
V1+: TestPoint; TestPoint_Pad_1.0x1.0mm

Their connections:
+3.3VD: +3V3.1; also elsewhere on the board
+12V: +12V.1; also elsewhere on the board
/FSBB/R13_SENS1: SENS_1.1; also elsewhere on the board
/FSBB/R14_SENS2: SENS_2.1; also elsewhere on the board
AGND: AGND.1; also elsewhere on the board
H1: H1#2.1; also elsewhere on the board
H2: H2#2.1; also elsewhere on the board
L1: L1#2.1; also elsewhere on the board
unnamed 33: L2#2.2; also elsewhere on the board
unnamed 41: +V1.1; also elsewhere on the board
unnamed 42: +V2.1; also elsewhere on the board
PGND: PGND.1; also elsewhere on the board
SW1: SW1.1; also elsewhere on the board
SW2: SW2#2.1; also elsewhere on the board
V1+: V1+.1; also elsewhere on the board
